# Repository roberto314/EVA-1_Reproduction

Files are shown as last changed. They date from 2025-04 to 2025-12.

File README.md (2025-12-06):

# EVA-1_Reproduction

Recreation of the very rare K-K Systems EVA-1 Display Adapter for the Epson HX-20 Computer
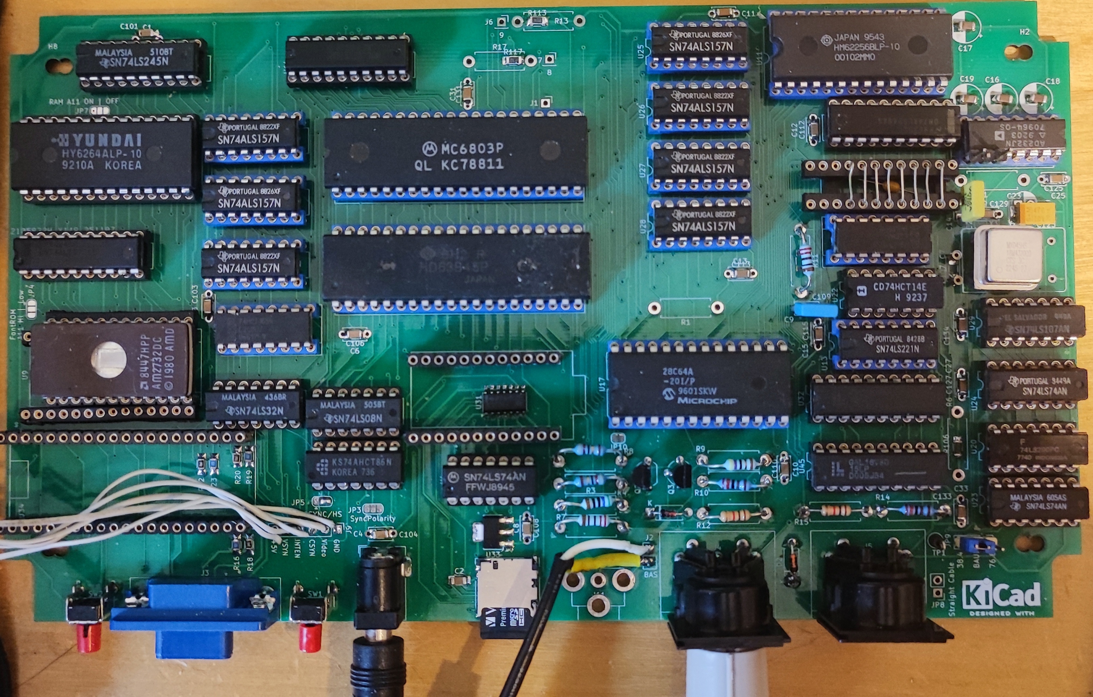
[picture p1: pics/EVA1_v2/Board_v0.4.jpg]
EVA1_v2 Rev.0.4


In the folder disassembly are three versions of the original firmware:

* eva_orig: original firmware 
* eva_enh: enhanced firmware (mostly original)
* eva_ext: extended firmware (8k Text RAM, additional functions)
    - see the .asm file for more comments.

The gal folder contains the equations and .jed file for the GAL.

The monitor folder contains a modified version of Daniel Tufvesson's monitor. This is just for testing.

In the rom folder one can find the original rom and the font rom.

The schematics folder contains different versions of the reverse engineering process.

* EVA1: the original reverse engineered schematic and board (NOT FOR PRODUCTION!)
* EVA1_production: the mostly original EVA1 for production (DRAM does NOT work!)
* EVA86-2: from sources on the internet redrawn schematics of the EVA86 (not complete!)
* EVA1_v2: new version with SRAM as Graphic RAM, Arduino as mass storage and RP2040 for VGA Output.
* EVA1_Frontplatte: a drill template for the Strapubox 5003 case

For the newest Hardware Revision (0.5) use the File "disassembly/eva_ext/rom.bin" for a 28C64 or 27C64 ROM.

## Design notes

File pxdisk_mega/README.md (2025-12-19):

# PFBDK - Arduino Mega simulator of the Epson's Epsp based disk drives

This is my fork of William R. Cooke's PFBDK sketch found at 
http://wrcooke.net/projects/pfbdk/pfbdk.html. PFBDK emulates four floppy drives 
for the Epson PX-4 and PX-8 CP/M portable computers.

Thanks to Robert Offner, the firmware now also supports the Epson HX-20 computer. 

The intend of this project is to add some features to PFBDK making it somewhat more 
convenient to use. The route will be very incremental to keep the basic functionality 
working.

PFBDK on an Arduino Pro Micro in a PETG box

For the Pro Micro a working PCB is created [PDF](PFBDK_promicro.kicad_sch.pdf), 
[KiCAD files](PFBDK_promicro_V1.0.complete.zip).

There are 3D-print files for the case and more pictures on my own page 
at: https://electrickery.nl/comp/tf20/pxdisk/

## HX-20 support

Each HX-20 drive is now a directory on the SD-card; A, B, C and D. The HX-20
requires to files for its Disk-BASIC; BOOT.80 and DBASICnn.SYS. These files 
should be in the root directory of the SD-card (use DBASIC40.SYS for the 16 k HX-20
and DBASIC80.SYS for the HX-20 with the System expansion). 

## Hardware extensions

Both Arduino solutions (there is one for the Mega 2560) support blinking lights 
for the SERIAL line and each (emulated) drive. 

## PFBDK console commands

The first feature is a command line on the debug/console port of the 
Arduino Mega and Pro Micro. The Mega is somewhat more expensive and larger,
but easier to program. For normal operation the two are equal. The usage is now:

	Usage (2.0.0):
 	C                - temp debug for driveNames[][]
 	D                - SD-card root directory
 	H                - this help
 	M[dnnnnnnnn.eee] - mount file nnnnnnnn.eee on drive d
 	Nnnnnnnnn.eee    - create an image file nnnnnnnn.eee
 	P[dw]            - write protect drive d; w=0 RW, w=1 RO
 	R                - temp reset Arduino

Note that most changes made with these tools are not persistent (image 
creation being the exception) and will be lost when switching 
off or resetting the floppy emulator. The default settings are images **D.IMG**, 
**E.IMG**, **F.IMG** and **G.IMG** for the drives and all drives are writable.

### D

The D commands lists only the root directory of the SD card.

### M

The goal of the M-command is to change the images assigned to the 
simulated disk drives D: to G:. 

### N

The N-command creates a new empty image file. It aborts when the image exists. 
This command and the data stored on the image are saved on the SD-card.

### P

The P command emulates the floppy write tabs to write protect the disk.

Another plan was to respect the Read-Only attribute for the image files, 
emulating the floppy write protect, but this attribute is not supported in 
the SDLib library for VFAT disks.

## Control with native PX4 programs

The idea is make most settings controllable from the PX-4/PX-8 with 
custom commands and make settings persistent. After all the PX-4/8 talks to the PFBDK
using the [well documented EPSP protocol](https://electrickery.nl/comp/hx20/doc/SwAsDisAs.pdf), 
and extending the PFBDK firmware with new commands is entirely 
possible. 
For the PX-4 side some user programs can be added, similar in usage as the 
original COPYDISK program. So far only some demos for the
PX-4 are realized. The PX-8 uses another BIOS call, and will be implemented later.
For persistency, no solution is implemented yet, but the simplest
way would probably be to create a CP/M batch file on the RAM disk A: using the 
PF* commands to configure the PFBDK. 

### PFDIR4 - display SD-card root directory

        Usage: PFDIR4 [n]
         n = optional the start directory part 
          (each part is eight entries, ENTER and SPACE gets next part,
           other keys exit program)

### PFMNT4 - mount a SD-card image file to a drive

	  Usage: PFMNT4 [<drive> <name>]
       drive = D, E, F, G.
       name = SD card file image name.

### PFNEW4 - create a new empty image on the SD-card

	  Usage: PFNEW4 <name>'
       name = SD card file image name.

### PFWP4 - manage write protect flag of a drive

      Usage: PFWP4 [<drive> <wp-state>]
       drive = D, E, F, G. 
       wp-state: 0 = read-only, 1 = read/write

## Case

More photo's of the cases and the [3D-printer design files](https://electrickery.nl/comp/tf20/pxdisk/) 
at my main site.

## Extra tech

Creating applications consisting of two computers talking to each other is 
more complex than making just a program. I used this solution to inspect the
traffic between the PX-4 and the PFBDK: https://github.com/electrickery/DualSerialMonitor

fjkraan@electrickery.nl, 2024-12-16

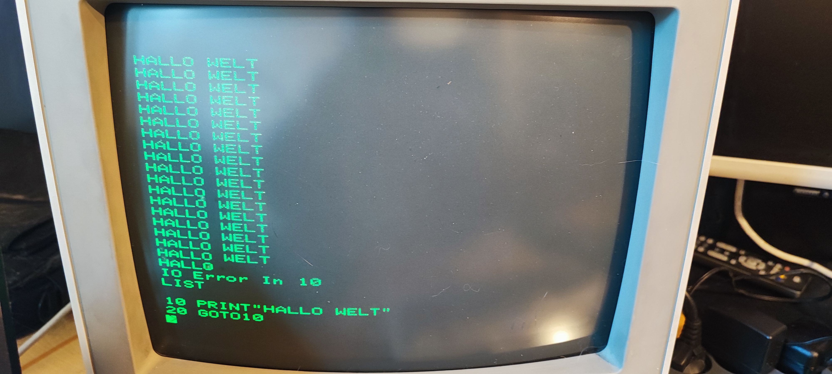
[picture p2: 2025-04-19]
pics/EVA-1_new/EVA_40Z.jpg

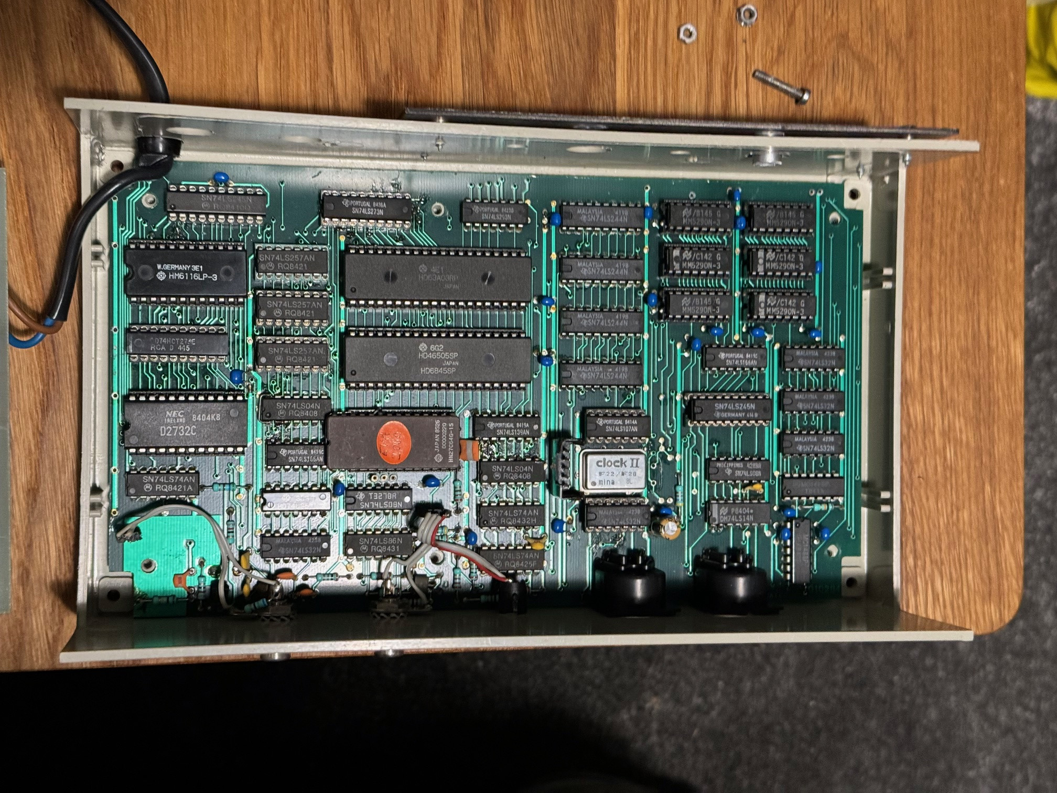
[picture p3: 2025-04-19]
pics/EVA-1_orig/EVA1d.jpg

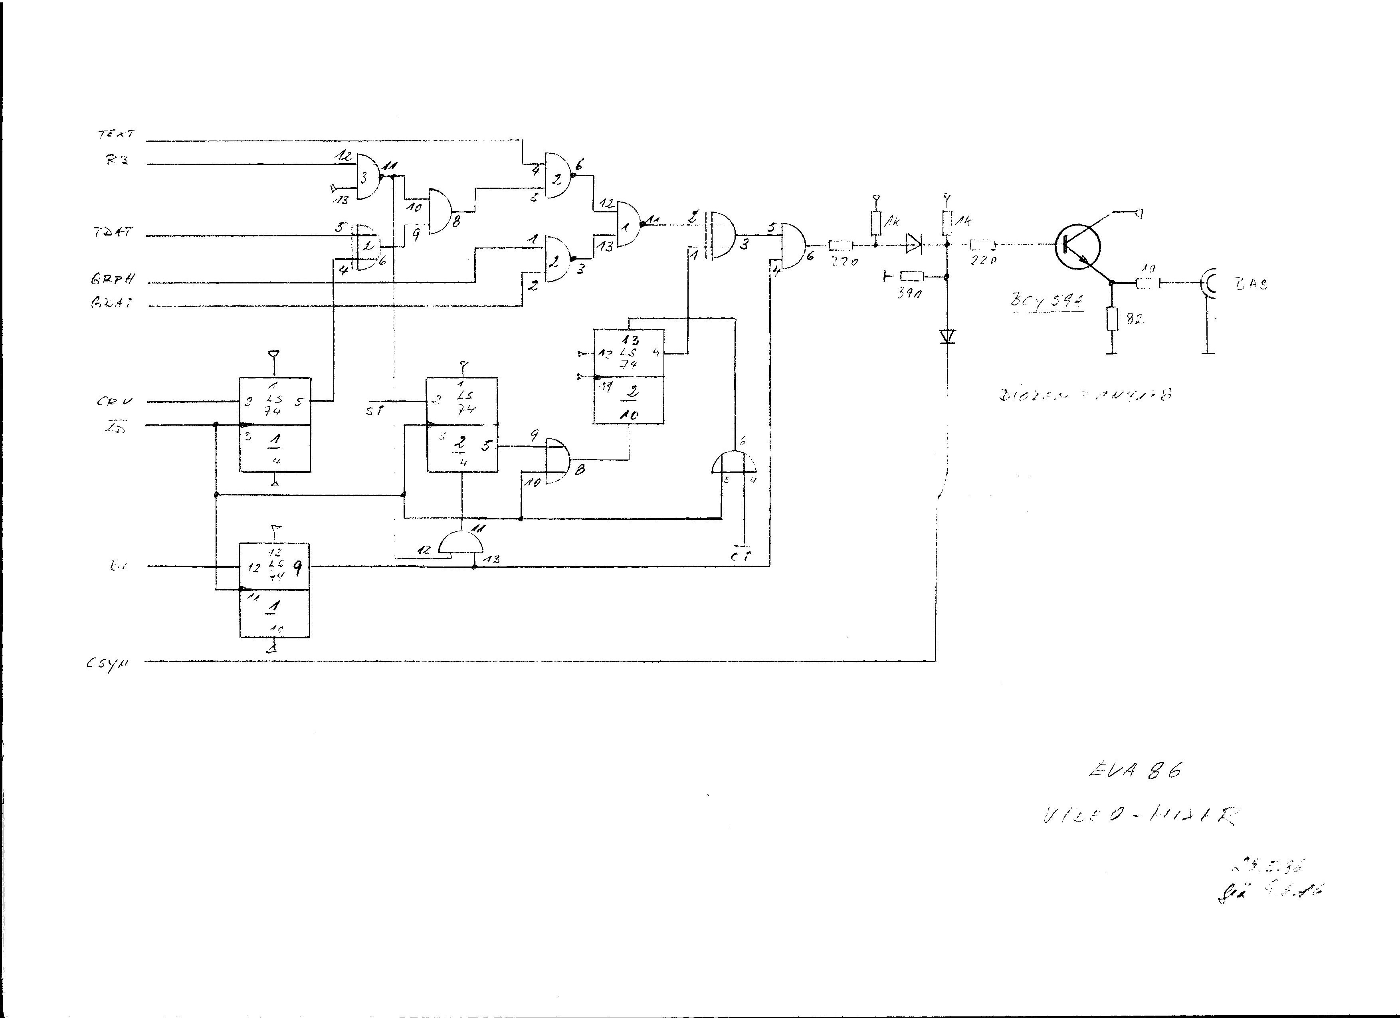
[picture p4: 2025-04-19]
pics/EVA-86/EVA 86-4.jpg

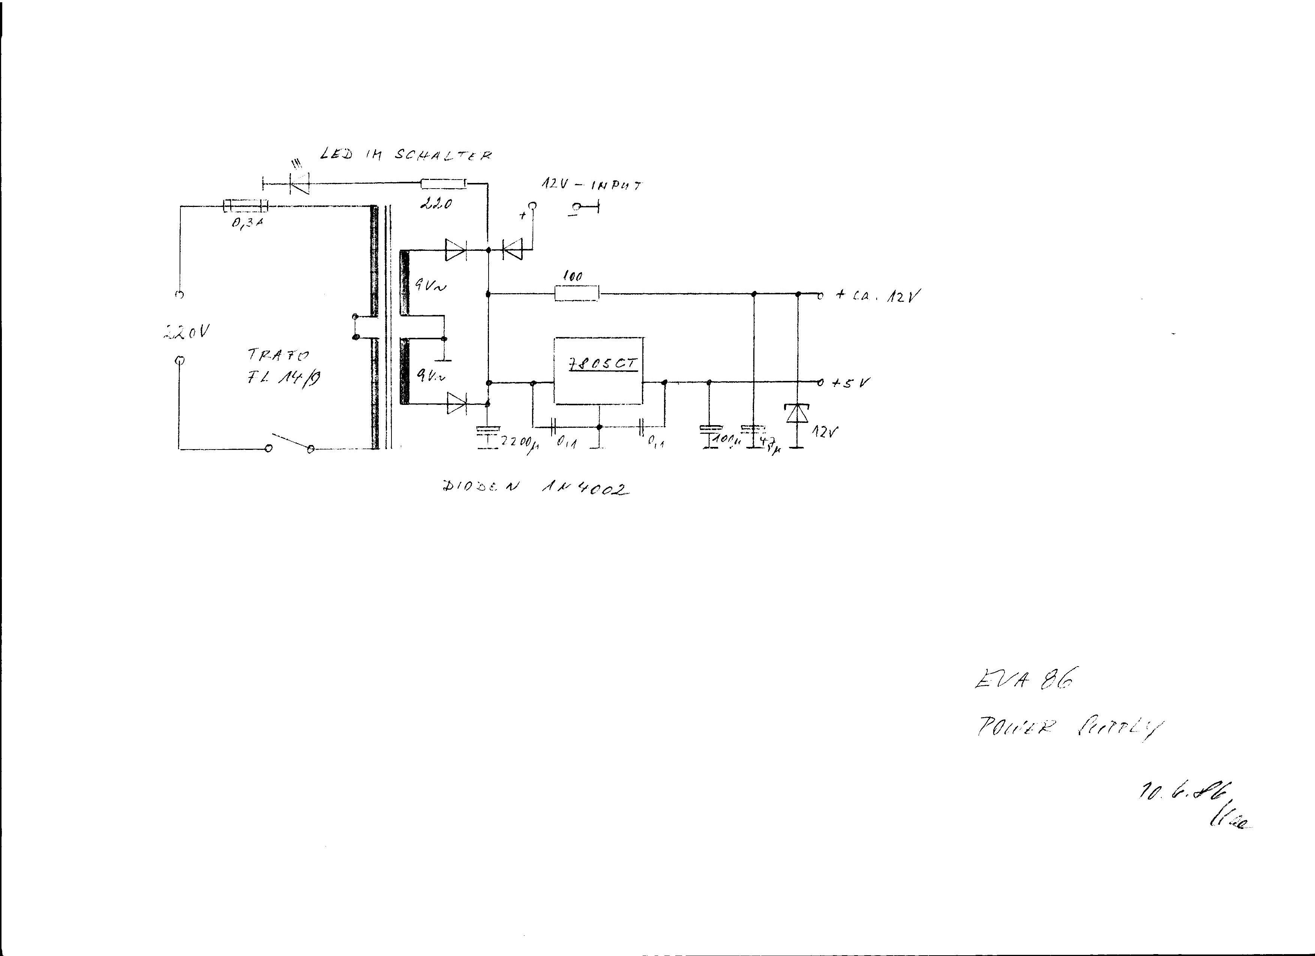
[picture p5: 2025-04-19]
pics/EVA-86/EVA 86 Netz.jpg

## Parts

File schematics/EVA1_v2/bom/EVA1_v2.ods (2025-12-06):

Version: 0.5 | Source | Part# | References | Value | Footprint | Quantity
 |  |  | C101, C103, C104, C106, C108, C110, C111, C112, C113, C115, C125, C127, C129, C131, C133, C134 | 100n | C_1206_3216Metric_Pad1.33x1.80mm_HandSolder | 16 | use either THT or SMD
 |  |  | C1, C3, C4, C6, C8, C10, C11, C12, C13, C15, C25, C27, C29, C31, C33, C34 | 100n | C_Disc_D4.7mm_W2.5mm_P5.00mm | 16 | use either THT or SMD
 |  |  | C16, C17, C18, C19 | 10u/16 | CP_Radial_D6.3mm_P2.50mm | 4 | 1u SMD 1206 X5R or X7R work also
 |  |  | C107 | 47p | C_1206_3216Metric_Pad1.33x1.80mm_HandSolder | 1 | use either THT or SMD
 |  |  | C7 | 47p | C_Disc_D4.7mm_W2.5mm_P5.00mm | 1 | use either THT or SMD
 |  |  | C109 | 1n | C_1206_3216Metric_Pad1.33x1.80mm_HandSolder | 1 | use either THT or SMD
 |  |  | C9 | 1n | C_Disc_D4.7mm_W2.5mm_P5.00mm | 1 | use either THT or SMD
 |  |  | C14 | 4n7 | C_Disc_D4.7mm_W2.5mm_P5.00mm | 1 | use either THT or SMD
 |  |  | C114 | 4n7 | C_1206_3216Metric_Pad1.33x1.80mm_HandSolder | 1 | use either THT or SMD
 |  |  | C123 | 47u/35 | CP_EIA-7343-31_Kemet-D_Pad2.25x2.55mm_HandSolder | 1 | use either THT or SMD
 |  |  | C23 | 47u/35 | CP_Radial_D5.0mm_P2.50mm | 1 | use either THT or SMD
 |  |  | R1, R13, R17, R21 | 4k7 | R_Axial_DIN0411_L9.9mm_D3.6mm_P12.70mm_Horizontal | 4 | use either THT or SMD
 |  |  | R5, R113, R117, R121 | 4k7 | R_1206_3216Metric_Pad1.30x1.75mm_HandSolder | 4 | use either THT or SMD
 |  |  | R106 | 2k2 | R_1206_3216Metric_Pad1.30x1.75mm_HandSolder | 1 | use either THT or SMD
 |  |  | R6 | 2k2 | R_Axial_DIN0411_L9.9mm_D3.6mm_P12.70mm_Horizontal | 1 | use either THT or SMD
 |  |  | R111 | 220E | R_1206_3216Metric_Pad1.30x1.75mm_HandSolder | 1 | use either THT or SMD
 |  |  | R11 | 220E | R_Axial_DIN0411_L9.9mm_D3.6mm_P12.70mm_Horizontal | 1 | use either THT or SMD
 |  |  | R24 | 10k | R_1206_3216Metric_Pad1.30x1.75mm_HandSolder | 1
 |  |  | D2 | 1N4148 | D_A-405_P7.62mm_Horizontal | 1
 |  |  | U6, U7, U8, U25, U26, U27, U28 | 74ALS157 | DIP-16_W7.62mm | 7 | LS is too slow, only tested ALS
 |  |  | U2, U14 | 74HCT573 | DIP-20_W7.62mm | 2
 |  |  | U4, U23, U24 | 74HCT74 | DIP-14_W7.62mm | 3
 |  |  | U5, U36 | 74HCT245 | DIP-20_W7.62mm | 2
 |  |  | U10, U35 | 74HCT165 | DIP-16_W7.62mm_Socket | 2
 |  |  | U32, U45 | GAL16V8 | DIP-20_W7.62mm | 2
 |  |  | U1 | HY6264AxP | DIP-28_W15.24mm | 1
 |  |  | U3 | 27C32 | DIP-24_W15.24mm | 1 | use either 27C32 or 27C64
 |  |  | U9 | 27C64 | DIP-28_W15.24mm | 1 | use either 27C32 or 27C64
 |  |  | U11 | CY62256-70PC | DIP-28_W15.24mm | 1
 |  |  | U12 | 74LS32 | DIP-14_W7.62mm | 1 | HCT also works
 |  |  | U13 | 74LS221 | DIP-16_W7.62mm | 1
 |  |  | U15 | MC6803 | DIP-40_W15.24mm_Socket | 1
 |  |  | U16 | MC6845 | DIP-40_W15.24mm_Socket | 1
 |  |  | U17 | 27C256 or 28C64 | DIP-28_W15.24mm | 1
 |  |  | U18 | 74LS08 | DIP-14_W7.62mm | 1 | HCT also works
 |  |  | U19 | 74LS86 | DIP-14_W7.62mm | 1 | HCT also works
 |  |  | U20 | 74LS290 | DIP-14_W7.62mm | 1
 |  |  | U22 | 74F14 | DIP-14_W7.62mm | 1 | HCT also works
 |  |  | U29 | 74LS107 | DIP-14_W7.62mm | 1
 |  |  | U30 | MAX232 | DIP-16_W7.62mm_Socket | 1
 |  |  | Y2 | 18M432 | Oscillator_DIP-14 | 1 | use either DIP-14 or DIP-8
 |  |  | Y3 | 18M432 | Oscillator_DIP-8 | 1 | use either DIP-14 or DIP-8
 |  |  | JP8 | Straight Cable | PinHeader_1x02_P2.54mm_Vertical | 1
 | ebay |  | J4 | HX20 | DIN-5_Stereo | 1
 | ebay |  | J5 | TF20 | DIN-5_Stereo | 1 | use only if NOT using Arduino
 | mouser |  | J8 | Barrel_Jack_Switch | BarrelJack_Wuerth_6941xx301002 | 1
 |  |  | J9 | Converter | PinHeader_1x06_P2.54mm_Vertical | 1 | Output for EGA,CGA Monitor
 |  |  | JP9 | SCLK*2 | PinHeader_1x03_P2.54mm_Vertical | 1 | Jumper needed! Set to 76k if you modified your HX20 for double speed!
 |  |  | Only for use with Raspberry pi pico and VGA Output
 |  |  | R16, R19, R23 | 845E | R_1206_3216Metric_Pad1.30x1.75mm_HandSolder | 3
 |  |  | R18, R20, R22 | 422E | R_1206_3216Metric_Pad1.30x1.75mm_HandSolder | 3
 | mouser | 506-1-1825027-4 | SW1, SW2 | PX_CLK_BTN, AUTO_ADJUST | SW_Tactile_SPST_Angled_PTS645Vx83-2LFS | 2
 | mouser | 771-74LVC08ADQ100118 | U37 | 74LVC08AD | SOIC-14_3.9x8.7mm_P1.27mm | 1
 |  |  | U34 | RaspberryPi_Pico | raspberry_pi_pico | 1
 | ebay | - | J3 | DE15_Plug_HighDensity_MountingHoles | DSUB-15-HD_Female_Horizontal_P2.29x1.90mm_EdgePinOffset3.03mm_Housed_MountingHolesOffset4.94mm | 1
 |  |  | Only for Mass Storage with Arduino
 | mouser | 798-DM3D-SF | J10 | Micro_SD_Card_Det2 | microSD_HC_Hirose_DM3D-SF | 1
 | mouser | 926-LM1117MPX3.3NOPB | U33 | AMS1117-3.3 | SOT-223-3_TabPin2 | 1
 | ebay |  | U21 | Sparkfun_Pro_Micro | Sparkfun_Pro_Micro (DOESN’T WORK – USE ARDUINO MEGA!) | 1
 | mouser | 771-74LVC08ADQ100118 | U31 | 74LVC08AD | SOIC-14_3.9x8.7mm_P1.27mm | 1
 |  |  | C2, C5 | 100n | C_1206_3216Metric_Pad1.33x1.80mm_HandSolder | 2
 | mouser | 241-BAT54AW_R1_00001 | D3 | BAT54AW | SOT-23_Handsoldering | 1 | if NOT using Arduino connect Pin 1 and 3 of D3
 |  |  | only for Video Output (BAS)
 | mouser | 534-938 | J11 | Conn_Coaxial | Keystone_RCA-Jack | 1
 |  |  | J2 | BAS | PinHeader_1x02_P2.54mm_Vertical | 1
 |  |  | R4, R8 | 82E | R_Axial_DIN0411_L9.9mm_D3.6mm_P12.70mm_Horizontal | 2
 |  |  | Q2, Q3 | BC337 | TO-92_Wide | 2
 |  |  | R12, R15 | 1k | R_Axial_DIN0411_L9.9mm_D3.6mm_P12.70mm_Horizontal | 2
 |  |  | D1 | 1N4148 | D_A-405_P7.62mm_Horizontal | 1
 |  |  | R10, R14 | 2k2 | R_Axial_DIN0411_L9.9mm_D3.6mm_P12.70mm_Horizontal | 2
 |  |  | R3 | 560E | R_Axial_DIN0411_L9.9mm_D3.6mm_P12.70mm_Horizontal | 1
 |  |  | R9 | 47E | R_Axial_DIN0411_L9.9mm_D3.6mm_P12.70mm_Horizontal | 1
 |  |  | R7 | 220E | R_Axial_DIN0411_L9.9mm_D3.6mm_P12.70mm_Horizontal | 1
 |  |  | Sockets
 |  |  |  |  | DIP-14_W7.62mm | 9
 |  |  |  |  | DIP-16_W7.62mm | 11
 |  |  |  |  | DIP-20_W7.62mm | 6
 |  |  |  |  | DIP-24_W15.24mm | (1) | only for 2732 Font ROM (Default)
 |  |  |  |  | DIP-28_W15.24mm | (3), 4 | 4 if using 2764 Font ROM, else 3
 |  |  |  |  | DIP-40_W15.24mm_Socket | 2
 |  |  | Case
 | Segor electronics | Strapubox 5003 |  |  |  | 1

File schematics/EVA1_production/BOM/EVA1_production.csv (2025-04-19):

Id | Designator | Footprint | Quantity | Designation | Supplier and ref
1 | U26,U25,U28,U27 | DIP-20_W7.62mm | 4 | 74LS244
2 | U21 | DIP-16_W7.62mm | 1 | 74LS139
3 | U31,U43,U44,U42,U12 | DIP-14_W7.62mm | 5 | 74LS32
4 | U4,U24,U23 | DIP-14_W7.62mm | 3 | 74LS74
5 | C23 | CP_Radial_D5.0mm_P2.50mm | 1 | 47u/35
6 | C14,C2,C5,C4,C9,C30 | C_Disc_D4.7mm_W2.5mm_P5.00mm | 6 | ?
7 | R3 | R_Axial_DIN0411_L9.9mm_D3.6mm_P12.70mm_Horizontal | 1 | 560E
8 | C15,C33,C29,C25,C1,C22,C8,C27,C11,C3,C10,C13,C12,C6,C31,C34 | C_Disc_D4.7mm_W2.5mm_P5.00mm | 16 | 100n
9 | U40,U41,U33,U32,U39,U34 | DIP-16_W7.62mm_Socket | 6 | 4164
10 | U36,U5 | DIP-20_W7.62mm | 2 | 74LS245
11 | R10,R5,R14,R6 | R_Axial_DIN0411_L9.9mm_D3.6mm_P12.70mm_Horizontal | 4 | 2k2
12 | R4,R8 | R_Axial_DIN0411_L9.9mm_D3.6mm_P12.70mm_Horizontal | 2 | 82E
13 | Y2 | Oscillator_DIP-14 | 1 | 19M66
14 | U22 | DIP-14_W7.62mm | 1 | 74LS04
15 | Q3,Q2 | TO-92_Wide | 2 | BC337
16 | U2,U14 | DIP-20_W7.62mm | 2 | 74LS573
17 | U38 | DIP-14_W7.62mm | 1 | 74LS14
18 | R7,R16,R11 | R_Axial_DIN0411_L9.9mm_D3.6mm_P12.70mm_Horizontal | 3 | 220E
19 | U35,U10 | DIP-16_W7.62mm | 2 | 74LS166
20 | U8,U6,U7 | DIP-16_W7.62mm | 3 | 74LS157
21 | U9,U17 | DIP-28_W15.24mm | 2 | 27C64
22 | J2 | PinHeader_1x03_P2.54mm_Vertical | 1 | BAS
23 | J6 | PinSocket_1x01_P2.54mm_Vertical | 1 | 9
24 | J5 | DIN-5_Stereo | 1 | TF20
25 | R9 | R_Axial_DIN0411_L9.9mm_D3.6mm_P12.70mm_Horizontal | 1 | 47E
26 | U45 | DIP-20_W7.62mm | 1 | GAL16V8
27 | J8 | BarrelJack_Wuerth_6941xx301002 | 1 | Barrel_Jack_Switch
28 | D2,D1 | D_A-405_P7.62mm_Horizontal | 2 | 1N4148
29 | U19 | DIP-14_W7.62mm | 1 | 74LS86
30 | R12,R15 | R_Axial_DIN0411_L9.9mm_D3.6mm_P12.70mm_Horizontal | 2 | 1k
31 | U1 | DIP-28_W15.24mm | 1 | HY6264AxP
32 | R1,R2 | R_Axial_DIN0411_L9.9mm_D3.6mm_P12.70mm_Horizontal | 2 | ?
33 | Y3 | Oscillator_DIP-8 | 1 | 19M66
34 | C18,C16,C17 | CP_Radial_D6.3mm_P2.50mm | 3 | 10u/16
35 | TP1,TP2 | TestPoint_Loop_D1.80mm_Drill1.0mm_Beaded | 2 | TestPoint
36 | J3 | PinHeader_1x05_P2.54mm_Vertical | 1 | Power
37 | J1 | PinSocket_1x01_P2.54mm_Vertical | 1 | 17
38 | U37,U18 | DIP-14_W7.62mm | 2 | 74LS08
39 | J4 | DIN-5_Stereo | 1 | HX20
40 | U20 | DIP-14_W7.62mm | 1 | 74LS290
41 | U13 | DIP-16_W7.62mm | 1 | 74LS221
42 | U16 | DIP-40_W15.24mm_Socket | 1 | MC6845
43 | U29 | DIP-14_W7.62mm | 1 | 74LS107
44 | J7 | PinSocket_1x01_P2.54mm_Vertical | 1 | 8
45 | U15 | DIP-40_W15.24mm_Socket | 1 | MC6803
46 | R21 | R_Axial_DIN0411_L9.9mm_D3.6mm_P12.70mm_Horizontal | 1 | 4k7
47 | J9 | PinHeader_1x04_P2.54mm_Vertical | 1 | MDA
48 | C7 | C_Disc_D4.7mm_W2.5mm_P5.00mm | 1 | 47p
49 | U3 | DIP-24_W15.24mm | 1 | 27C32
50 | U30 | DIP-16_W7.62mm_Socket | 1 | MAX232

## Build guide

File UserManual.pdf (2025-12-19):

EVA-1 from KK System – Reproduction

User Manual

v1.1

### 1 Building

### 1.1 SMD or THT Components

There are several components with dual footprint (SMD or THT). The Reference for SMD is THT+100. So Capacitor C1 is a THT part but if one wants a SMD part it is C101. The same goes for some Resistors (R13, R113, R17, R117,…). It should be clear to assemble only one component!

### 1.2 Floppy Extension

The floppy extension uses an Arduino Mega 2560. Unfortunately the Arduino Pro micro doesn’t work, it crashes while sending the boot extension. The firmware is PFBDK with the HX20 Extension. (PFBDK Github Site). (https://github.com/electrickery/pxdisk_mega) There are some parts which don’t need assembly when not using this feature.

### 1.3 VGA Output

There is space for a Raspberry Pi Pico (RP2040) on the board. It converts the CGA Type Video into a VGA Compatible Signal. The firmware on the Pi Pico is MCE Blaster (MCE Blaster Github Site). (https://github.com/scrapcomputing/MCEBlaster)

There is no connection by default to the Pi Pico, one must connect J13 to J12 according to the wanted colour since the Output of the EVA1 is only monochrome.

### 1.4 CPU

There is the possibility to use two different CPUs. Default is a MC6803R, which is the 1MHz Variant in a DIP-40 Package. The MC68A03 and MC68B03 are the 1.5MHz and 2MHz Types. Although the CPU runs at slightly over 1.5MHz (1.54 to be precise) all tested CPUs worked. The MC68B03R is the preferred Version. If one has a Hitachi CPU (HD63x03R) there is a Solder Jumper on the back (JP6) which needs to be open since the HD6303 needs Pin 2 open while the MC6803 needs it on GND (see datasheet).

R17 and R13 are important and must be placed! They select the CPU Mode.

### 1.5 Firmware ROM

The firware is only 4kB, so a 2732 would be enough but since the 2732 has only 24pins and is difficult to program compared to a 2764 or 2864 the pcb has an 28pin socket which can support any EPROM from 64kbit to 512 kbit. For the prototype an AT28C64 EEPROM has been used. For this type JP10 has to be open (default). For an EPROM JP10 should be closed. With a 27C256 one can connect a switch to Pin 27 (A14) and GND and use two different firmware variants.

### 1.6 Font ROM

The Font ROM uses a 2732 EPROM. There is an alternate Socket for a 2764 with a slightly different pinout. There is however no modified Font ROM file for a 2764 at the moment.

### 1.7 GALs

There are two GALs on the PCB (U32 and U45). The .jed files are in the GAL folder. The TL866 can program the gals just fine.

### 1.8 HD6845

Only the Hitachi HD6845 is supported. The MC6845 has the ouptut shifted to the left.

### 1.9 Clock

There are two footprints for the 18.432 MHz Clock. One DIP-8 and one DIP-14. Use whatever. No Crystals are supported only MXO Type Oscillator.

1.10 74 Series Variants

The prototype is tested with LS and HCT variants and for the most parts both are fine except for the ‘157 multiplexer. Only the 74 ALS 157 have been tested.

### 1.11 Various Jumpers

JP8 can be closed if only a “straight” cable is at hand. In this case use the right DIN-5 connector. An external Floppy (TF-10 for example) can NOT be used! The internal Arduino emulator would work fine.

JP9 is for double speed operation. One can “overclock” the HX-20 with a faster crystal (two 4.9152 MHz needed). In this case all communication takes place at double speed (38400 Baud * 2). The Arduino firmware has to be changed as well!

### 1.12 Case

The case is a Strapubox 5003. Supplier is Segor electronics.

### 2 Connection

### 2.1 Serial connection:

The connection between HX-20 and EVA-1 must be with a 5-pin DIN “crossover” cable. Pinout of the cable:

Pin HX20 | Pin EVA1 | Function | Comment
1 | 1 | GND
2 | 3 | PTX Out (Transmit Data)

3 | 2 | PRX In (Receive Data)
4 | 5 | Pout Out (Transmit Mode) not used
5 | 4 | Pin In (Receive Mode) | not used

The cable must be connected to the left socket. The right socket is for a portable floppydrive.

In the new Version of the Board is a jumper (JP8). When this Jumper is closed, a “straight 5-pin DIN cable can be used. This cable must be connected to the right socket. In this case a portable floppydrive cannot be used!

### 2.2 Monitor Connection:

There are two monitor connections, a Video connector (FBAS, SCART compatible) and a CGA Type connection (15.6kHz, 50 Hz) for a CGA compatible monitor.

### 3 Usage

After connection the monitor and power the startup screen should show. Here are the most common shortcuts and also the first entry for the HX-20.

### 3.1 Control characters:

CTRL+E | Deletes from Cursor to the end of the line
CTRL+F | Toggle Inverse (only for “special” special characters)
CTRL+G | Toggle bright (only for “special” special characters)
CTRL+N | “special” character from now on. This writes every character with Bit 7 set. It won’t
show unless one “activates” them with CTRL+F or CTRL+G
CTRL+I | Horizontal TAB
CTRL+P | Move Window up. The TEXTRAM Chip on the Reproduction board is twice as big.
It can store 50 Lines with 80 characters. Moves only the Window of the screen buffer.
CTRL+Q | Move Window down. Moves only the Window of the screen buffer.
CTRL+T | Restores the original screen buffer window.
CTRL+S | Jumps into monitor program. In the new EPROM is a monitor program (MC3
monitor from Daniel Tufvesson). After CTRL+S connect a terminal (38400Baud) and press Enter.
CTRL+V | Cursor visible
CTRL+W | Cursor invisible
CTRL+Z | Deletes from Cursor to the end of the screen
CTRL+0 | Show test picture (works only in SCREEN 1,1 Mode)
CTRL+1 | toggle Text ON/OFF
CTRL+2 | toggle Inverted screen
CTRL+3 | switch to 32 characters / Line
CTRL+4 | switch to 40 characters / Line
CTRL+5 | toggle Cursor BLINK
CTRL+6 | Clear graphics screen (GCLS)
CTRL+7 | switch to 72 characters / Line
CTRL+8 | switch to 80 characters / Line
CTRL+9 | toggle character set (the second character set has only minor differences – see
Reference Manual Appendix F)

### 4 EPSP Functions

The EVA-1 handles the following EPSP Functions:

$88 | SCRNSIZE READ SCREEN SIZE (L.C)
$89 | SCRNSIZE GET PHYSICAL SCREEN SIZE (L.C)
$8C | GCRSRPOS GET CURSOR POSITION
$8F | GETPOINT GET POINT ON THE DISPLAY (L.C)
$91 | READLINE READ THE EXTEND OF CURRENT LINE (L.C)
$92 | WRITECHAR WRITE ONE CHARACTER TO VIRTUAL SCREEN (L.C)
$93 | SETDISPMOD SET DISPLAY MODE (C)
$97 | READCHAR READ CHARACTERS FROM VS. (L,C)
$98 | WRITECHAR WRITE ONE CHARACTER TO VS AND GET EXTEND OF NEW
CURSOR POSITION.(L,C)
$C2 | SETCRSR | SET CURSOR POSITION ON THE VIRTUAL SCREEN (L.C)
$C5 | SRLISTFLG SET LIST FLAG (L.C)
$C6 | SRLISTFLG RESET LIST FLAG (L.C)
$C7 | SETPOINT SET POINT TO DISPLAY (L.C)
$C8 | DRAWLINE DRAW LINE TO DISPLAY (L.C)
$C9 | SETLINETERM SET LINE TERMINATE POSITION (L.C)
$CA | CLRGRAPH CLEAR THE GRAPHICS SCREEN. (L.C)
$CB | DISABLED SET SCRLUPSPEED (C)
$CF | DISABLED COLOR SET SELECT (C)
$D4 | DISABLED ?

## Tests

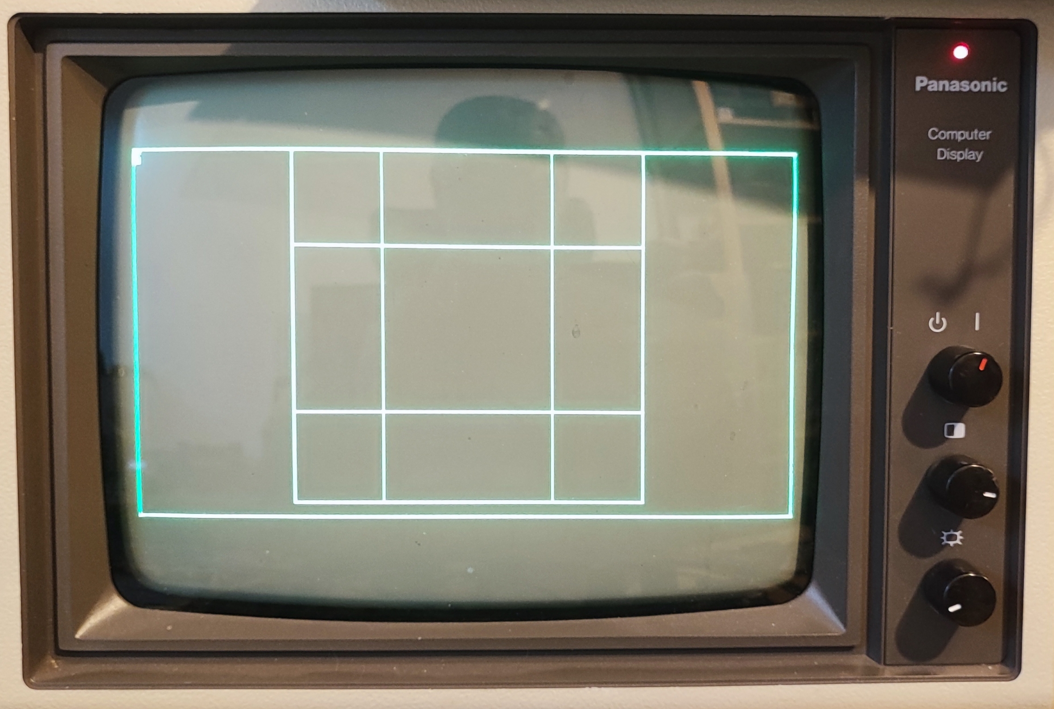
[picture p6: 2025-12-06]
pics/EVA1_v2/CRT_Test.jpg

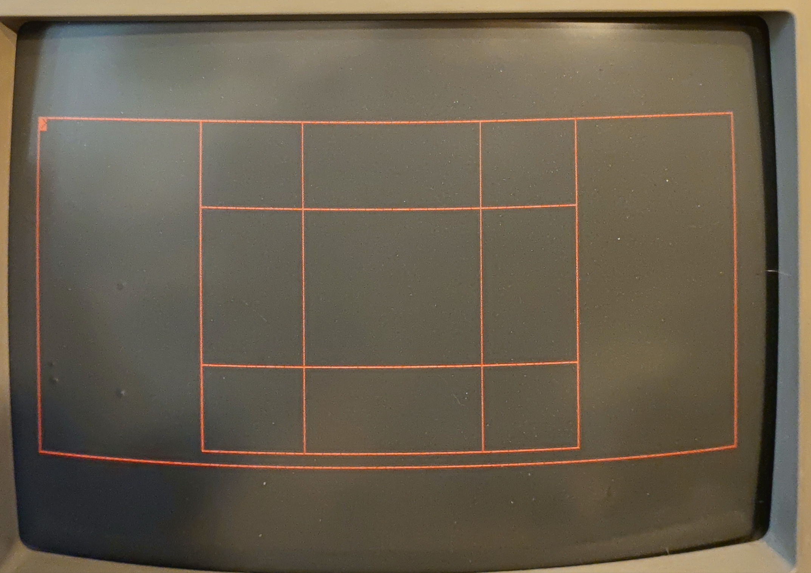
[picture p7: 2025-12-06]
pics/EVA1_v2/CGA_Test.jpg

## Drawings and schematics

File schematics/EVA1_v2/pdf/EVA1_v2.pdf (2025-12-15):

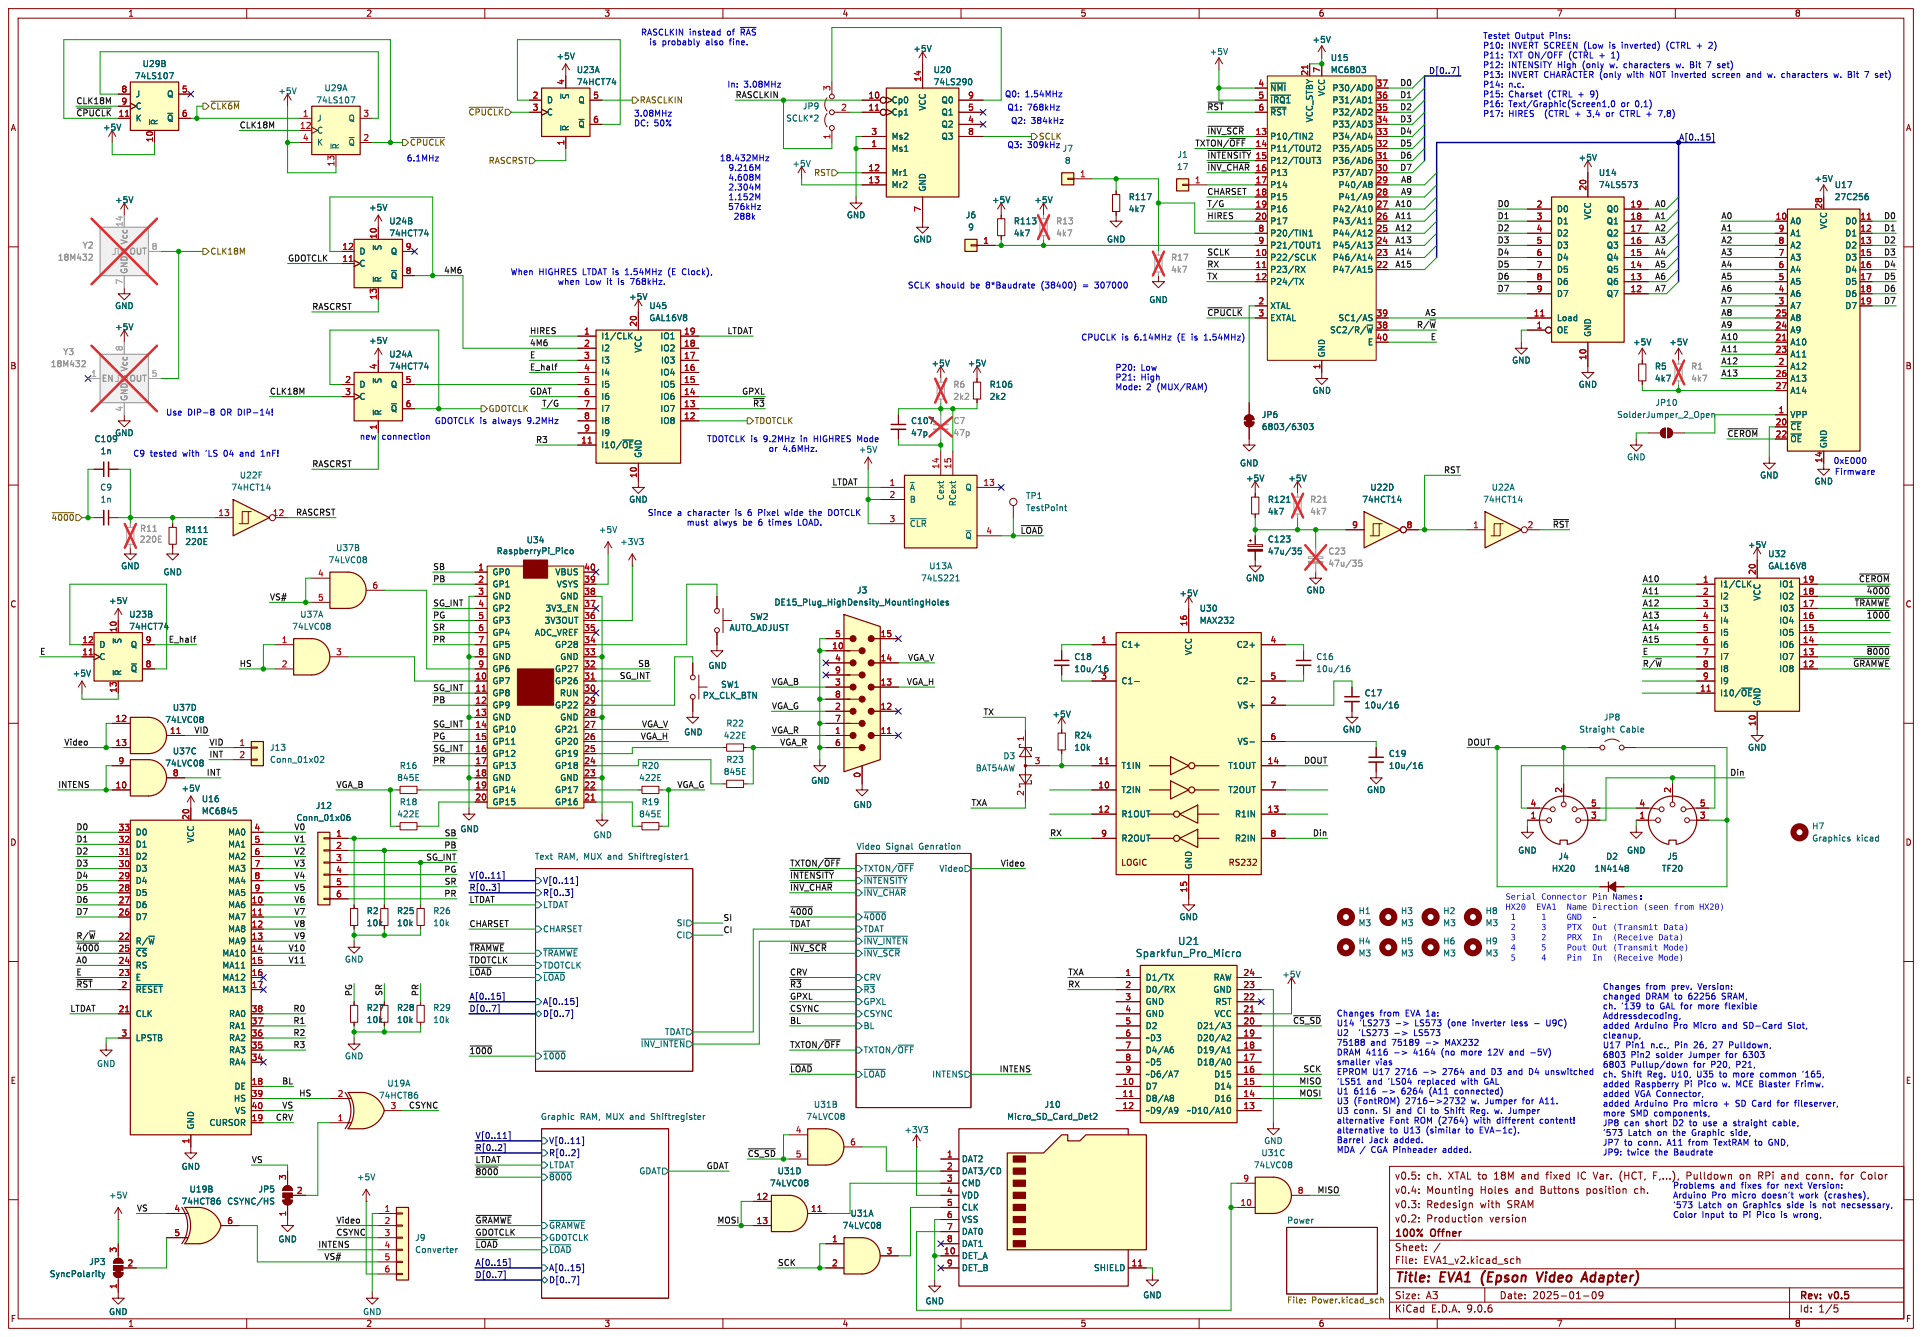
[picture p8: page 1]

RASCLKIN instead of ~{RAS}

P21: High Mode: 2 (MUX/RAM)

TDOTCLK
3V3OUT 36 ADC_VREF 35 GP28 34 GND 33 GP27 32 GP26 31 RUN 30 GP22 29 GND 28 GP21 27 GP20 26 GP19 25 GP18 24 GND 23 GP17 22 GP16 21 U34 RaspberryPi_Pico

1 MA0 4 MA1 5 MA2 6 MA3 7 MA4 8 MA5 9 MA6 10 MA7 11 MA8 12 MA9 13 MA10 14 MA11 15 MA12 16 MA13 17 RA0 38 RA1 37 RA2 36 RA3 35 RA4 34 DE 18 HS 39 VS 40 CURSOR 19 U16 MC6845

1 MA0 4 MA1 5 MA2 6 MA3 7 MA4 8 MA5 9 MA6 10 MA7 11 MA8 12 MA9 13 MA10 14 MA11 15 MA12 16 MA13 17 RA0 38 RA1 37 RA2 36 RA3 35 RA4 34 DE 18 HS 39 VS 40 CURSOR 19
10k GND

~{GRAMWE} LTDAT Graphic RAM, MUX and Shiftregister

'573 Latch on Graphics side is not necsessary, Color Input to Pi Pico is wrong,

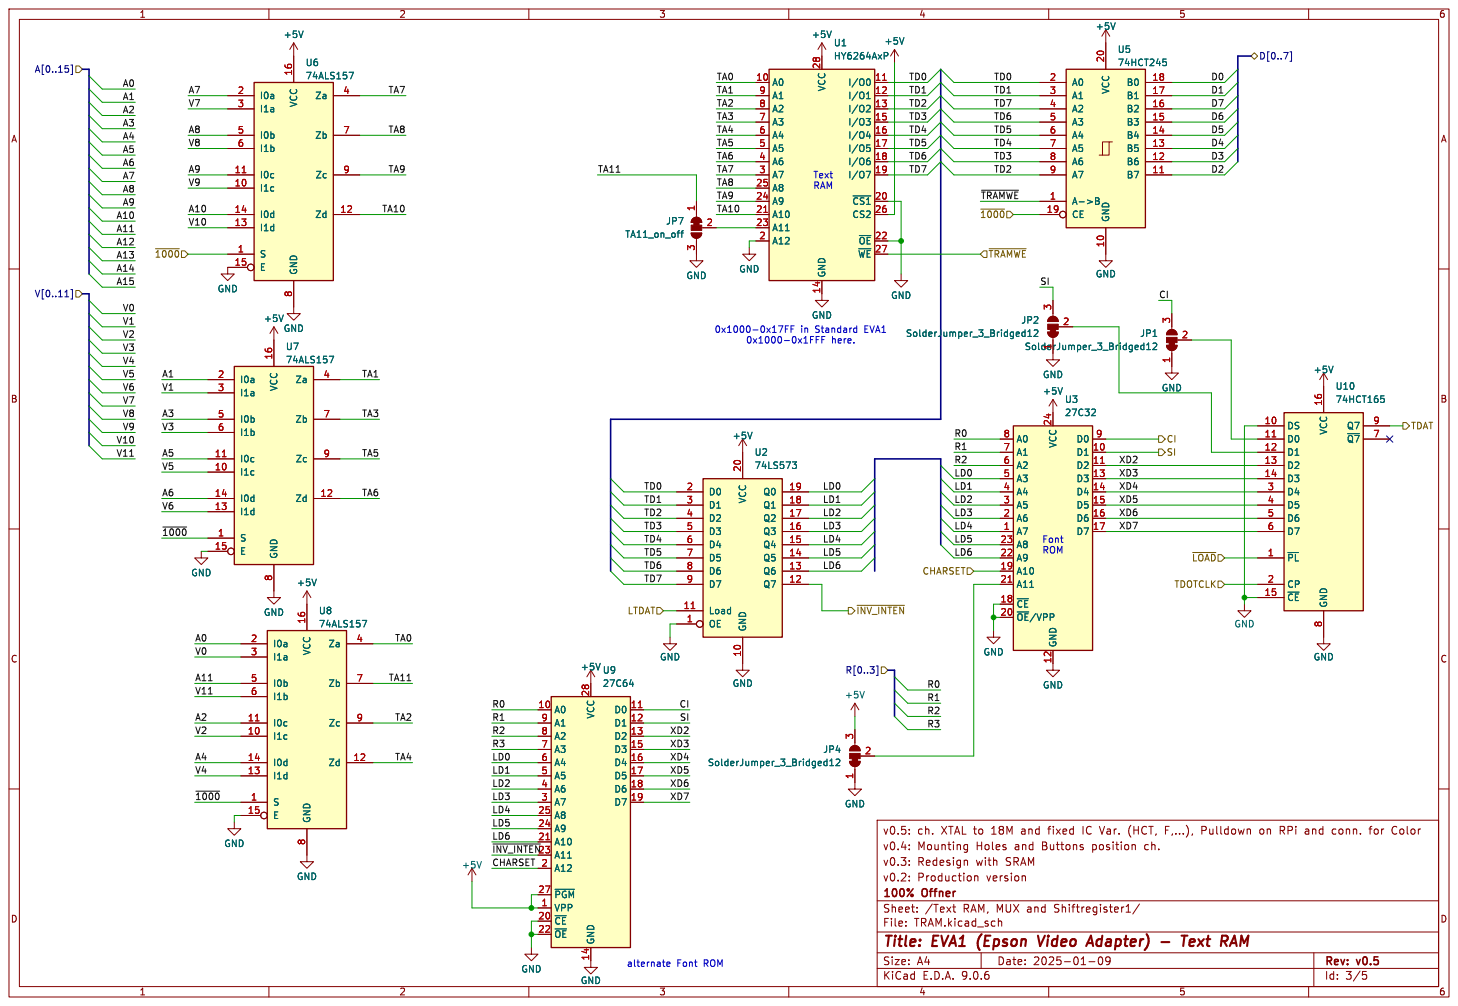
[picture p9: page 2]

74ALS157

8 Za 4 Zb 7 Zc 9 Zd 12 GND

3 GND GND GND GND GND

8 Za 4 Zb 7 Zc 9 Zd 12 +5V GND GND

Id: 3/5 Title: EVA1 (Epson Video Adapter) - Text RAM

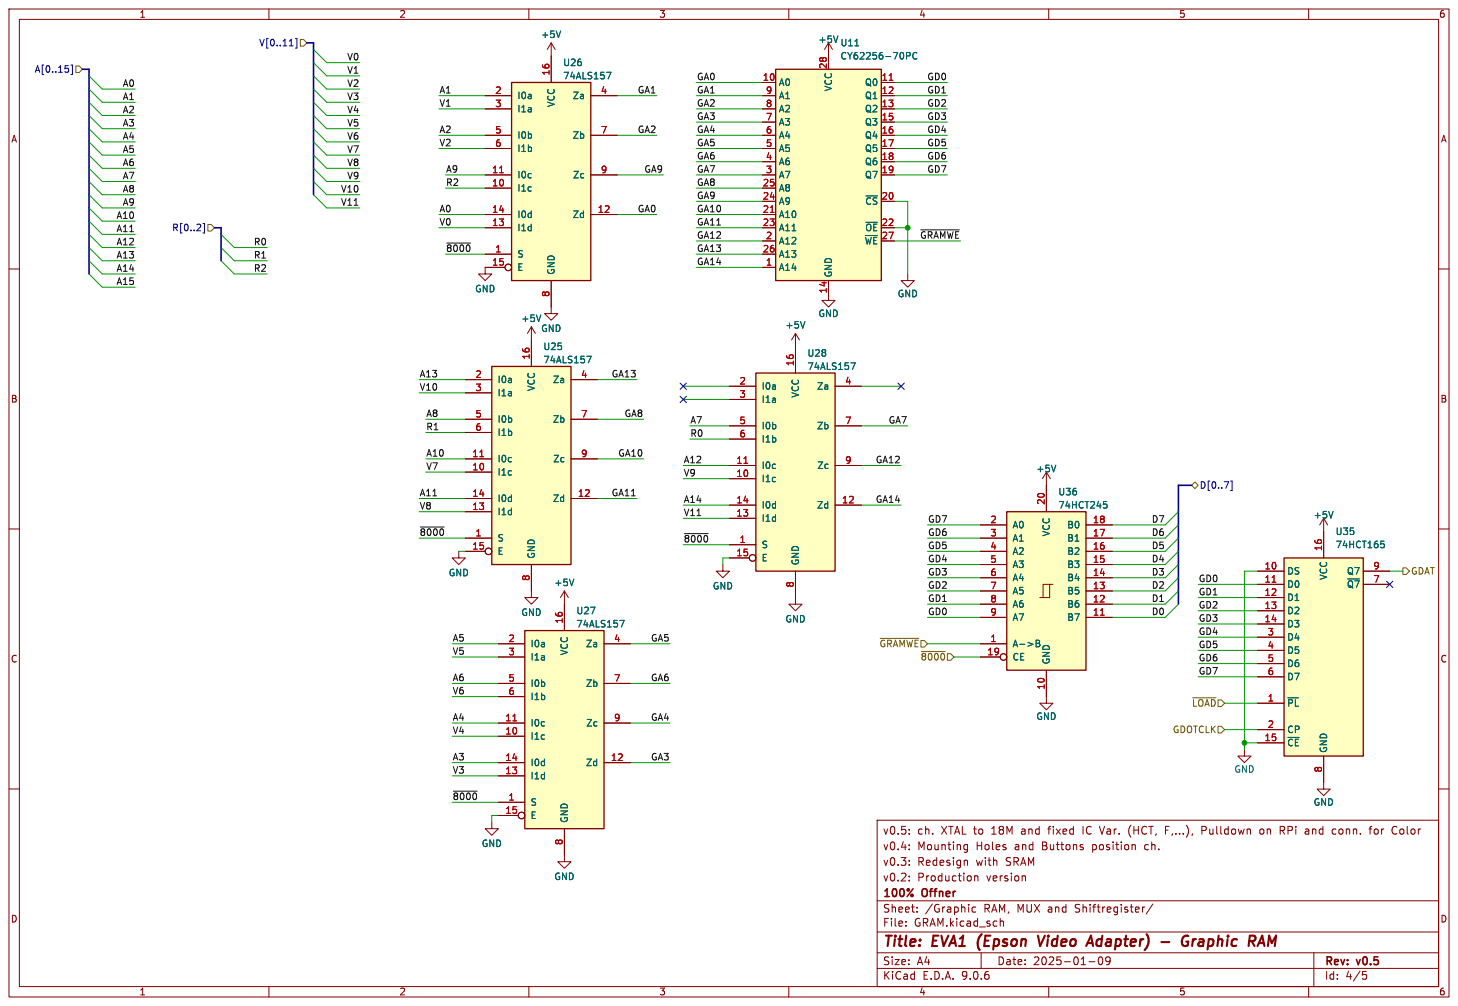
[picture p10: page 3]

Id: 4/5 Title: EVA1 (Epson Video Adapter) - Graphic RAM

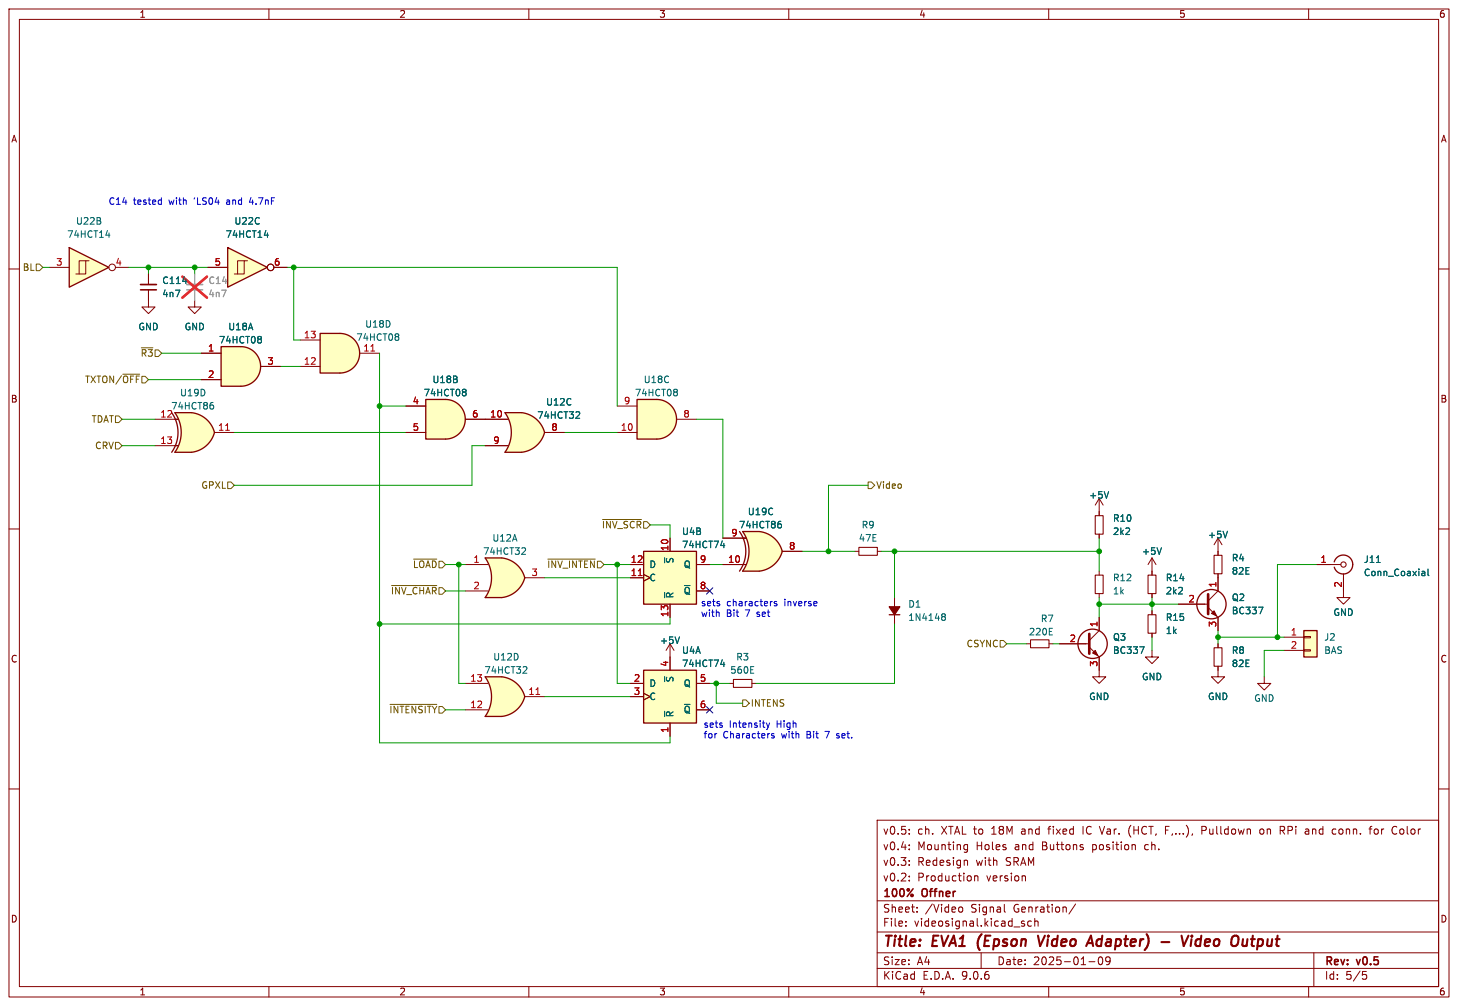
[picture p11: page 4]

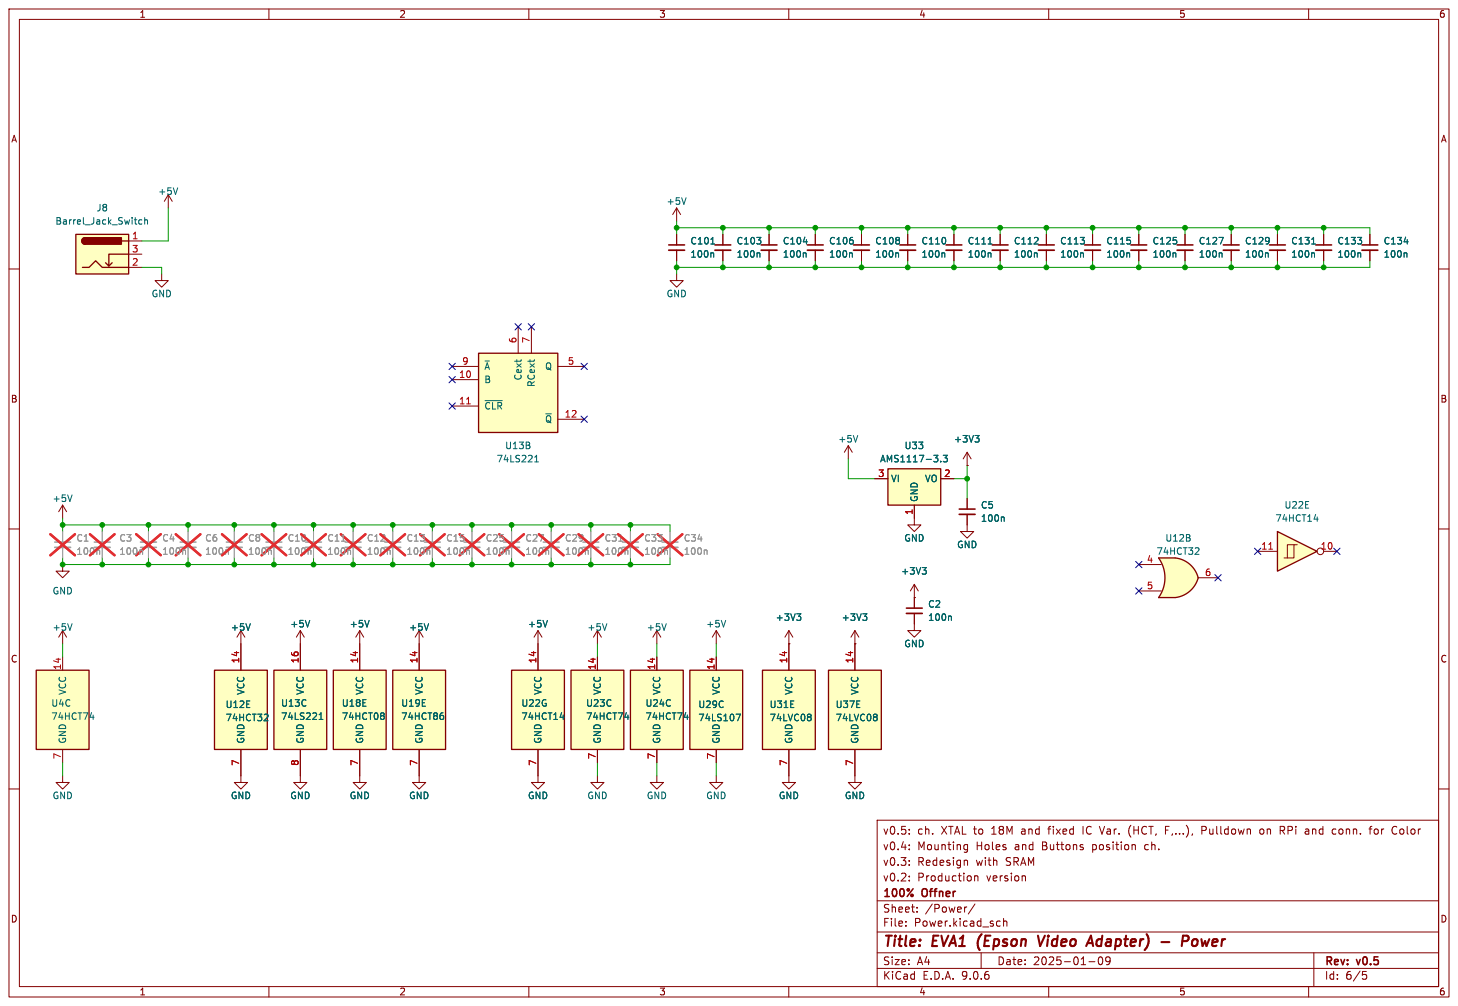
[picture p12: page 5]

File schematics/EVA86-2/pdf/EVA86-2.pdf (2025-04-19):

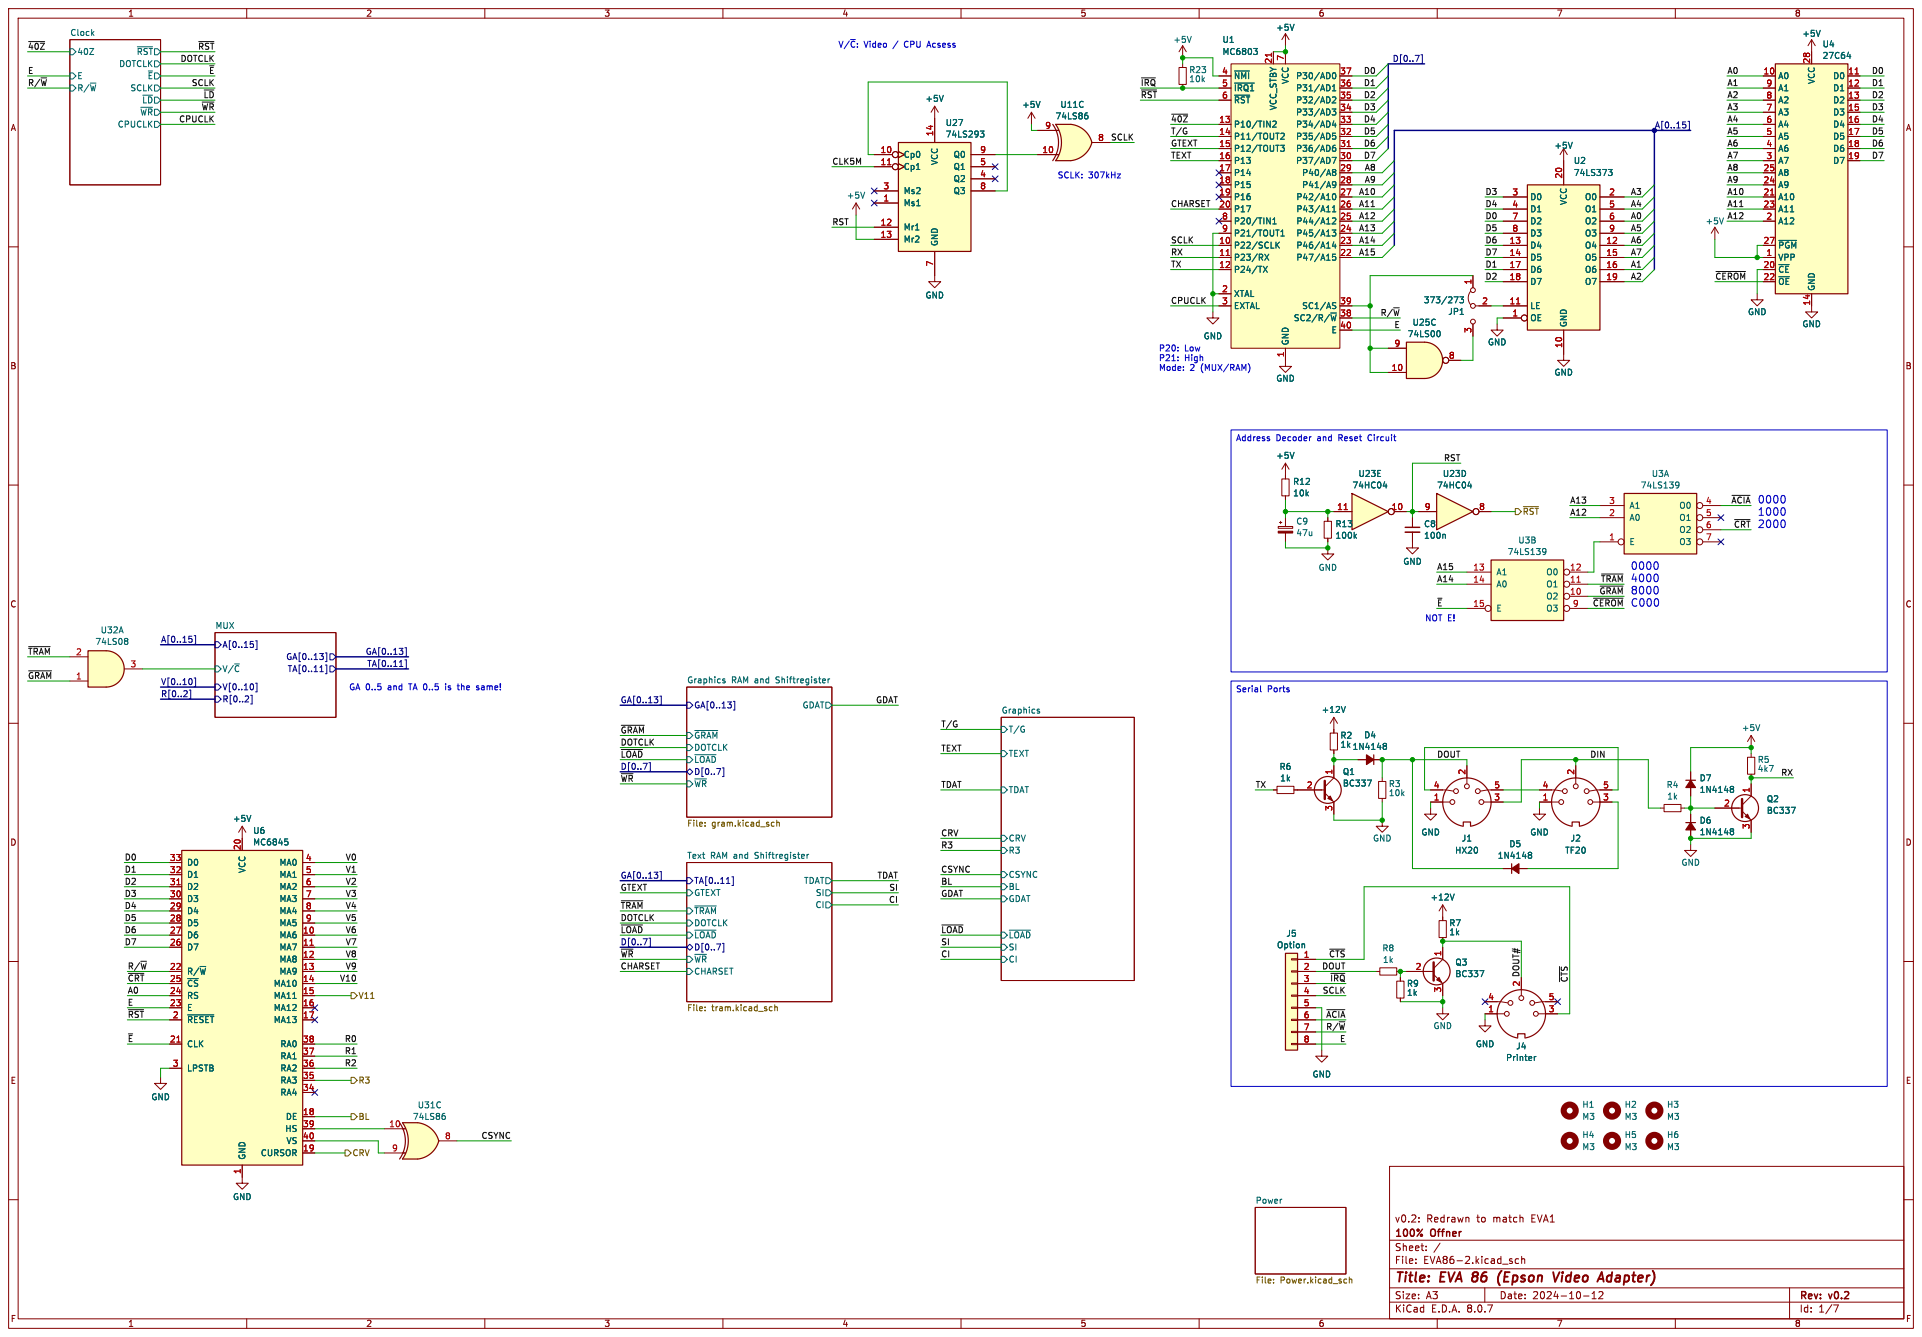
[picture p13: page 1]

1 P22/SCLK 10 P23/RX 11 P24/TX 12 P10/TIN2 13 P11/TOUT2 14 P12/TOUT3 15 P13 16 P14 17 P15 18 P16 19 XTAL 2 P17 20 VCC_STBY 21 P47/A15 22 P46/A14 23 P45/A13 24 P44/A12 25 P43/A11 26 P42/A10 27 P41/A9 28 P40/A8 29 EXTAL 3 P37/AD7 30 P36/AD6 31 P35/AD5 32 P34/AD4 33 P33/AD3 34 P32/AD2 35 P31/AD1 36 P30/AD0 37 SC2/R/~{W}38 SC1/AS 39 ~{NMI} 4 E

P21: High Mode: 2 (MUX/RAM) GA 0..5 and TA 0..5 is the same!

Graphics RAM and Shiftregister File: gram.kicad_sch

~{LOAD} GDAT CI CSYNC Graphics

1 MA6 10 MA7 11 MA8 12 MA9 13 MA10 14 MA11 15 MA12 16 MA13 17 DE 18 CURSOR 19 ~{RESET} 2 VCC 20 CLK 21 R/~{W} 22 E

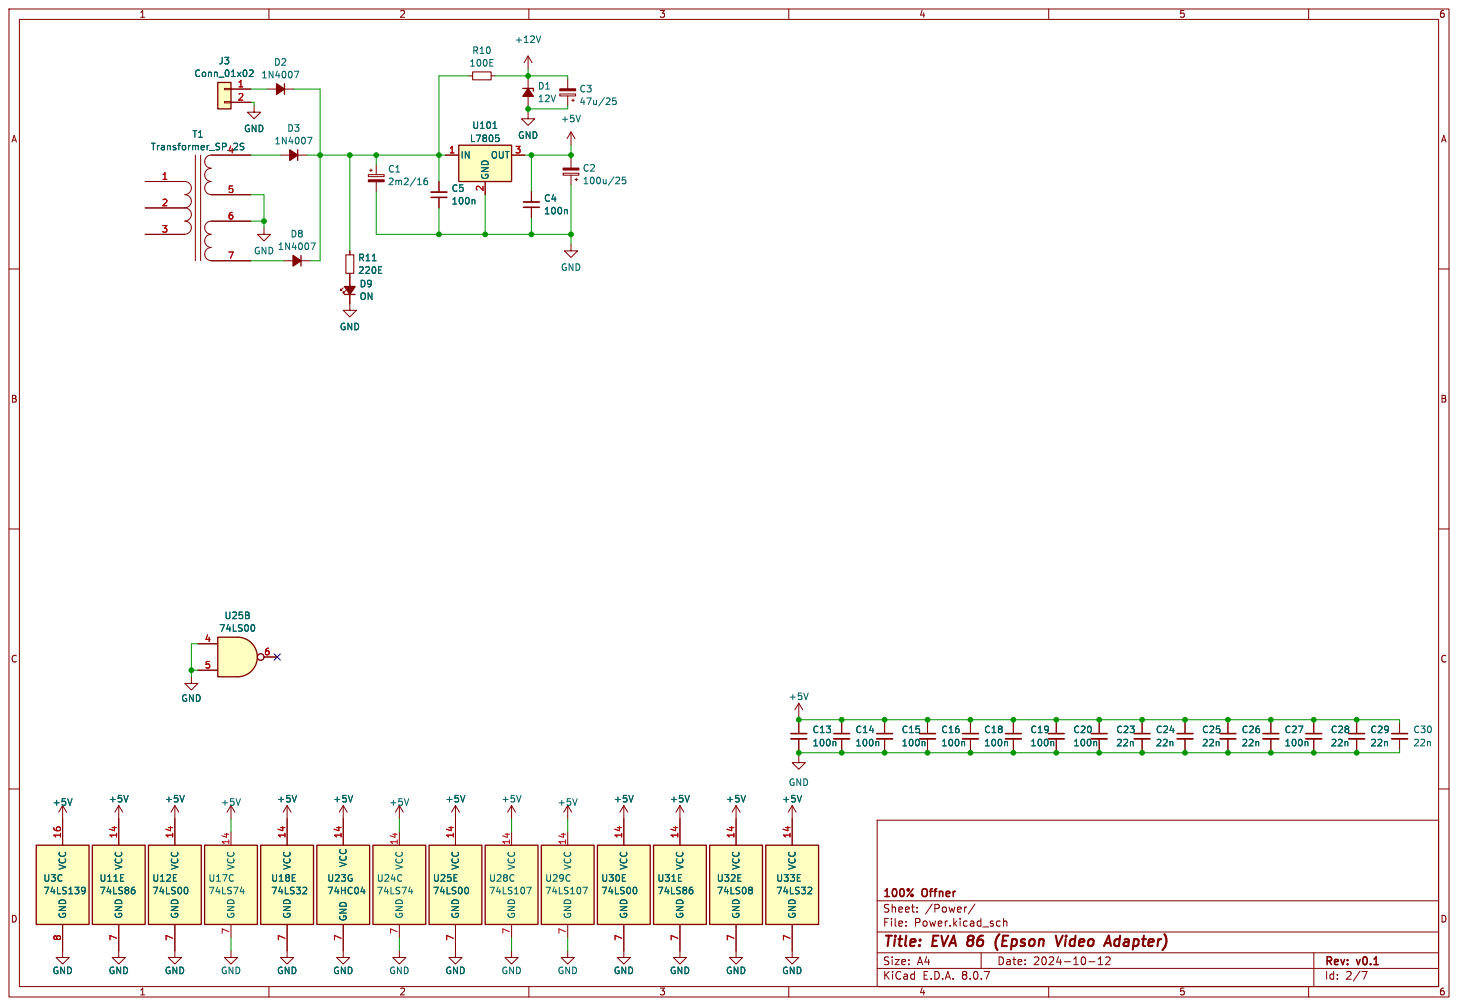
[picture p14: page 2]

Id: 2/7 Title: EVA 86 (Epson Video Adapter) File: Power.kicad_sch Sheet: /Power/ 100% Offner VCC 14 GND

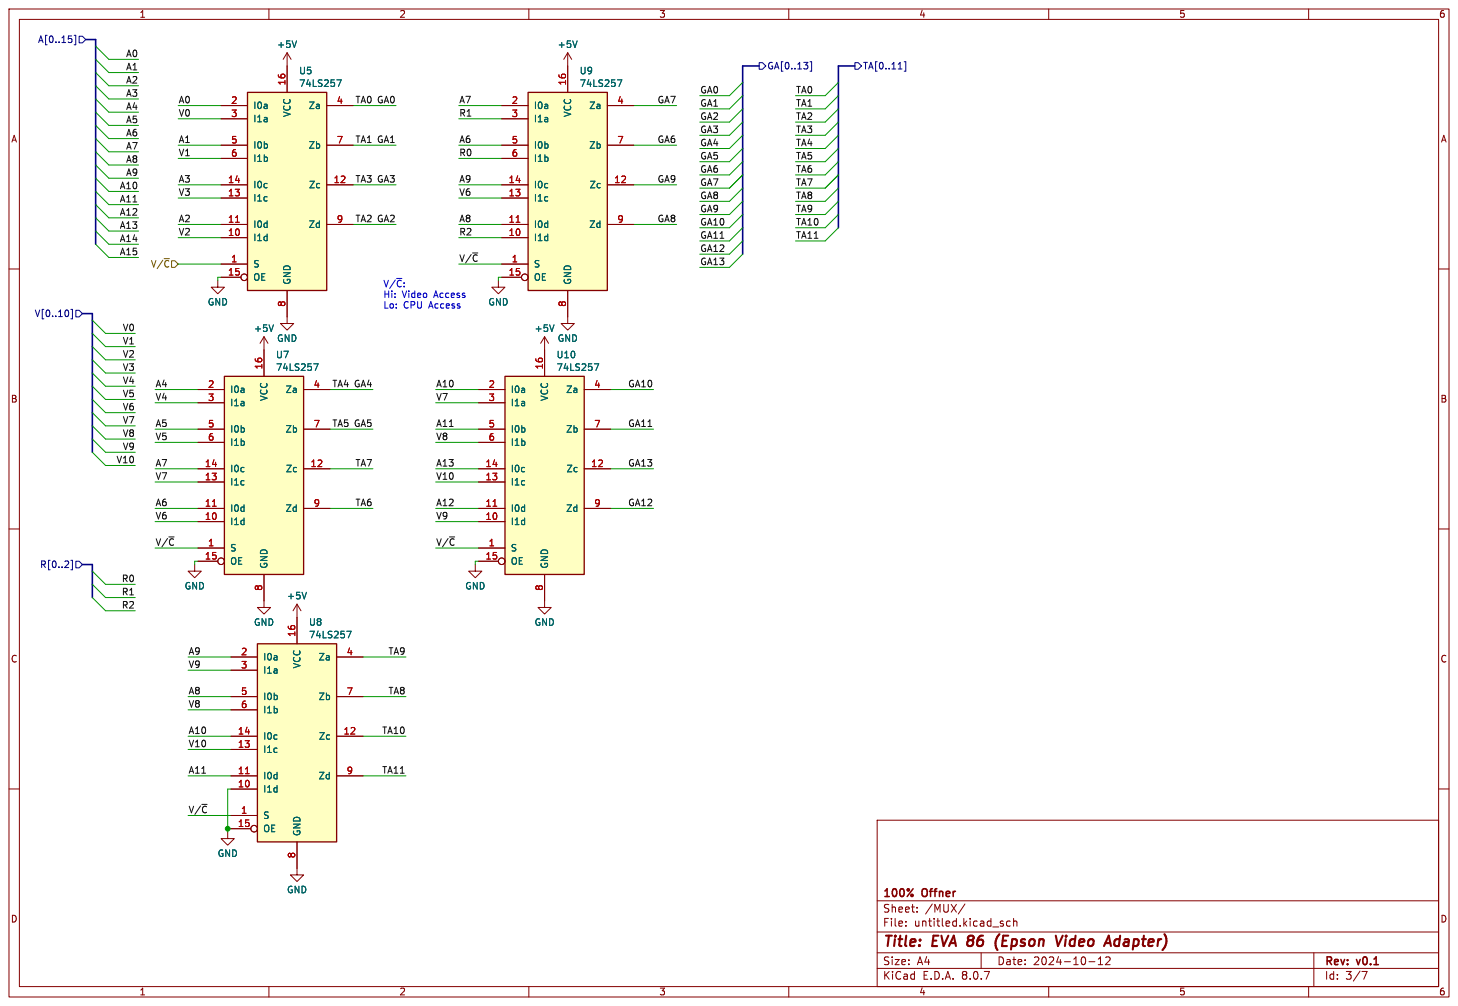
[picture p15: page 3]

Id: 3/7 Title: EVA 86 (Epson Video Adapter) File: untitled.kicad_sch Sheet: /MUX/ 100% Offner

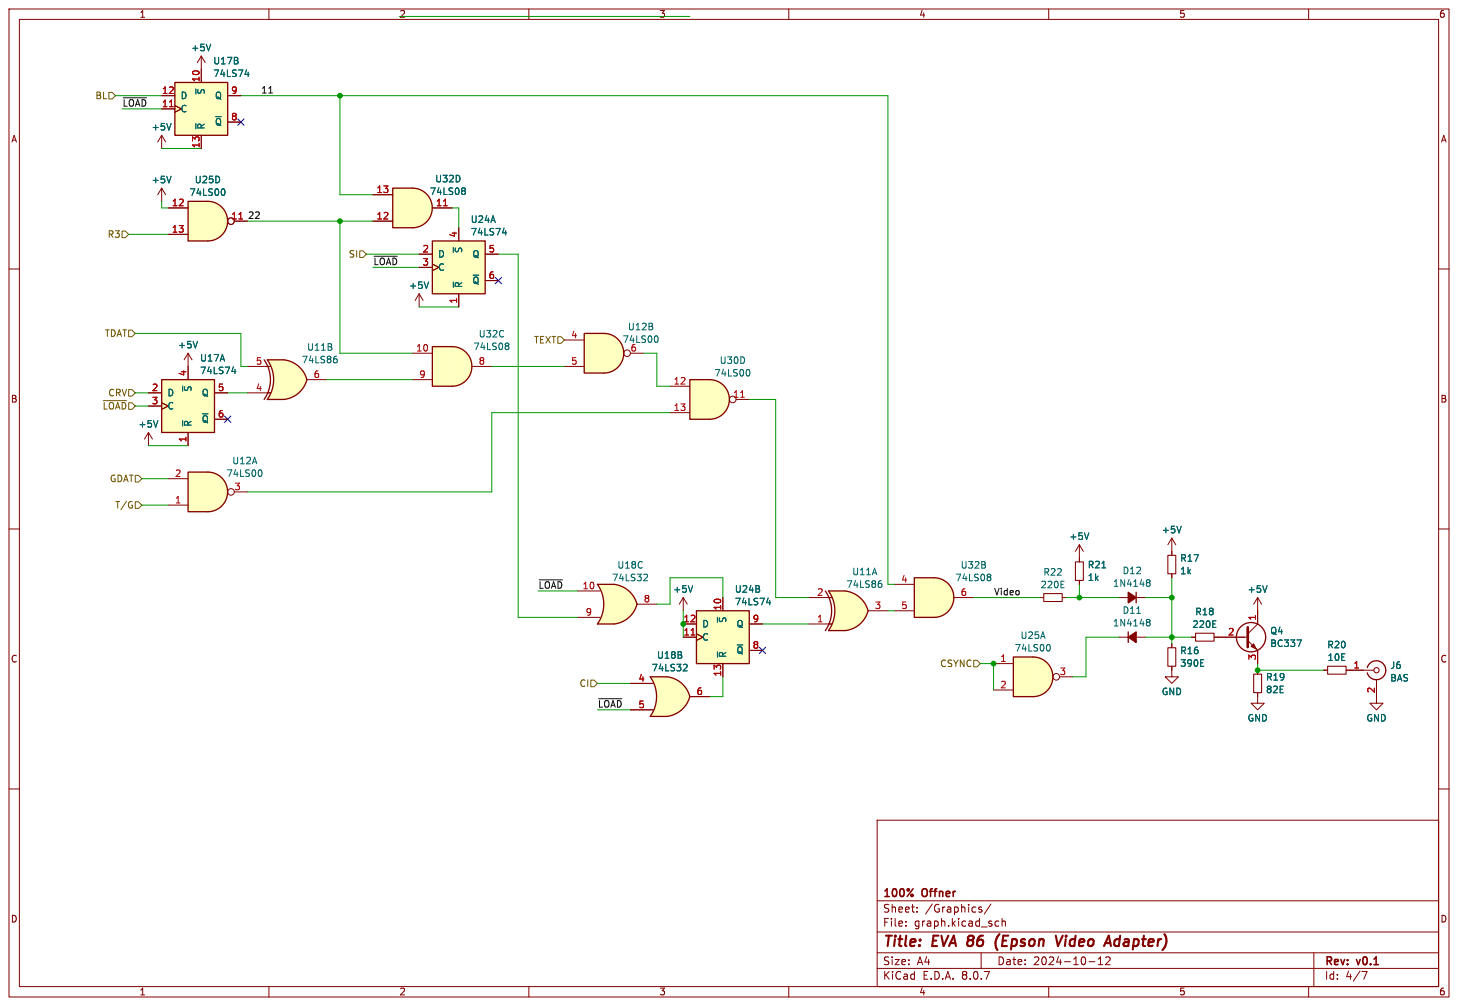
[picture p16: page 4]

Id: 4/7 Title: EVA 86 (Epson Video Adapter) File: graph.kicad_sch Sheet: /Graphics/ 100% Offner

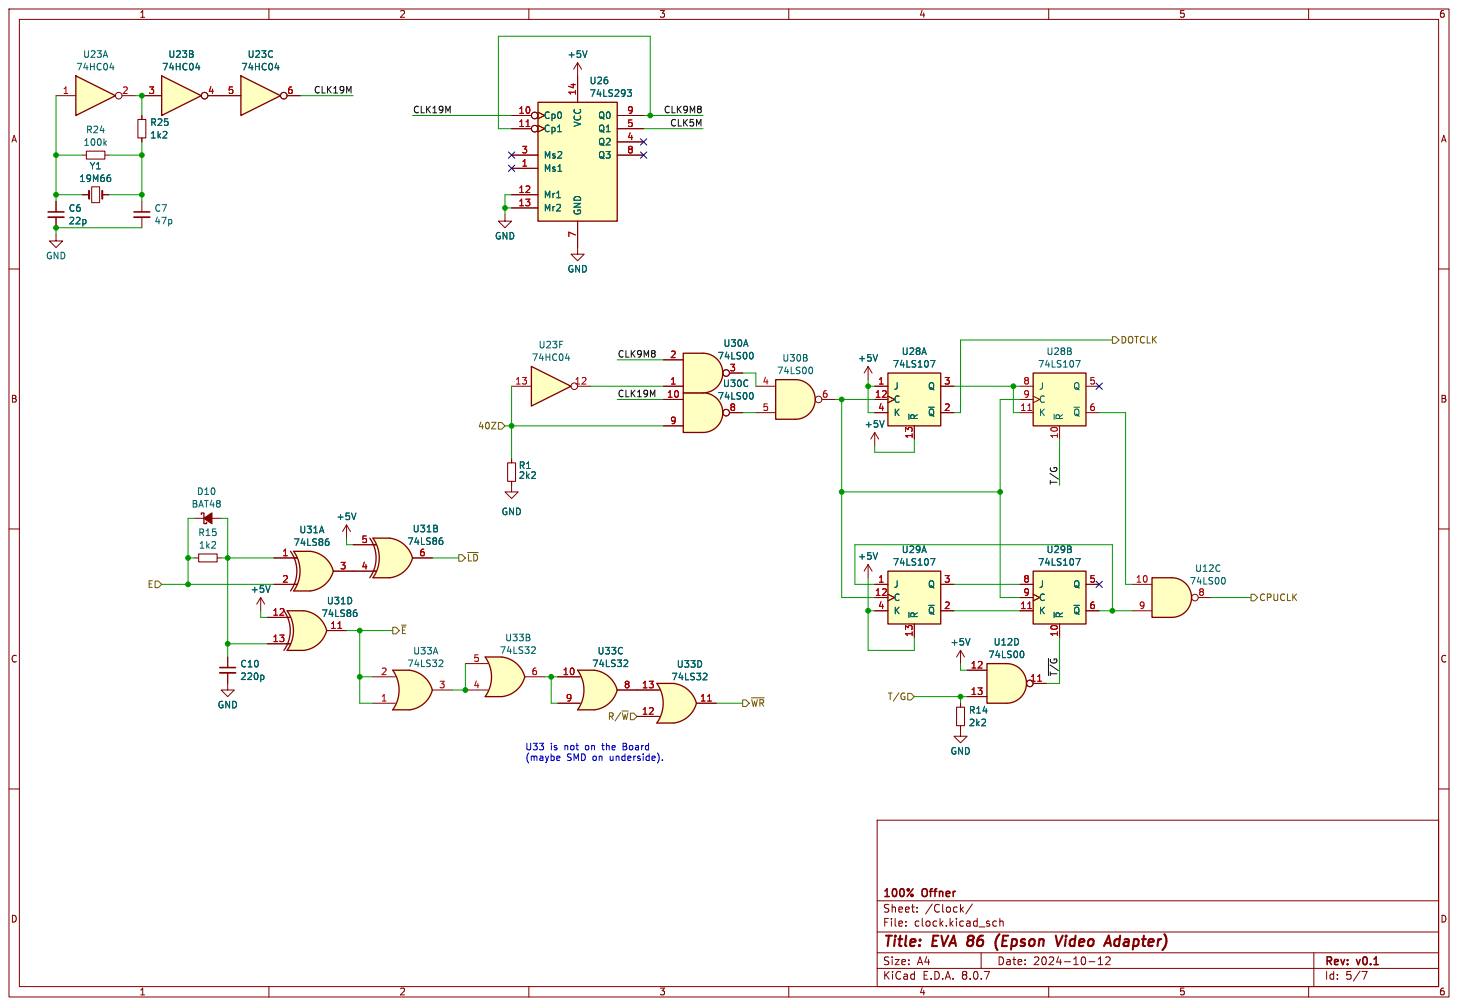
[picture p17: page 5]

Id: 5/7 Title: EVA 86 (Epson Video Adapter) File: clock.kicad_sch Sheet: /Clock/ 100% Offner 11

U33 is not on the Board

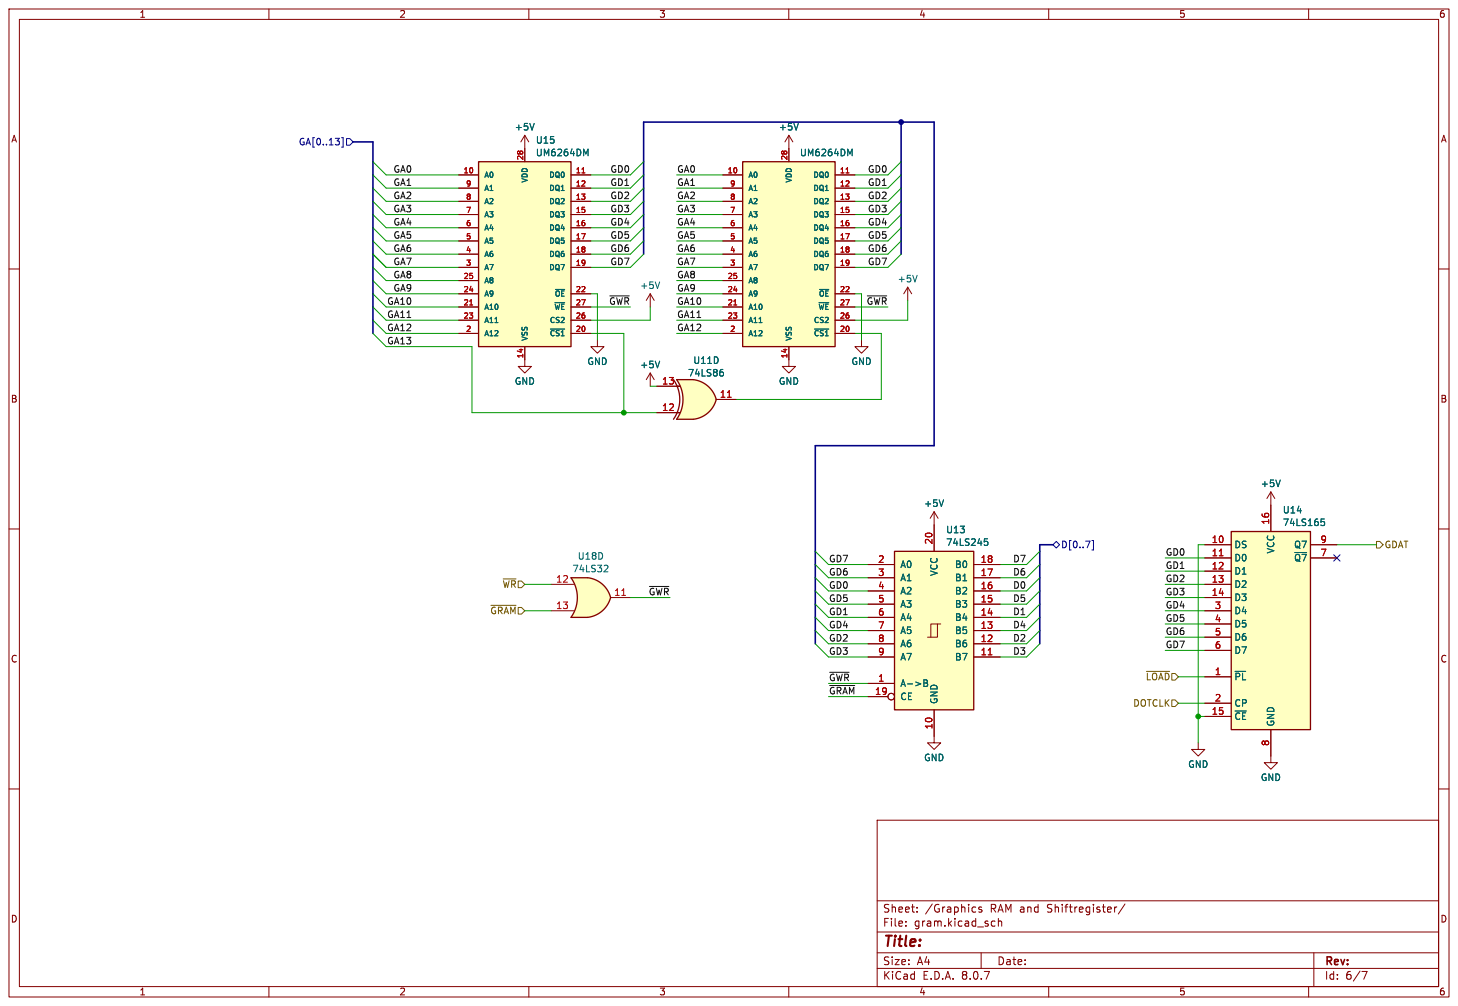
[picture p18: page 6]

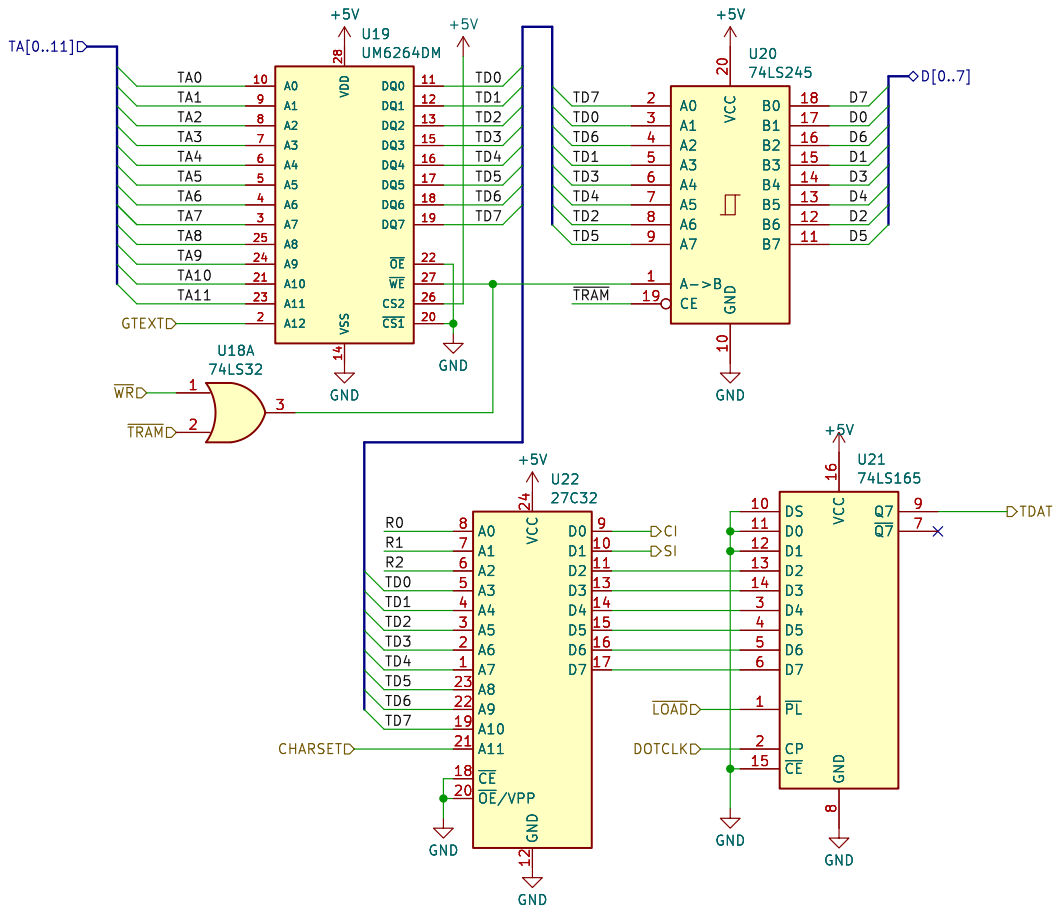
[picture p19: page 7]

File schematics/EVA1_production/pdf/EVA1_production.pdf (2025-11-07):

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

Graphic RAM, MUX and Shiftregister


Id: 2/6 Title: EVA1 (Epson Video Adapter) - Clock Generation


ch: U2 Pin1 to GND! This Latch is useless

Id: 3/6 Title: EVA1 (Epson Video Adapter) - Text RAM


Id: 4/6 Title: EVA1 (Epson Video Adapter) - Graphic RAM



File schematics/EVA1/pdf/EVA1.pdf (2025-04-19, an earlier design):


1 P22/SCLK 10 P23/RX 11 P24/TX 12 P10/TIN2 13 P11/TOUT2 14 P12/TOUT3 15 P13 16 P14 17 P15 18 P16 19 XTAL 2 P17 20 VCC_STBY 21 P47/A15 22 P46/A14 23 P45/A13 24 P44/A12 25 P43/A11 26 P42/A10 27 P41/A9 28 P40/A8 29 EXTAL 3 P37/AD7 30 P36/AD6 31 P35/AD5 32 P34/AD4 33 P33/AD3 34 P32/AD2 35 P31/AD1 36 P30/AD0 37 SC2/R/~{W}38 SC1/AS 39 ~{NMI} 4 E

576kHz 288k When HIGHRES LTDAT is 1.5MHz (E Clock), when Low it is 750kHz.

Why?? Serial Ports Address Decoder and Reset Circuit

R[0..2] Text RAM, MUX and Shiftregister1

1 MA6 10 MA7 11 MA8 12 MA9 13 MA10 14 MA11 15 MA12 16 MA13 17 DE 18 CURSOR 19 ~{RESET} 2 VCC 20 CLK 21 R/~{W} 22 E


Id: 2/6 Title: EVA1 (Epson Video Adapter) - Clock Generation


Id: 3/6 Title: EVA1 (Epson Video Adapter) - Text RAM


Id: 4/6 Title: EVA1 (Epson Video Adapter) - Graphic RAM



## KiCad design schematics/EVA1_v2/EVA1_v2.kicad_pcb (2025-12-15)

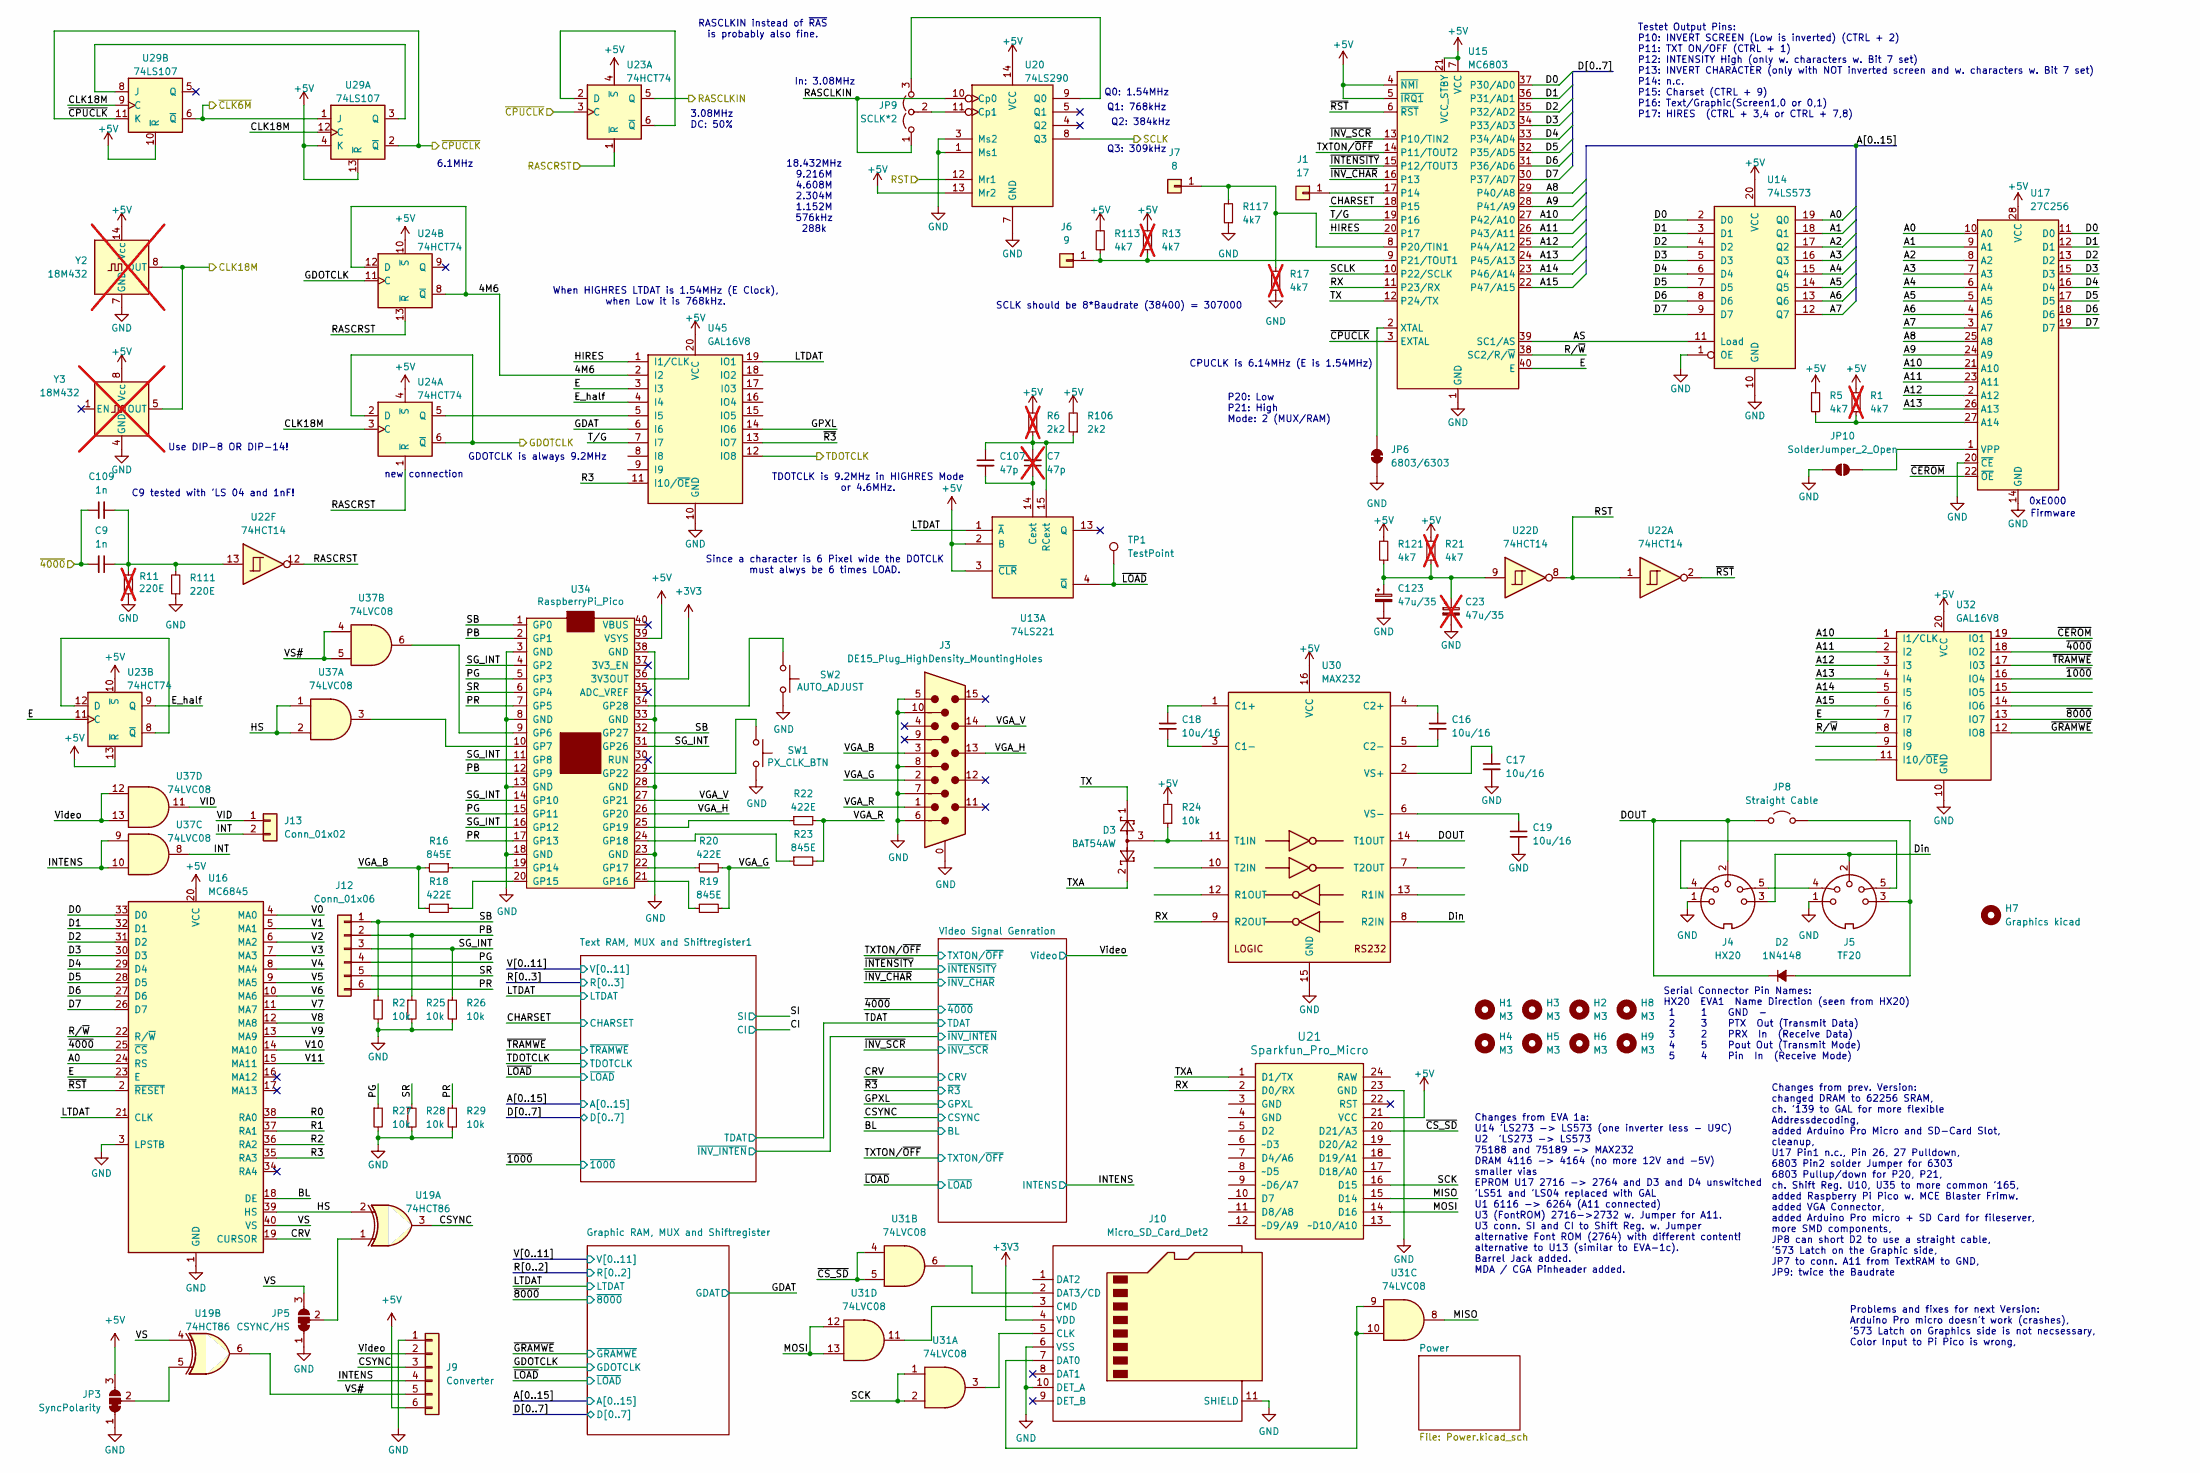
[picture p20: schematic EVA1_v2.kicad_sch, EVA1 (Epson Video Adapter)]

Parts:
C7: 47p; C_Disc_D4.7mm_W2.5mm_P5.00mm; not fitted
C9: 1n; C_Disc_D4.7mm_W2.5mm_P5.00mm
C16, C17, C18, C19: 10u/16; CP_Radial_D6.3mm_P2.50mm
C23: 47u/35; CP_Radial_D5.0mm_P2.50mm; not fitted
C107: 47p; C_1206_3216Metric_Pad1.33x1.80mm_HandSolder
C109: 1n; C_1206_3216Metric_Pad1.33x1.80mm_HandSolder
C123: 47u/35; CP_EIA-7343-31_Kemet-D_Pad2.25x2.55mm_HandSolder
D2: 1N4148; D_A-405_P7.62mm_Horizontal
D3: BAT54AW; SOT-23_Handsoldering
H1, H2, H3, H4, H5, H6, H8, H9: M3; MountingHole_3.2mm_M3
H7: Graphics kicad; KiCad-Logo2_6mm_SilkScreen
J1: 17; PinSocket_1x01_P2.54mm_Vertical
J3: DE15_Plug_HighDensity_MountingHoles; DSUB-15-HD_Female_Horizontal_P2.29x1.90mm_EdgePinOffset3.03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
J4: HX20; DIN-5_Stereo
J5: TF20; DIN-5_Stereo
J6: 9; PinSocket_1x01_P2.54mm_Vertical
J7: 8; PinSocket_1x01_P2.54mm_Vertical
J9: Converter; PinHeader_1x06_P2.54mm_Vertical
J10: Micro_SD_Card_Det2; microSD_HC_Hirose_DM3D-SF
J12: Conn_01x06; PinSocket_1x06_P2.54mm_Vertical
J13: Conn_01x02; PinSocket_1x02_P2.54mm_Vertical
JP3: SyncPolarity; SolderJumper-3_P1.3mm_Bridged12_RoundedPad1.0x1.5mm
JP5: CSYNC/HS; SolderJumper-3_P1.3mm_Bridged12_RoundedPad1.0x1.5mm
JP6: 6803/6303; SolderJumper-2_P1.3mm_Bridged_RoundedPad1.0x1.5mm
JP8: Straight Cable; PinHeader_1x02_P2.54mm_Vertical
JP9: SCLK*2; PinHeader_1x03_P2.54mm_Vertical
JP10: SolderJumper_2_Open; SolderJumper-2_P1.3mm_Open_RoundedPad1.0x1.5mm
R1, R13, R17, R21: 4k7; R_Axial_DIN0411_L9.9mm_D3.6mm_P12.70mm_Horizontal; not fitted
R2, R24, R25, R26, R27, R28, R29: 10k; R_1206_3216Metric_Pad1.30x1.75mm_HandSolder
R5, R113, R117, R121: 4k7; R_1206_3216Metric_Pad1.30x1.75mm_HandSolder
R6: 2k2; R_Axial_DIN0411_L9.9mm_D3.6mm_P12.70mm_Horizontal; not fitted
R11: 220E; R_Axial_DIN0411_L9.9mm_D3.6mm_P12.70mm_Horizontal; not fitted
R16, R19, R23: 845E; R_1206_3216Metric_Pad1.30x1.75mm_HandSolder
R18, R20, R22: 422E; R_1206_3216Metric_Pad1.30x1.75mm_HandSolder
R106: 2k2; R_1206_3216Metric_Pad1.30x1.75mm_HandSolder
R111: 220E; R_1206_3216Metric_Pad1.30x1.75mm_HandSolder
SW1: PX_CLK_BTN; SW_Tactile_SPST_Angled_PTS645Vx83-2LFS
SW2: AUTO_ADJUST; SW_Tactile_SPST_Angled_PTS645Vx83-2LFS
TP1: TestPoint; TestPoint_Loop_D1.80mm_Drill1.0mm_Beaded
U13: 74LS221; DIP-16_W7.62mm
U14: 74LS573; DIP-20_W7.62mm
U15: MC6803; DIP-40_W15.24mm_Socket
U16: MC6845; DIP-40_W15.24mm_Socket
U17: 27C256; DIP-28_W15.24mm
U19: 74HCT86; DIP-14_W7.62mm
U20: 74LS290; DIP-14_W7.62mm
U21: Sparkfun_Pro_Micro
U22: 74HCT14; DIP-14_W7.62mm
U23, U24: 74HCT74; DIP-14_W7.62mm
U29: 74LS107; DIP-14_W7.62mm
U30: MAX232; DIP-16_W7.62mm_Socket
U31, U37: 74LVC08; SOIC-14_3.9x8.7mm_P1.27mm
U32, U45: GAL16V8; DIP-20_W7.62mm
U34: RaspberryPi_Pico; raspberry_pi_pico
Y2: 18M432; Oscillator_DIP-14; not fitted
Y3: 18M432; Oscillator_DIP-8; not fitted

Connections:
+3V3: J10.4 (VDD), U34.36 (3V3OUT); also elsewhere on the board
+5V: J9.6, JP3.3 (B), R1.1, R5.1, R6.2, R13.2, R21.2, R24.2, R106.2, R113.2, R121.2, U13.2 (B), U13.3 (~CLR), U14.20 (VCC), U15.4 (~NMI), U15.5 (~IRQ1), U15.7 (VCC), U15.21 (VCC_STBY), U16.20 (VCC), U17.28 (VCC), U20.13 (Mr2), U20.14 (VCC), U21.21 (VCC), U23.4 (~S), U23.10 (~S), U23.13 (~R), U24.4 (~S), U24.10 (~S), U29.4 (K), U29.10 (~R), U29.13 (~R), U30.16 (VCC), U32.20 (VCC), U34.39 (VSYS), U45.20 (VCC), Y2.14 (Vcc), Y3.8 (Vcc); also elsewhere on the board
/4M6: U24.8 (~Q), U24.12 (D), U45.2 (I2)
/A0: U14.19 (Q0), U16.24 (RS), U17.10 (A0); also elsewhere on the board
/A1: U14.18 (Q1), U17.9 (A1); also elsewhere on the board
/A2: U14.17 (Q2), U17.8 (A2); also elsewhere on the board
/A3: U14.16 (Q3), U17.7 (A3); also elsewhere on the board
/A4: U14.15 (Q4), U17.6 (A4); also elsewhere on the board
/A5: U14.14 (Q5), U17.5 (A5); also elsewhere on the board
/A6: U14.13 (Q6), U17.4 (A6); also elsewhere on the board
/A7: U14.12 (Q7), U17.3 (A7); also elsewhere on the board
/A8: U15.29 (P40/A8), U17.25 (A8); also elsewhere on the board
/A9: U15.28 (P41/A9), U17.24 (A9); also elsewhere on the board
/A10: U15.27 (P42/A10), U17.21 (A10), U32.1 (I1/CLK); also elsewhere on the board
/A11: U15.26 (P43/A11), U17.23 (A11), U32.2 (I2); also elsewhere on the board
/A12: U15.25 (P44/A12), U17.2 (A12), U32.3 (I3); also elsewhere on the board
/A13: U15.24 (P45/A13), U17.26 (A13), U32.4 (I4); also elsewhere on the board
/A14: U15.23 (P46/A14), U32.5 (I5); also elsewhere on the board
/A15: U15.22 (P47/A15), U32.6 (I6)
/AS: U14.11 (Load), U15.39 (SC1/AS)
/BL: U16.18 (DE); also elsewhere on the board
/CHARSET: U15.18 (P15); also elsewhere on the board
/CLK18M: U24.3 (C), U29.9 (C), U29.12 (C), Y2.8 (OUT), Y3.5 (OUT)
/CRV: U16.19 (CURSOR); also elsewhere on the board
/CSYNC: J9.3, U19.3; also elsewhere on the board
/D0: U14.2 (D0), U15.37 (P30/AD0), U16.33 (D0), U17.11 (D0); also elsewhere on the board
/D1: U14.3 (D1), U15.36 (P31/AD1), U16.32 (D1), U17.12 (D1); also elsewhere on the board
/D2: U14.4 (D2), U15.35 (P32/AD2), U16.31 (D2), U17.13 (D2); also elsewhere on the board
/D3: U14.5 (D3), U15.34 (P33/AD3), U16.30 (D3), U17.15 (D3); also elsewhere on the board
/D4: U14.6 (D4), U15.33 (P34/AD4), U16.29 (D4), U17.16 (D4); also elsewhere on the board
/D5: U14.7 (D5), U15.32 (P35/AD5), U16.28 (D5), U17.17 (D5); also elsewhere on the board
/D6: U14.8 (D6), U15.31 (P36/AD6), U16.27 (D6), U17.18 (D6); also elsewhere on the board
/D7: U14.9 (D7), U15.30 (P37/AD7), U16.26 (D7), U17.19 (D7); also elsewhere on the board
/DOUT: D2.1 (K), J4.2, JP8.1 (A), U30.14 (T1OUT)
/Din: J4.3, J5.2, U30.8 (R2IN)
/E: U15.40 (E), U16.23 (E), U23.11 (C), U32.7 (I7), U45.3 (I3)
/E_half: U23.9 (Q), U45.4 (I4)
/GDAT: U45.6 (I6); also elsewhere on the board
/GDOTCLK: U24.2 (D), U24.6 (~Q), U24.11 (C); also elsewhere on the board
/GPXL: U45.14 (IO6); also elsewhere on the board
/HIRES: U15.20 (P17), U45.1 (I1/CLK)
/HS: U16.39 (HS), U19.2, U37.1, U37.2
/INT: J13.2, U37.8
/INTENS: J9.4, U37.9, U37.10; also elsewhere on the board
/LTDAT: U13.1 (~A), U16.21 (CLK), U45.19 (IO1); also elsewhere on the board
/MISO: U21.15 (D14), U31.8
/MOSI: U21.14 (D16), U31.12, U31.13
/PB: J12.2, R25.1, U34.2 (GP1), U34.12 (GP9)
/PG: J12.4, R27.1, U34.5 (GP3), U34.15 (GP11)
/PR: J12.6, R29.1, U34.7 (GP5), U34.17 (GP13)
/R0: U16.38 (RA0); also elsewhere on the board
/R1: U16.37 (RA1); also elsewhere on the board
/R2: U16.36 (RA2); also elsewhere on the board
/R3: U16.35 (RA3), U45.11 (I10/~OE); also elsewhere on the board
/RASCLKIN: JP9.1 (A), U20.10 (Cp0), U23.5 (Q)
/RASCRST: U22.12, U23.1 (~R), U24.1 (~R), U24.13 (~R)
/RST: U20.12 (Mr1), U22.1, U22.8
/RX: U15.11 (P23/RX), U21.2 (D0/RX), U30.9 (R2OUT)
/R/~W: U15.38 (SC2/R/~W), U16.22 (R/~W), U32.8 (I8)
/SB: J12.1, R2.1, U34.1 (GP0), U34.32 (GP27)
/SCK: U21.16 (D15), U31.1, U31.2
/SCLK: U15.10 (P22/SCLK), U20.8 (Q3)
/SG_INT: J12.3, R26.1, U34.4 (GP2), U34.11 (GP8), U34.14 (GP10), U34.16 (GP12), U34.31 (GP26)
/SR: J12.5, R28.1, U34.6 (GP4)
/TDOTCLK: U45.12 (IO8); also elsewhere on the board
/TX: D3.1, U15.12 (P24/TX)
/TXA: D3.2, U21.1 (D1/TX)
/TXTON/~OFF: U15.14 (P11/TOUT2); also elsewhere on the board
/V0: U16.4 (MA0); also elsewhere on the board
/V1: U16.5 (MA1); also elsewhere on the board
/V2: U16.6 (MA2); also elsewhere on the board
/V3: U16.7 (MA3); also elsewhere on the board
/V4: U16.8 (MA4); also elsewhere on the board
/V5: U16.9 (MA5); also elsewhere on the board
/V6: U16.10 (MA6); also elsewhere on the board
/V7: U16.11 (MA7); also elsewhere on the board
/V8: U16.12 (MA8); also elsewhere on the board
/V9: U16.13 (MA9); also elsewhere on the board
/V10: U16.14 (MA10); also elsewhere on the board
/V11: U16.15 (MA11); also elsewhere on the board
/VGA_B: J3.3, R16.2, R18.2
/VGA_G: J3.2, R19.2, R20.2
/VGA_H: J3.13, U34.26 (GP20)
/VGA_R: J3.1, R22.2, R23.2
/VGA_V: J3.14, U34.27 (GP21)
/VID: J13.1, U37.11
/VS: JP5.3 (B), U16.40 (VS), U19.4
/VS#: J9.5, U19.6, U37.4, U37.5
/Video: J9.2, U37.12, U37.13; also elsewhere on the board
/~1000: U32.16 (IO4); also elsewhere on the board
/~4000: C9.2, C109.1, U16.25 (~CS), U32.18 (IO2)
/~8000: U32.13 (IO7); also elsewhere on the board
/~CEROM: U17.22 (~OE), U32.19 (IO1)
/~CLK6M: U29.1 (J), U29.6 (~Q)
/~CPUCLK: U15.3 (EXTAL), U23.3 (C), U29.2 (~Q), U29.11 (K)
/~CS_SD: U21.20 (D21/A3), U31.4, U31.5
/~GRAMWE: U32.12 (IO8); also elsewhere on the board
/~INTENSITY: U15.15 (P12/TOUT3); also elsewhere on the board
/~INV_CHAR: U15.16 (P13); also elsewhere on the board
/~INV_SCR: U15.13 (P10/TIN2); also elsewhere on the board
/~LOAD: TP1.1, U13.4 (~Q); also elsewhere on the board
/~R3: U45.13 (IO7); also elsewhere on the board
/~RST: U15.6 (~RST), U16.2 (~RESET), U22.2
/~TRAMWE: U32.17 (I03); also elsewhere on the board
GND: C17.2, C19.2, C23.2, C123.2, J3.0, J3.5, J3.6, J3.7, J3.8, J3.10, J4.1, J5.1, J9.1, J10.6 (VSS), J10.10 (DET_A), J10.11 (SHIELD), JP3.1 (A), JP5.1 (A), JP6.1 (A), JP10.1 (A), R2.2, R11.1, R17.1, R25.2, R26.2, R27.2, R28.2, R29.2, R111.1, R117.1, SW1.2, SW2.2, U14.1 (OE), U14.10 (GND), U15.1 (GND), U16.1 (GND), U16.3 (LPSTB), U17.14 (GND), U17.20 (~CE), U20.1 (Ms1), U20.3 (Ms2), U20.7 (GND), U21.23 (GND), U30.15 (GND), U32.10 (GND), U34.3 (GND), U34.8 (GND), U34.13 (GND), U34.18 (GND), U34.23 (GND), U34.28 (GND), U34.33 (GND), U34.38 (GND), U45.10 (GND), Y2.7 (GND), Y3.4 (GND); also elsewhere on the board
unnamed: C9.1, C109.2, R11.2, R111.2, U22.13
unnamed: C23.1, C123.1, R21.1, R121.1, U22.9
unnamed: D2.2 (A), J5.3, JP8.2 (B)
unnamed: J1.1, U15.17 (P14)
unnamed: J4.4, J5.5
unnamed: J4.5, J5.4
unnamed: J6.1, R13.1, R113.1, U15.9 (P21/TOUT1)
unnamed: J7.1, R17.2, R117.2, U15.8 (P20/TIN1)
unnamed: J10.5 (CLK), U31.3
unnamed: J10.3 (CMD), U31.11
unnamed: J10.7 (DAT0), U31.9, U31.10
unnamed: J10.2 (DAT3/CD), U31.6
unnamed: JP3.2 (C), U19.5
unnamed: JP5.2 (C), U19.1
unnamed: JP6.2 (B), U15.2 (XTAL)
unnamed: JP9.3 (B), U20.9 (Q0)
unnamed: JP9.2 (C), U20.11 (Cp1)
unnamed: JP10.2 (B), U17.1 (VPP)
unnamed: C7.1, C107.2, U13.14 (Cext)
unnamed: C7.2, C107.1, R6.1, R106.1, U13.15 (RCext)
unnamed: R1.2, R5.2, U17.27 (A14)
unnamed: U23.2 (D), U23.6 (~Q)
unnamed: U23.8 (~Q), U23.12 (D)
unnamed: U24.5 (Q), U45.5 (I5)
unnamed: U29.3 (Q), U29.8 (J)
unnamed: C18.1, U30.1 (C1+)
unnamed: C18.2, U30.3 (C1-)
unnamed: C16.1, U30.4 (C2+)
unnamed: C16.2, U30.5 (C2-)
unnamed: D3.3, R24.1, U30.11 (T1IN)
unnamed: C17.1, U30.2 (VS+)
unnamed: C19.1, U30.6 (VS-)
unnamed: U34.9 (GP6), U37.6
unnamed: U34.10 (GP7), U37.3
unnamed: R16.1, U34.19 (GP14)
unnamed: R18.1, U34.20 (GP15)
unnamed: R19.1, U34.21 (GP16)
unnamed: R20.1, U34.22 (GP17)
unnamed: R23.1, U34.24 (GP18)
unnamed: R22.1, U34.25 (GP19)
unnamed: SW1.1, U34.29 (GP22)
unnamed: SW2.1, U34.34 (GP28)

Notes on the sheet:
P20: Low P21: High Mode: 2 (MUX/RAM)
3.08MHz DC: 50%
TDOTCLK is 9.2MHz in HIGHRES Mode or 4.6MHz.
Testet Output Pins: P10: INVERT SCREEN (Low is inverted) (CTRL + 2) P11: TXT ON/OFF (CTRL + 1) P12: INTENSITY High (only w. characters w. Bit 7 set) P13: INVERT CHARACTER (only with NOT inverted screen and w. characters w. Bit 7 set) P14: n.c. P15: Charset (CTRL + 9) P16: Text/Graphic(Screen1,0 or 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
RASCLKIN instead of ~{RAS} is probably also fine.
Use DIP-8 OR DIP-14!
GDOTCLK is always 9.2MHz
C9 tested with 'LS 04 and 1nF!
Q1: 768kHz
CPUCLK is 6.14MHz (E is 1.54MHz)
Serial Connector Pin Names: HX20 EVA1 Name Direction (seen from HX20) 1 1 GND - 2 3 PTX Out (Transmit Data) 3 2 PRX In (Receive Data) 4 5 Pout Out (Transmit Mode) 5 4 Pin In (Receive Mode)
Q3: 309kHz
Changes from EVA 1a: U14 'LS273 -> LS573 (one inverter less - U9C) U2 'LS273 -> LS573 75188 and 75189 -> MAX232 DRAM 4116 -> 4164 (no more 12V and -5V) smaller vias EPROM U17 2716 -> 2764 and D3 and D4 unswitched 'LS51 and 'LS04 replaced with GAL U1 6116 -> 6264 (A11 connected) U3 (FontROM) 2716->2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
SCLK should be 8*Baudrate (38400) = 307000
When HIGHRES LTDAT is 1.54MHz (E Clock), when Low it is 768kHz.
6.1MHz
Since a character is 6 Pixel wide the DOTCLK must alwys be 6 times LOAD.
Firmware
18.432MHz 9.216M 4.608M 2.304M 1.152M 576kHz 288k
new connection
0xE000
Q0: 1.54MHz
In: 3.08MHz
Q2: 384kHz
Changes from prev. Version: changed DRAM to 62256 SRAM, ch. '139 to GAL for more flexible Addressdecoding, added Arduino Pro Micro and SD-Card Slot, cleanup, U17 Pin1 n.c., Pin 26, 27 Pulldown, 6803 Pin2 solder Jumper for 6303 6803 Pullup/down for P20, P21, ch. Shift Reg. U10, U35 to more common '1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
Problems and fixes for next Version: Arduino Pro micro doesn't work (crashes), '573 Latch on Graphics side is not necsessary, Color Input to Pi Pico is wrong,

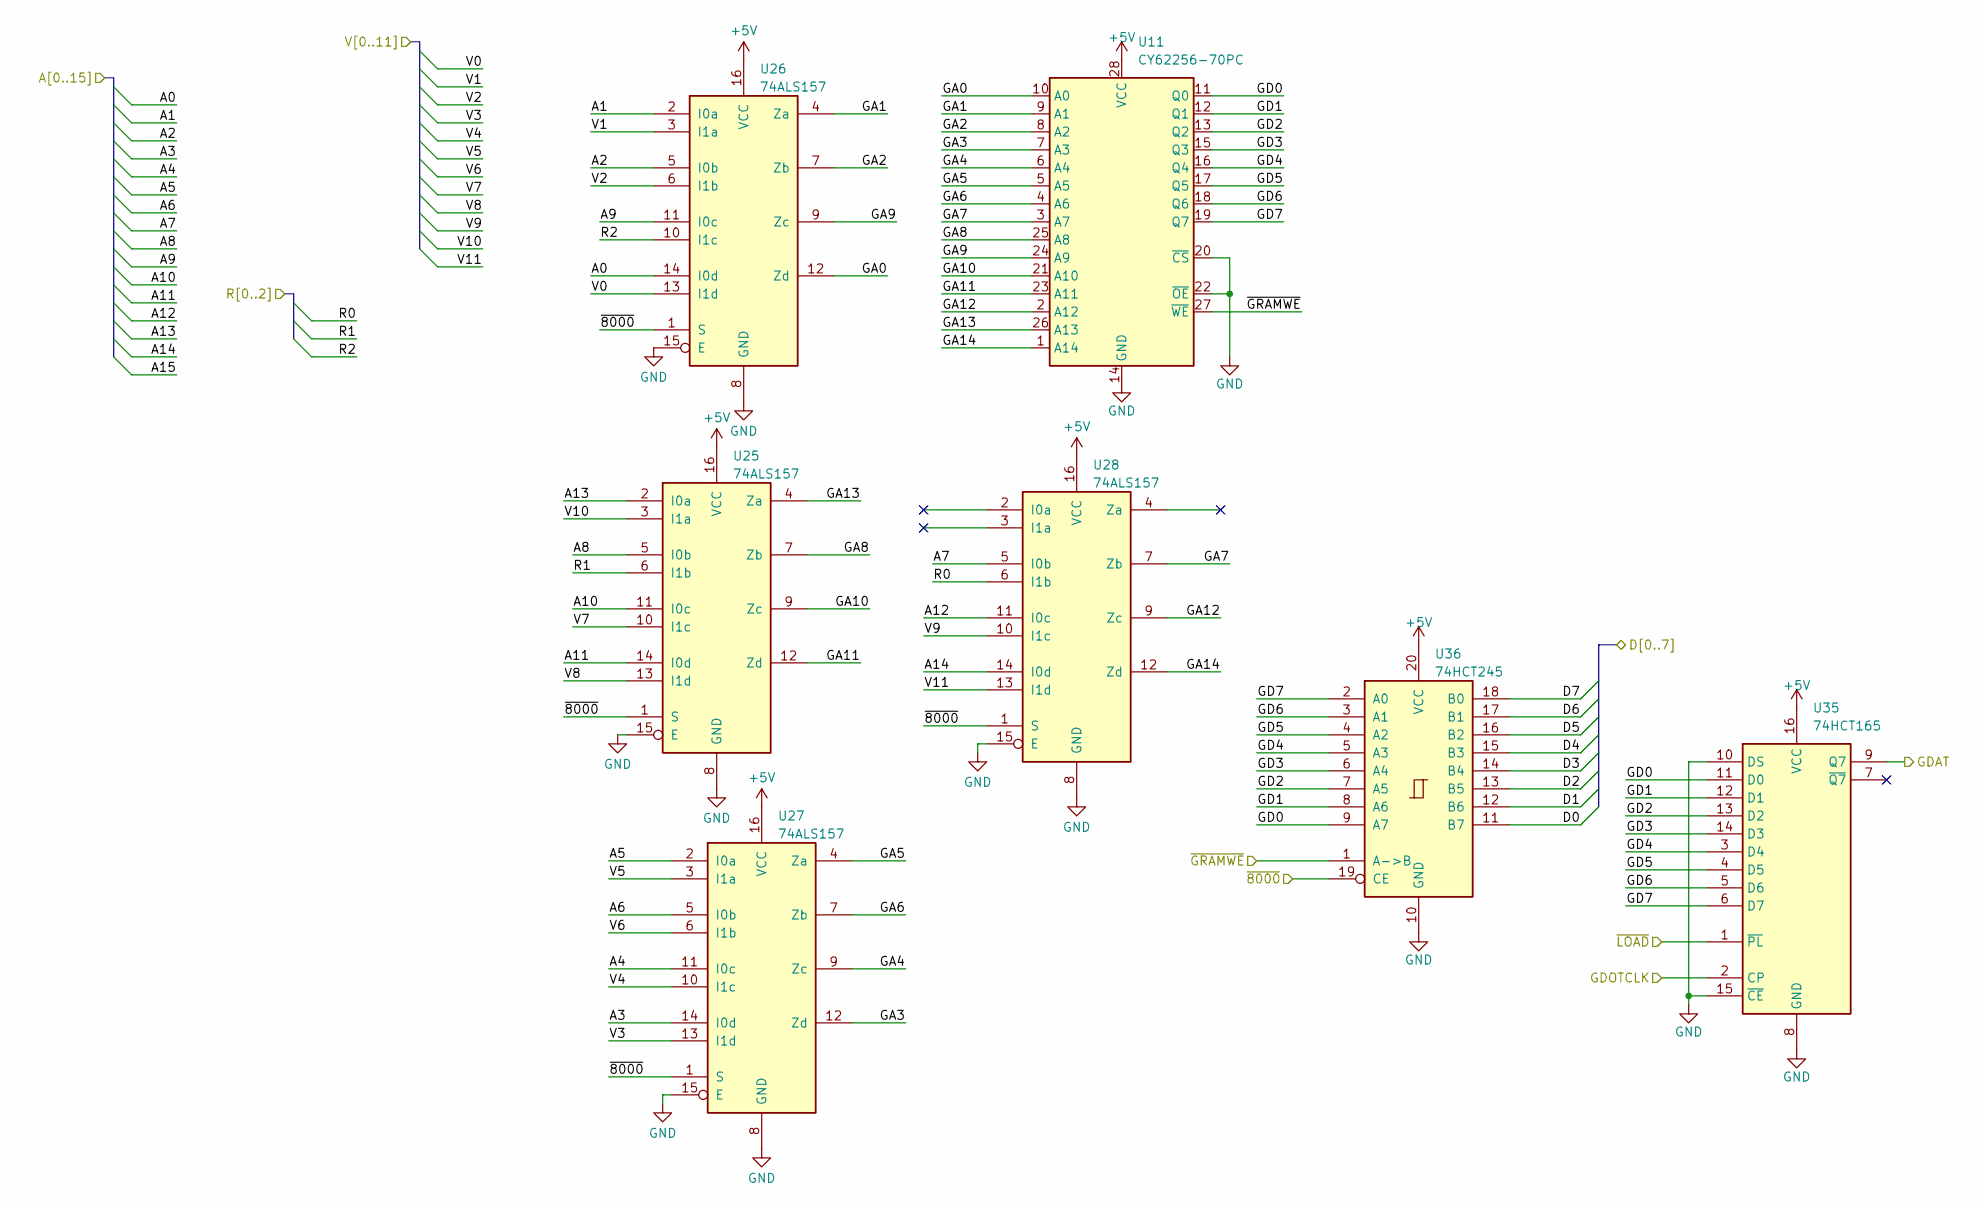
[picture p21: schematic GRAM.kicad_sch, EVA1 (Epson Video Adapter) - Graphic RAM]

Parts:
U11: CY62256-70PC; DIP-28_W15.24mm
U25, U26, U27, U28: 74ALS157; DIP-16_W7.62mm
U35: 74HCT165; DIP-16_W7.62mm_Socket
U36: 74HCT245; DIP-20_W7.62mm

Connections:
+5V: U11.28 (VCC), U25.16 (VCC), U26.16 (VCC), U27.16 (VCC), U28.16 (VCC), U35.16 (VCC), U36.20 (VCC); also elsewhere on the board
/A0: U26.14 (I0d); also elsewhere on the board
/A1: U26.2 (I0a); also elsewhere on the board
/A2: U26.5 (I0b); also elsewhere on the board
/A3: U27.14 (I0d); also elsewhere on the board
/A4: U27.11 (I0c); also elsewhere on the board
/A5: U27.2 (I0a); also elsewhere on the board
/A6: U27.5 (I0b); also elsewhere on the board
/A7: U28.5 (I0b); also elsewhere on the board
/A8: U25.5 (I0b); also elsewhere on the board
/A9: U26.11 (I0c); also elsewhere on the board
/A10: U25.11 (I0c); also elsewhere on the board
/A11: U25.14 (I0d); also elsewhere on the board
/A12: U28.11 (I0c); also elsewhere on the board
/A13: U25.2 (I0a); also elsewhere on the board
/A14: U28.14 (I0d); also elsewhere on the board
/D0: U36.11 (B7); also elsewhere on the board
/D1: U36.12 (B6); also elsewhere on the board
/D2: U36.13 (B5); also elsewhere on the board
/D3: U36.14 (B4); also elsewhere on the board
/D4: U36.15 (B3); also elsewhere on the board
/D5: U36.16 (B2); also elsewhere on the board
/D6: U36.17 (B1); also elsewhere on the board
/D7: U36.18 (B0); also elsewhere on the board
/GDAT: U35.9 (Q7); also elsewhere on the board
/GDOTCLK: U35.2 (CP); also elsewhere on the board
/Graphic RAM, MUX and Shiftregister/GA0: U11.10 (A0), U26.12 (Zd)
/Graphic RAM, MUX and Shiftregister/GA1: U11.9 (A1), U26.4 (Za)
/Graphic RAM, MUX and Shiftregister/GA2: U11.8 (A2), U26.7 (Zb)
/Graphic RAM, MUX and Shiftregister/GA3: U11.7 (A3), U27.12 (Zd)
/Graphic RAM, MUX and Shiftregister/GA4: U11.6 (A4), U27.9 (Zc)
/Graphic RAM, MUX and Shiftregister/GA5: U11.5 (A5), U27.4 (Za)
/Graphic RAM, MUX and Shiftregister/GA6: U11.4 (A6), U27.7 (Zb)
/Graphic RAM, MUX and Shiftregister/GA7: U11.3 (A7), U28.7 (Zb)
/Graphic RAM, MUX and Shiftregister/GA8: U11.25 (A8), U25.7 (Zb)
/Graphic RAM, MUX and Shiftregister/GA9: U11.24 (A9), U26.9 (Zc)
/Graphic RAM, MUX and Shiftregister/GA10: U11.21 (A10), U25.9 (Zc)
/Graphic RAM, MUX and Shiftregister/GA11: U11.23 (A11), U25.12 (Zd)
/Graphic RAM, MUX and Shiftregister/GA12: U11.2 (A12), U28.9 (Zc)
/Graphic RAM, MUX and Shiftregister/GA13: U11.26 (A13), U25.4 (Za)
/Graphic RAM, MUX and Shiftregister/GA14: U11.1 (A14), U28.12 (Zd)
/Graphic RAM, MUX and Shiftregister/GD0: U11.11 (Q0), U35.11 (D0), U36.9 (A7)
/Graphic RAM, MUX and Shiftregister/GD1: U11.12 (Q1), U35.12 (D1), U36.8 (A6)
/Graphic RAM, MUX and Shiftregister/GD2: U11.13 (Q2), U35.13 (D2), U36.7 (A5)
/Graphic RAM, MUX and Shiftregister/GD3: U11.15 (Q3), U35.14 (D3), U36.6 (A4)
/Graphic RAM, MUX and Shiftregister/GD4: U11.16 (Q4), U35.3 (D4), U36.5 (A3)
/Graphic RAM, MUX and Shiftregister/GD5: U11.17 (Q5), U35.4 (D5), U36.4 (A2)
/Graphic RAM, MUX and Shiftregister/GD6: U11.18 (Q6), U35.5 (D6), U36.3 (A1)
/Graphic RAM, MUX and Shiftregister/GD7: U11.19 (Q7), U35.6 (D7), U36.2 (A0)
/R0: U28.6 (I1b); also elsewhere on the board
/R1: U25.6 (I1b); also elsewhere on the board
/R2: U26.10 (I1c); also elsewhere on the board
/V0: U26.13 (I1d); also elsewhere on the board
/V1: U26.3 (I1a); also elsewhere on the board
/V2: U26.6 (I1b); also elsewhere on the board
/V3: U27.13 (I1d); also elsewhere on the board
/V4: U27.10 (I1c); also elsewhere on the board
/V5: U27.3 (I1a); also elsewhere on the board
/V6: U27.6 (I1b); also elsewhere on the board
/V7: U25.10 (I1c); also elsewhere on the board
/V8: U25.13 (I1d); also elsewhere on the board
/V9: U28.10 (I1c); also elsewhere on the board
/V10: U25.3 (I1a); also elsewhere on the board
/V11: U28.13 (I1d); also elsewhere on the board
/~8000: U25.1 (S), U26.1 (S), U27.1 (S), U28.1 (S), U36.19 (CE); also elsewhere on the board
/~GRAMWE: U11.27 (~WE), U36.1 (A->B); also elsewhere on the board
/~LOAD: U35.1 (~PL); also elsewhere on the board
GND: U11.14 (GND), U11.20 (~CS), U11.22 (~OE), U25.8 (GND), U25.15 (E), U26.8 (GND), U26.15 (E), U27.8 (GND), U27.15 (E), U28.8 (GND), U28.15 (E), U35.8 (GND), U35.10 (DS), U35.15 (~CE), U36.10 (GND); also elsewhere on the board

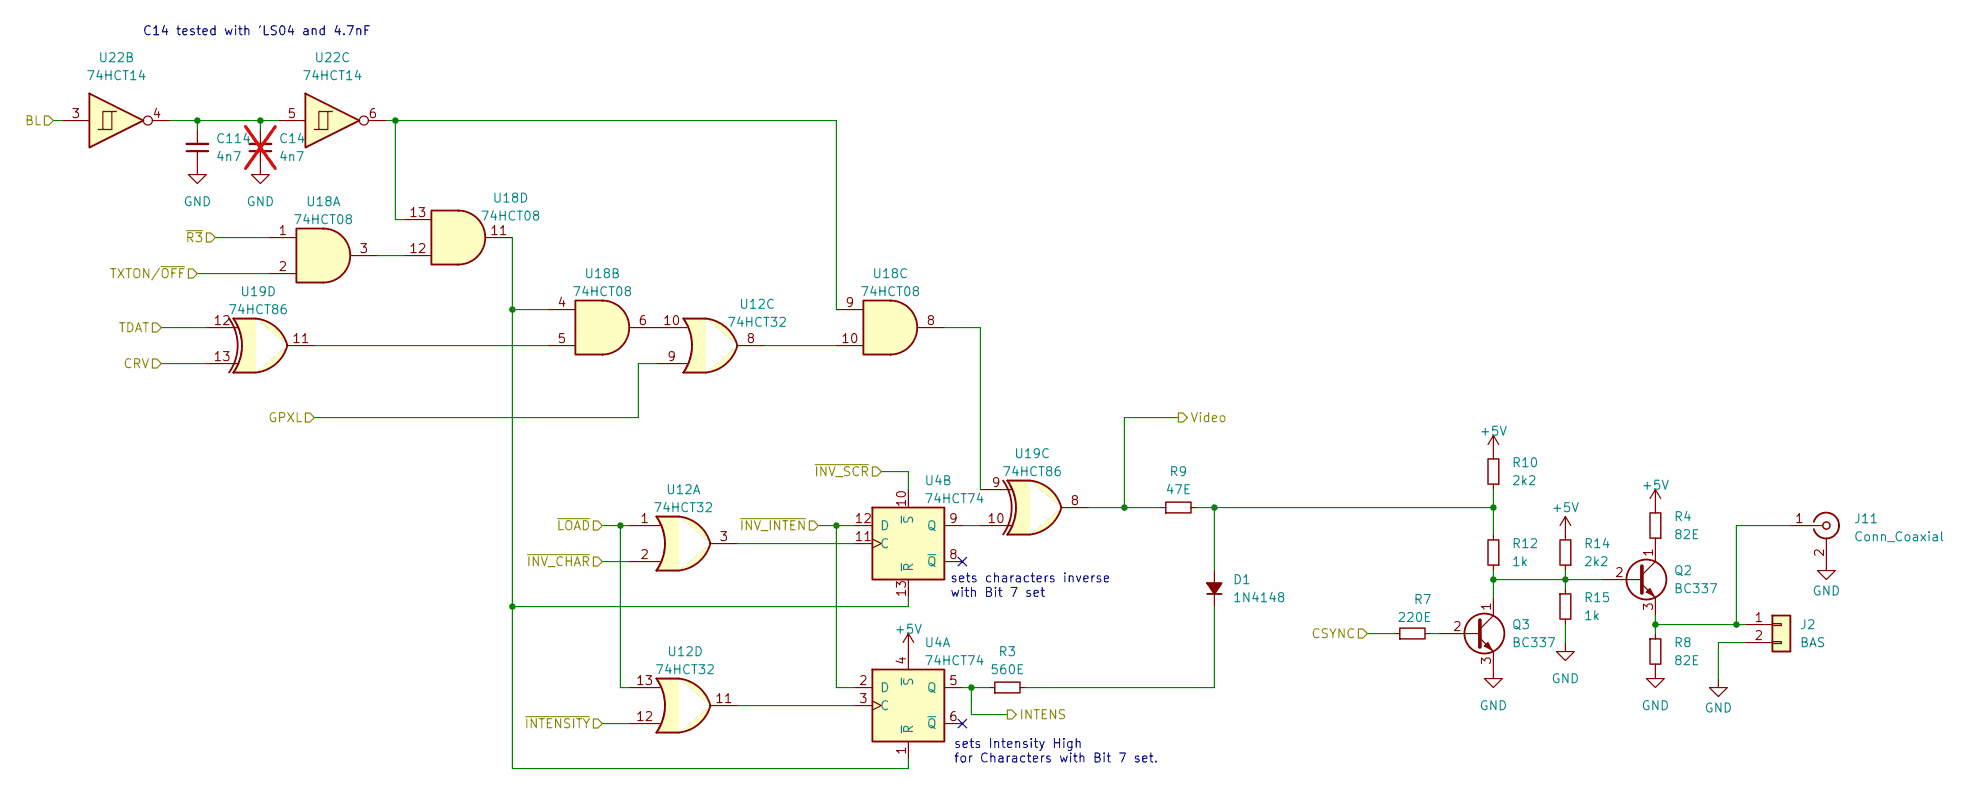
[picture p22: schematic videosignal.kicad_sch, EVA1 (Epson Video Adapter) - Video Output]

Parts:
C14: 4n7; C_Disc_D4.7mm_W2.5mm_P5.00mm; not fitted
C114: 4n7; C_1206_3216Metric_Pad1.33x1.80mm_HandSolder
D1: 1N4148; D_A-405_P7.62mm_Horizontal
J2: BAS; PinHeader_1x02_P2.54mm_Vertical
J11: Conn_Coaxial; Keystone_RCA-Jack
Q2, Q3: BC337; TO-92_Wide
R3: 560E; R_Axial_DIN0411_L9.9mm_D3.6mm_P12.70mm_Horizontal
R4, R8: 82E; R_Axial_DIN0411_L9.9mm_D3.6mm_P12.70mm_Horizontal
R7: 220E; R_Axial_DIN0411_L9.9mm_D3.6mm_P12.70mm_Horizontal
R9: 47E; R_Axial_DIN0411_L9.9mm_D3.6mm_P12.70mm_Horizontal
R10, R14: 2k2; R_Axial_DIN0411_L9.9mm_D3.6mm_P12.70mm_Horizontal
R12, R15: 1k; R_Axial_DIN0411_L9.9mm_D3.6mm_P12.70mm_Horizontal
U4: 74HCT74; DIP-14_W7.62mm
U12: 74HCT32; DIP-14_W7.62mm
U18: 74HCT08; DIP-14_W7.62mm
U19: 74HCT86; DIP-14_W7.62mm
U22: 74HCT14; DIP-14_W7.62mm

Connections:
+5V: R4.2, R10.2, R14.2, U4.4 (~S); also elsewhere on the board
/BL: U22.3; also elsewhere on the board
/CRV: U19.13; also elsewhere on the board
/CSYNC: R7.1; also elsewhere on the board
/GPXL: U12.9; also elsewhere on the board
/INTENS: R3.1, U4.5 (Q); also elsewhere on the board
/TDAT: U19.12; also elsewhere on the board
/TXTON/~OFF: U18.2; also elsewhere on the board
/Text RAM, MUX and Shiftregister1/~INV_INTEN: U4.2 (D), U4.12 (D); also elsewhere on the board
/Video: R9.1, U19.8; also elsewhere on the board
/~INTENSITY: U12.12; also elsewhere on the board
/~INV_CHAR: U12.2; also elsewhere on the board
/~INV_SCR: U4.10 (~S); also elsewhere on the board
/~LOAD: U12.1, U12.13; also elsewhere on the board
/~R3: U18.1; also elsewhere on the board
GND: C14.1, C114.1, J2.2, J11.2 (Ext), Q3.3 (E), R8.2, R15.2; also elsewhere on the board
unnamed: C14.2, C114.2, U22.4, U22.5
unnamed: D1.2 (A), R9.2, R10.1, R12.2
unnamed: D1.1 (K), R3.2
unnamed: J2.1, J11.1 (In), Q2.3 (E), R8.1
unnamed: Q2.2 (B), Q3.1 (C), R12.1, R14.1, R15.1
unnamed: Q2.1 (C), R4.1
unnamed: Q3.2 (B), R7.2
unnamed: U4.3 (C), U12.11
unnamed: U4.1 (~R), U4.13 (~R), U18.4, U18.11
unnamed: U4.11 (C), U12.3
unnamed: U4.9 (Q), U19.10
unnamed: U12.8, U18.10
unnamed: U12.10, U18.6
unnamed: U18.5, U19.11
unnamed: U18.8, U19.9
unnamed: U18.3, U18.12
unnamed: U18.9, U18.13, U22.6

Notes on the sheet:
C14 tested with 'LS04 and 4.7nF
sets Intensity High for Characters with Bit 7 set.
sets characters inverse with Bit 7 set

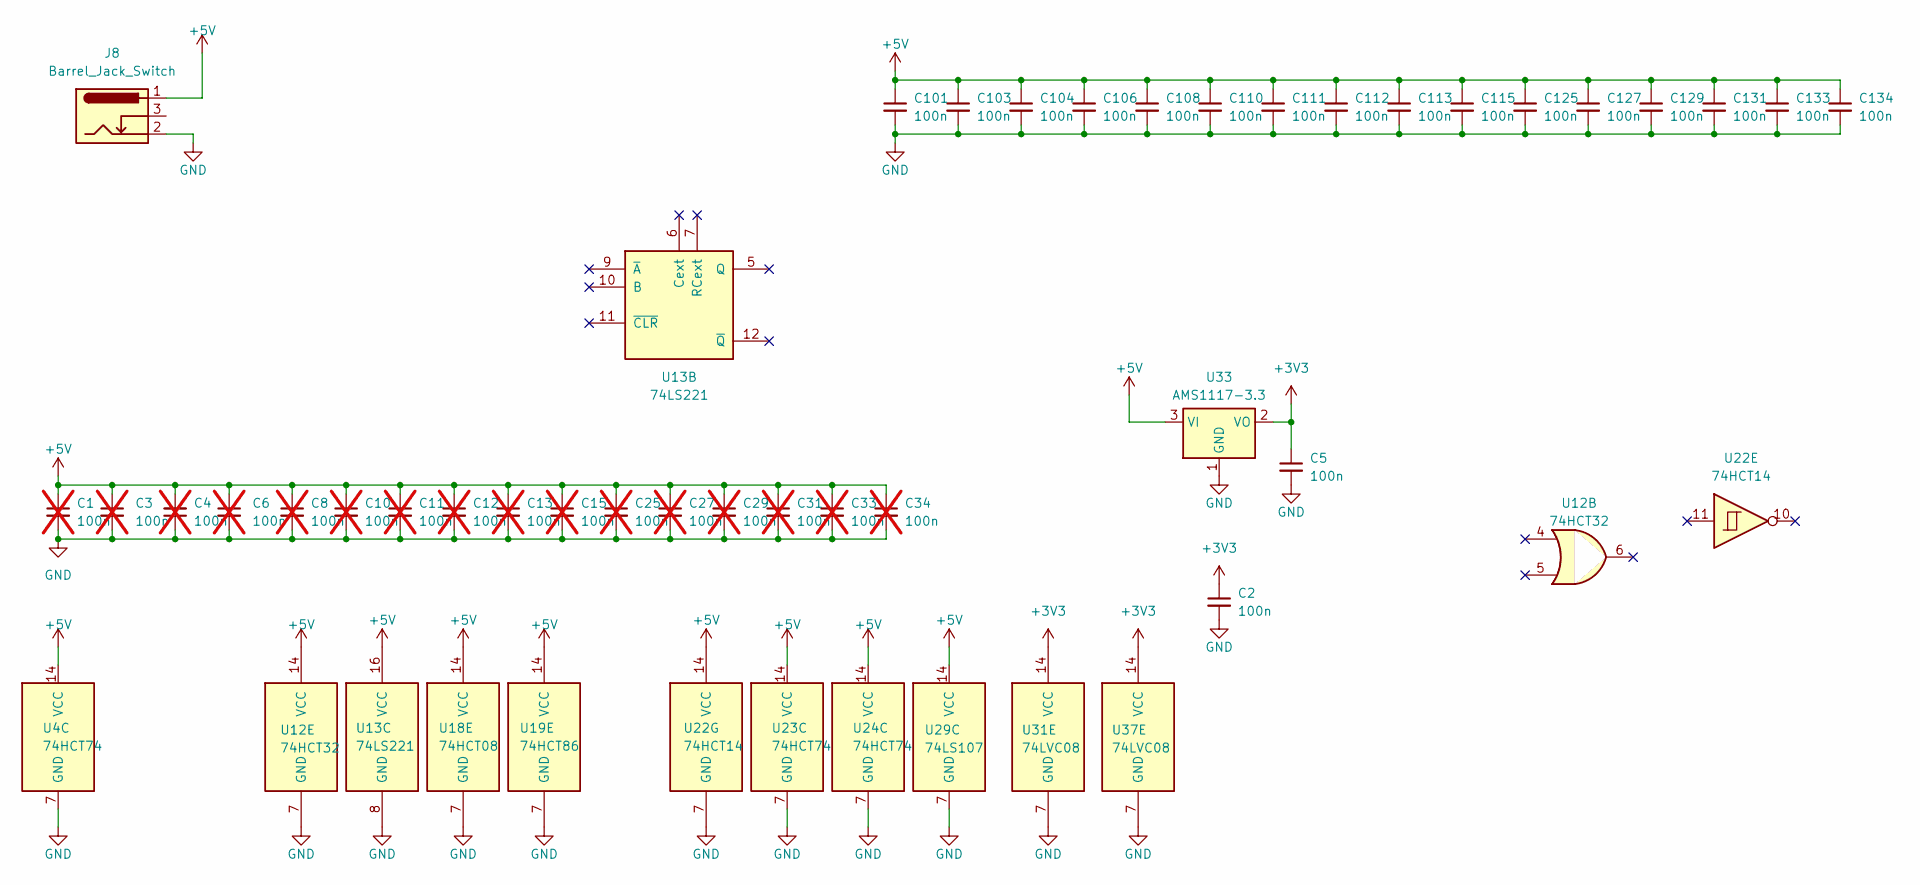
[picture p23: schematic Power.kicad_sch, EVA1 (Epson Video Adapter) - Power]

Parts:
C1, C3, C4, C6, C8, C10, C11, C12, C13, C15, C25, C27, C29, C31, C33, C34: 100n; C_Disc_D4.7mm_W2.5mm_P5.00mm; not fitted
C2, C5, C101, C103, C104, C106, C108, C110, C111, C112, C113, C115, C125, C127, C129, C131, C133, C134: 100n; C_1206_3216Metric_Pad1.33x1.80mm_HandSolder
J8: Barrel_Jack_Switch; BarrelJack_Wuerth_6941xx301002
U4, U23, U24: 74HCT74; DIP-14_W7.62mm
U12: 74HCT32; DIP-14_W7.62mm
U13: 74LS221; DIP-16_W7.62mm
U18: 74HCT08; DIP-14_W7.62mm
U19: 74HCT86; DIP-14_W7.62mm
U22: 74HCT14; DIP-14_W7.62mm
U29: 74LS107; DIP-14_W7.62mm
U31, U37: 74LVC08; SOIC-14_3.9x8.7mm_P1.27mm
U33: AMS1117-3.3; SOT-223-3_TabPin2

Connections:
+3V3: C2.1, C5.1, U31.14 (VCC), U33.2 (VO), U37.14 (VCC); also elsewhere on the board
+5V: C1.1, C3.1, C4.2, C6.1, C8.1, C10.1, C11.1, C12.1, C13.1, C15.1, C25.1, C27.1, C29.1, C31.1, C33.1, C34.1, C101.1, C103.1, C104.1, C106.1, C108.1, C110.1, C111.1, C112.1, C113.1, C115.1, C125.1, C127.1, C129.1, C131.1, C133.1, C134.1, J8.1, U4.14 (VCC), U12.14 (VCC), U13.16 (VCC), U18.14 (VCC), U19.14 (VCC), U22.14 (VCC), U23.14 (VCC), U24.14 (VCC), U29.14 (VCC), U33.3 (VI); also elsewhere on the board
GND: C1.2, C2.2, C3.2, C4.1, C5.2, C6.2, C8.2, C10.2, C11.2, C12.2, C13.2, C15.2, C25.2, C27.2, C29.2, C31.2, C33.2, C34.2, C101.2, C103.2, C104.2, C106.2, C108.2, C110.2, C111.2, C112.2, C113.2, C115.2, C125.2, C127.2, C129.2, C131.2, C133.2, C134.2, J8.2, U4.7 (GND), U12.7 (GND), U13.8 (GND), U18.7 (GND), U19.7 (GND), U22.7 (GND), U23.7 (GND), U24.7 (GND), U29.7 (GND), U31.7 (GND), U33.1 (GND), U37.7 (GND); also elsewhere on the board

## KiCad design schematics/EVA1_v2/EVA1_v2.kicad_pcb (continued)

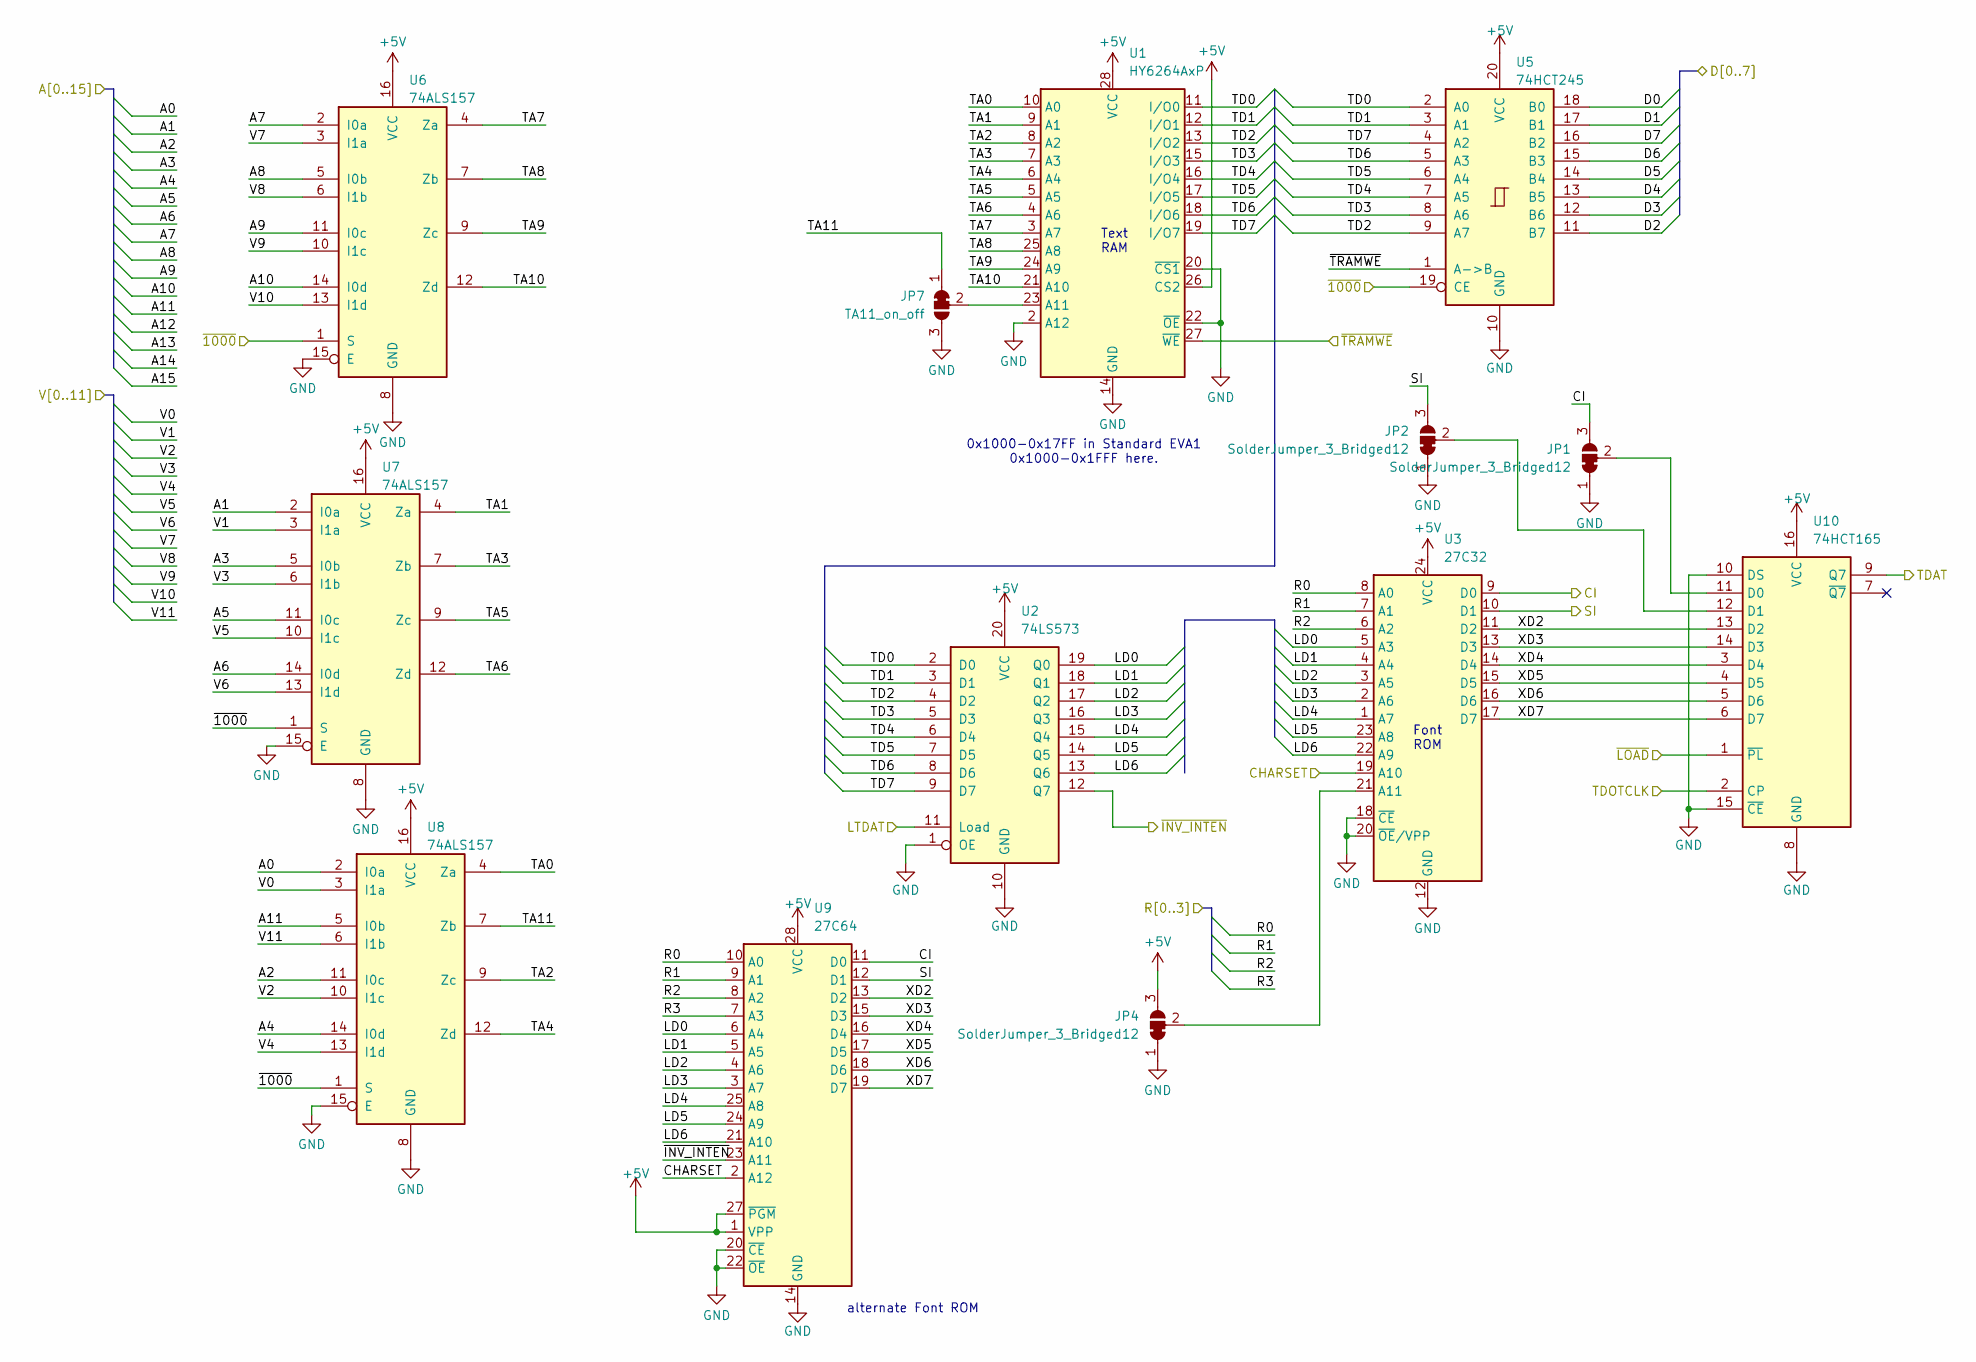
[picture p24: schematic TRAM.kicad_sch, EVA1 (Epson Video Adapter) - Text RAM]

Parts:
JP1, JP2, JP4: SolderJumper_3_Bridged12; SolderJumper-3_P1.3mm_Bridged12_RoundedPad1.0x1.5mm
JP7: TA11_on_off; SolderJumper-3_P1.3mm_Bridged12_RoundedPad1.0x1.5mm
U1: HY6264AxP; DIP-28_W15.24mm
U2: 74LS573; DIP-20_W7.62mm
U3: 27C32; DIP-24_W15.24mm
U5: 74HCT245; DIP-20_W7.62mm
U6, U7, U8: 74ALS157; DIP-16_W7.62mm
U9: 27C64; DIP-28_W15.24mm
U10: 74HCT165; DIP-16_W7.62mm_Socket

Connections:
+5V: JP4.3 (B), U1.26 (CS2), U1.28 (VCC), U2.20 (VCC), U3.24 (VCC), U5.20 (VCC), U6.16 (VCC), U7.16 (VCC), U8.16 (VCC), U9.1 (VPP), U9.27 (~PGM), U9.28 (VCC), U10.16 (VCC); also elsewhere on the board
/A0: U8.2 (I0a); also elsewhere on the board
/A1: U7.2 (I0a); also elsewhere on the board
/A2: U8.11 (I0c); also elsewhere on the board
/A3: U7.5 (I0b); also elsewhere on the board
/A4: U8.14 (I0d); also elsewhere on the board
/A5: U7.11 (I0c); also elsewhere on the board
/A6: U7.14 (I0d); also elsewhere on the board
/A7: U6.2 (I0a); also elsewhere on the board
/A8: U6.5 (I0b); also elsewhere on the board
/A9: U6.11 (I0c); also elsewhere on the board
/A10: U6.14 (I0d); also elsewhere on the board
/A11: U8.5 (I0b); also elsewhere on the board
/CHARSET: U3.19 (A10), U9.2 (A12); also elsewhere on the board
/CI: JP1.3 (B), U3.9 (D0), U9.11 (D0)
/D0: U5.18 (B0); also elsewhere on the board
/D1: U5.17 (B1); also elsewhere on the board
/D2: U5.11 (B7); also elsewhere on the board
/D3: U5.12 (B6); also elsewhere on the board
/D4: U5.13 (B5); also elsewhere on the board
/D5: U5.14 (B4); also elsewhere on the board
/D6: U5.15 (B3); also elsewhere on the board
/D7: U5.16 (B2); also elsewhere on the board
/LTDAT: U2.11 (Load); also elsewhere on the board
/R0: U3.8 (A0), U9.10 (A0); also elsewhere on the board
/R1: U3.7 (A1), U9.9 (A1); also elsewhere on the board
/R2: U3.6 (A2), U9.8 (A2); also elsewhere on the board
/R3: U9.7 (A3); also elsewhere on the board
/SI: JP2.3 (B), U3.10 (D1), U9.12 (D1)
/TDAT: U10.9 (Q7); also elsewhere on the board
/TDOTCLK: U10.2 (CP); also elsewhere on the board
/Text RAM, MUX and Shiftregister1/LD0: U2.19 (Q0), U3.5 (A3), U9.6 (A4)
/Text RAM, MUX and Shiftregister1/LD1: U2.18 (Q1), U3.4 (A4), U9.5 (A5)
/Text RAM, MUX and Shiftregister1/LD2: U2.17 (Q2), U3.3 (A5), U9.4 (A6)
/Text RAM, MUX and Shiftregister1/LD3: U2.16 (Q3), U3.2 (A6), U9.3 (A7)
/Text RAM, MUX and Shiftregister1/LD4: U2.15 (Q4), U3.1 (A7), U9.25 (A8)
/Text RAM, MUX and Shiftregister1/LD5: U2.14 (Q5), U3.23 (A8), U9.24 (A9)
/Text RAM, MUX and Shiftregister1/LD6: U2.13 (Q6), U3.22 (A9), U9.21 (A10)
/Text RAM, MUX and Shiftregister1/TA0: U1.10 (A0), U8.4 (Za)
/Text RAM, MUX and Shiftregister1/TA1: U1.9 (A1), U7.4 (Za)
/Text RAM, MUX and Shiftregister1/TA2: U1.8 (A2), U8.9 (Zc)
/Text RAM, MUX and Shiftregister1/TA3: U1.7 (A3), U7.7 (Zb)
/Text RAM, MUX and Shiftregister1/TA4: U1.6 (A4), U8.12 (Zd)
/Text RAM, MUX and Shiftregister1/TA5: U1.5 (A5), U7.9 (Zc)
/Text RAM, MUX and Shiftregister1/TA6: U1.4 (A6), U7.12 (Zd)
/Text RAM, MUX and Shiftregister1/TA7: U1.3 (A7), U6.4 (Za)
/Text RAM, MUX and Shiftregister1/TA8: U1.25 (A8), U6.7 (Zb)
/Text RAM, MUX and Shiftregister1/TA9: U1.24 (A9), U6.9 (Zc)
/Text RAM, MUX and Shiftregister1/TA10: U1.21 (A10), U6.12 (Zd)
/Text RAM, MUX and Shiftregister1/TA11: JP7.1 (A), U8.7 (Zb)
/Text RAM, MUX and Shiftregister1/TD0: U1.11 (I/O0), U2.2 (D0), U5.2 (A0)
/Text RAM, MUX and Shiftregister1/TD1: U1.12 (I/O1), U2.3 (D1), U5.3 (A1)
/Text RAM, MUX and Shiftregister1/TD2: U1.13 (I/O2), U2.4 (D2), U5.9 (A7)
/Text RAM, MUX and Shiftregister1/TD3: U1.15 (I/O3), U2.5 (D3), U5.8 (A6)
/Text RAM, MUX and Shiftregister1/TD4: U1.16 (I/O4), U2.6 (D4), U5.7 (A5)
/Text RAM, MUX and Shiftregister1/TD5: U1.17 (I/O5), U2.7 (D5), U5.6 (A4)
/Text RAM, MUX and Shiftregister1/TD6: U1.18 (I/O6), U2.8 (D6), U5.5 (A3)
/Text RAM, MUX and Shiftregister1/TD7: U1.19 (I/O7), U2.9 (D7), U5.4 (A2)
/Text RAM, MUX and Shiftregister1/XD2: U3.11 (D2), U9.13 (D2), U10.13 (D2)
/Text RAM, MUX and Shiftregister1/XD3: U3.13 (D3), U9.15 (D3), U10.14 (D3)
/Text RAM, MUX and Shiftregister1/XD4: U3.14 (D4), U9.16 (D4), U10.3 (D4)
/Text RAM, MUX and Shiftregister1/XD5: U3.15 (D5), U9.17 (D5), U10.4 (D5)
/Text RAM, MUX and Shiftregister1/XD6: U3.16 (D6), U9.18 (D6), U10.5 (D6)
/Text RAM, MUX and Shiftregister1/XD7: U3.17 (D7), U9.19 (D7), U10.6 (D7)
/Text RAM, MUX and Shiftregister1/~INV_INTEN: U2.12 (Q7), U9.23 (A11); also elsewhere on the board
/V0: U8.3 (I1a); also elsewhere on the board
/V1: U7.3 (I1a); also elsewhere on the board
/V2: U8.10 (I1c); also elsewhere on the board
/V3: U7.6 (I1b); also elsewhere on the board
/V4: U8.13 (I1d); also elsewhere on the board
/V5: U7.10 (I1c); also elsewhere on the board
/V6: U7.13 (I1d); also elsewhere on the board
/V7: U6.3 (I1a); also elsewhere on the board
/V8: U6.6 (I1b); also elsewhere on the board
/V9: U6.10 (I1c); also elsewhere on the board
/V10: U6.13 (I1d); also elsewhere on the board
/V11: U8.6 (I1b); also elsewhere on the board
/~1000: U5.19 (CE), U6.1 (S), U7.1 (S), U8.1 (S); also elsewhere on the board
/~LOAD: U10.1 (~PL); also elsewhere on the board
/~TRAMWE: U1.27 (~WE), U5.1 (A->B); also elsewhere on the board
GND: JP1.1 (A), JP2.1 (A), JP4.1 (A), JP7.3 (B), U1.2 (A12), U1.14 (GND), U1.20 (~CS1), U1.22 (~OE), U2.1 (OE), U2.10 (GND), U3.12 (GND), U3.18 (~CE), U3.20 (~OE/VPP), U5.10 (GND), U6.8 (GND), U6.15 (E), U7.8 (GND), U7.15 (E), U8.8 (GND), U8.15 (E), U9.14 (GND), U9.20 (~CE), U9.22 (~OE), U10.8 (GND), U10.10 (DS), U10.15 (~CE); also elsewhere on the board
unnamed: JP1.2 (C), U10.11 (D0)
unnamed: JP2.2 (C), U10.12 (D1)
unnamed: JP4.2 (C), U3.21 (A11)
unnamed: JP7.2 (C), U1.23 (A11)

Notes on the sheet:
0x1000-0x17FF in Standard EVA1 0x1000-0x1FFF here.
Font ROM
Text RAM
alternate Font ROM

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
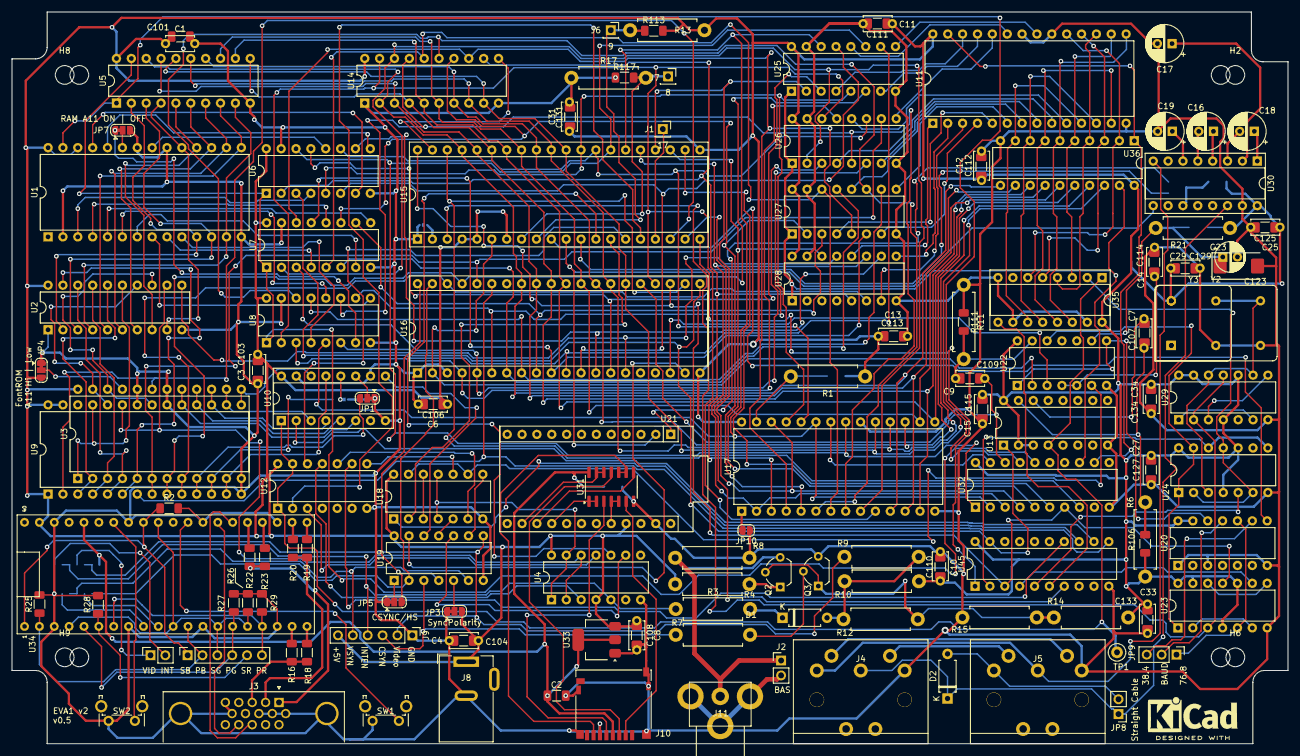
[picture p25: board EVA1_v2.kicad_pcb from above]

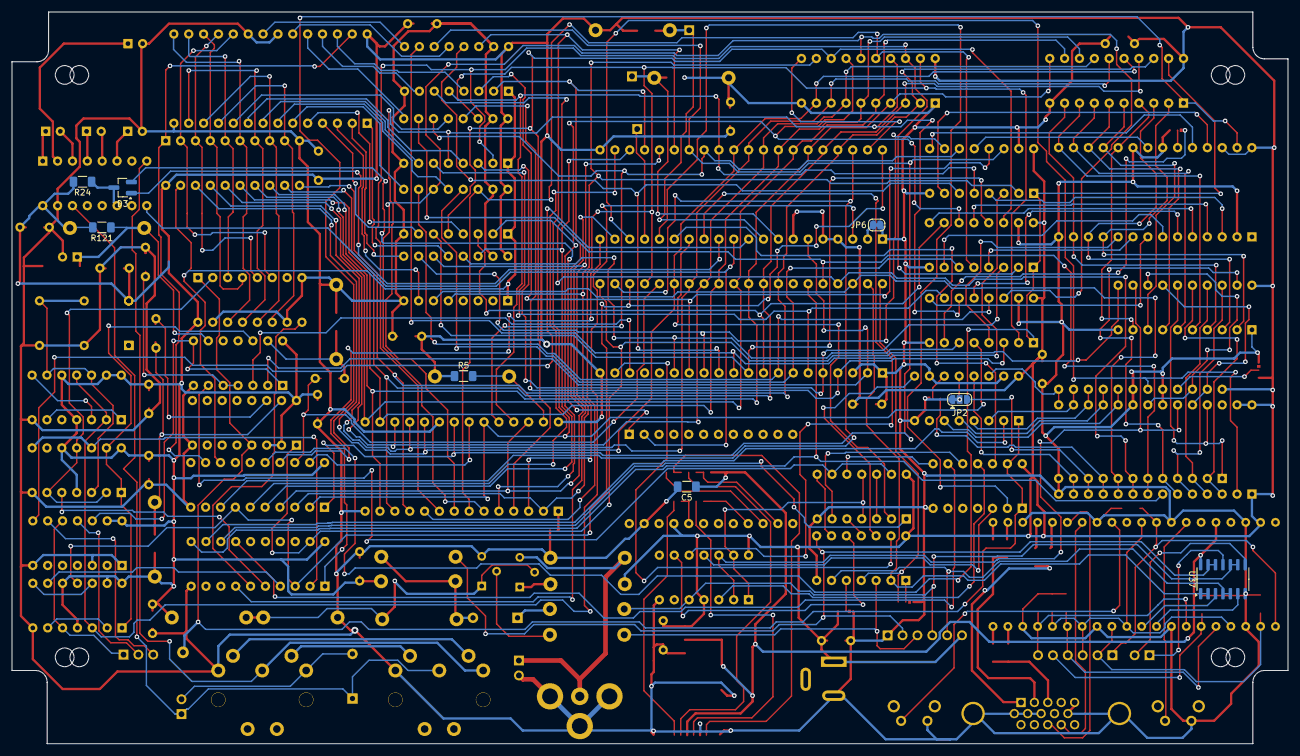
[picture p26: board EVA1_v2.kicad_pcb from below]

Board: 2 copper layers, 218.0 x 125.0 mm, 160 parts (8 on the bottom side), 229 nets.

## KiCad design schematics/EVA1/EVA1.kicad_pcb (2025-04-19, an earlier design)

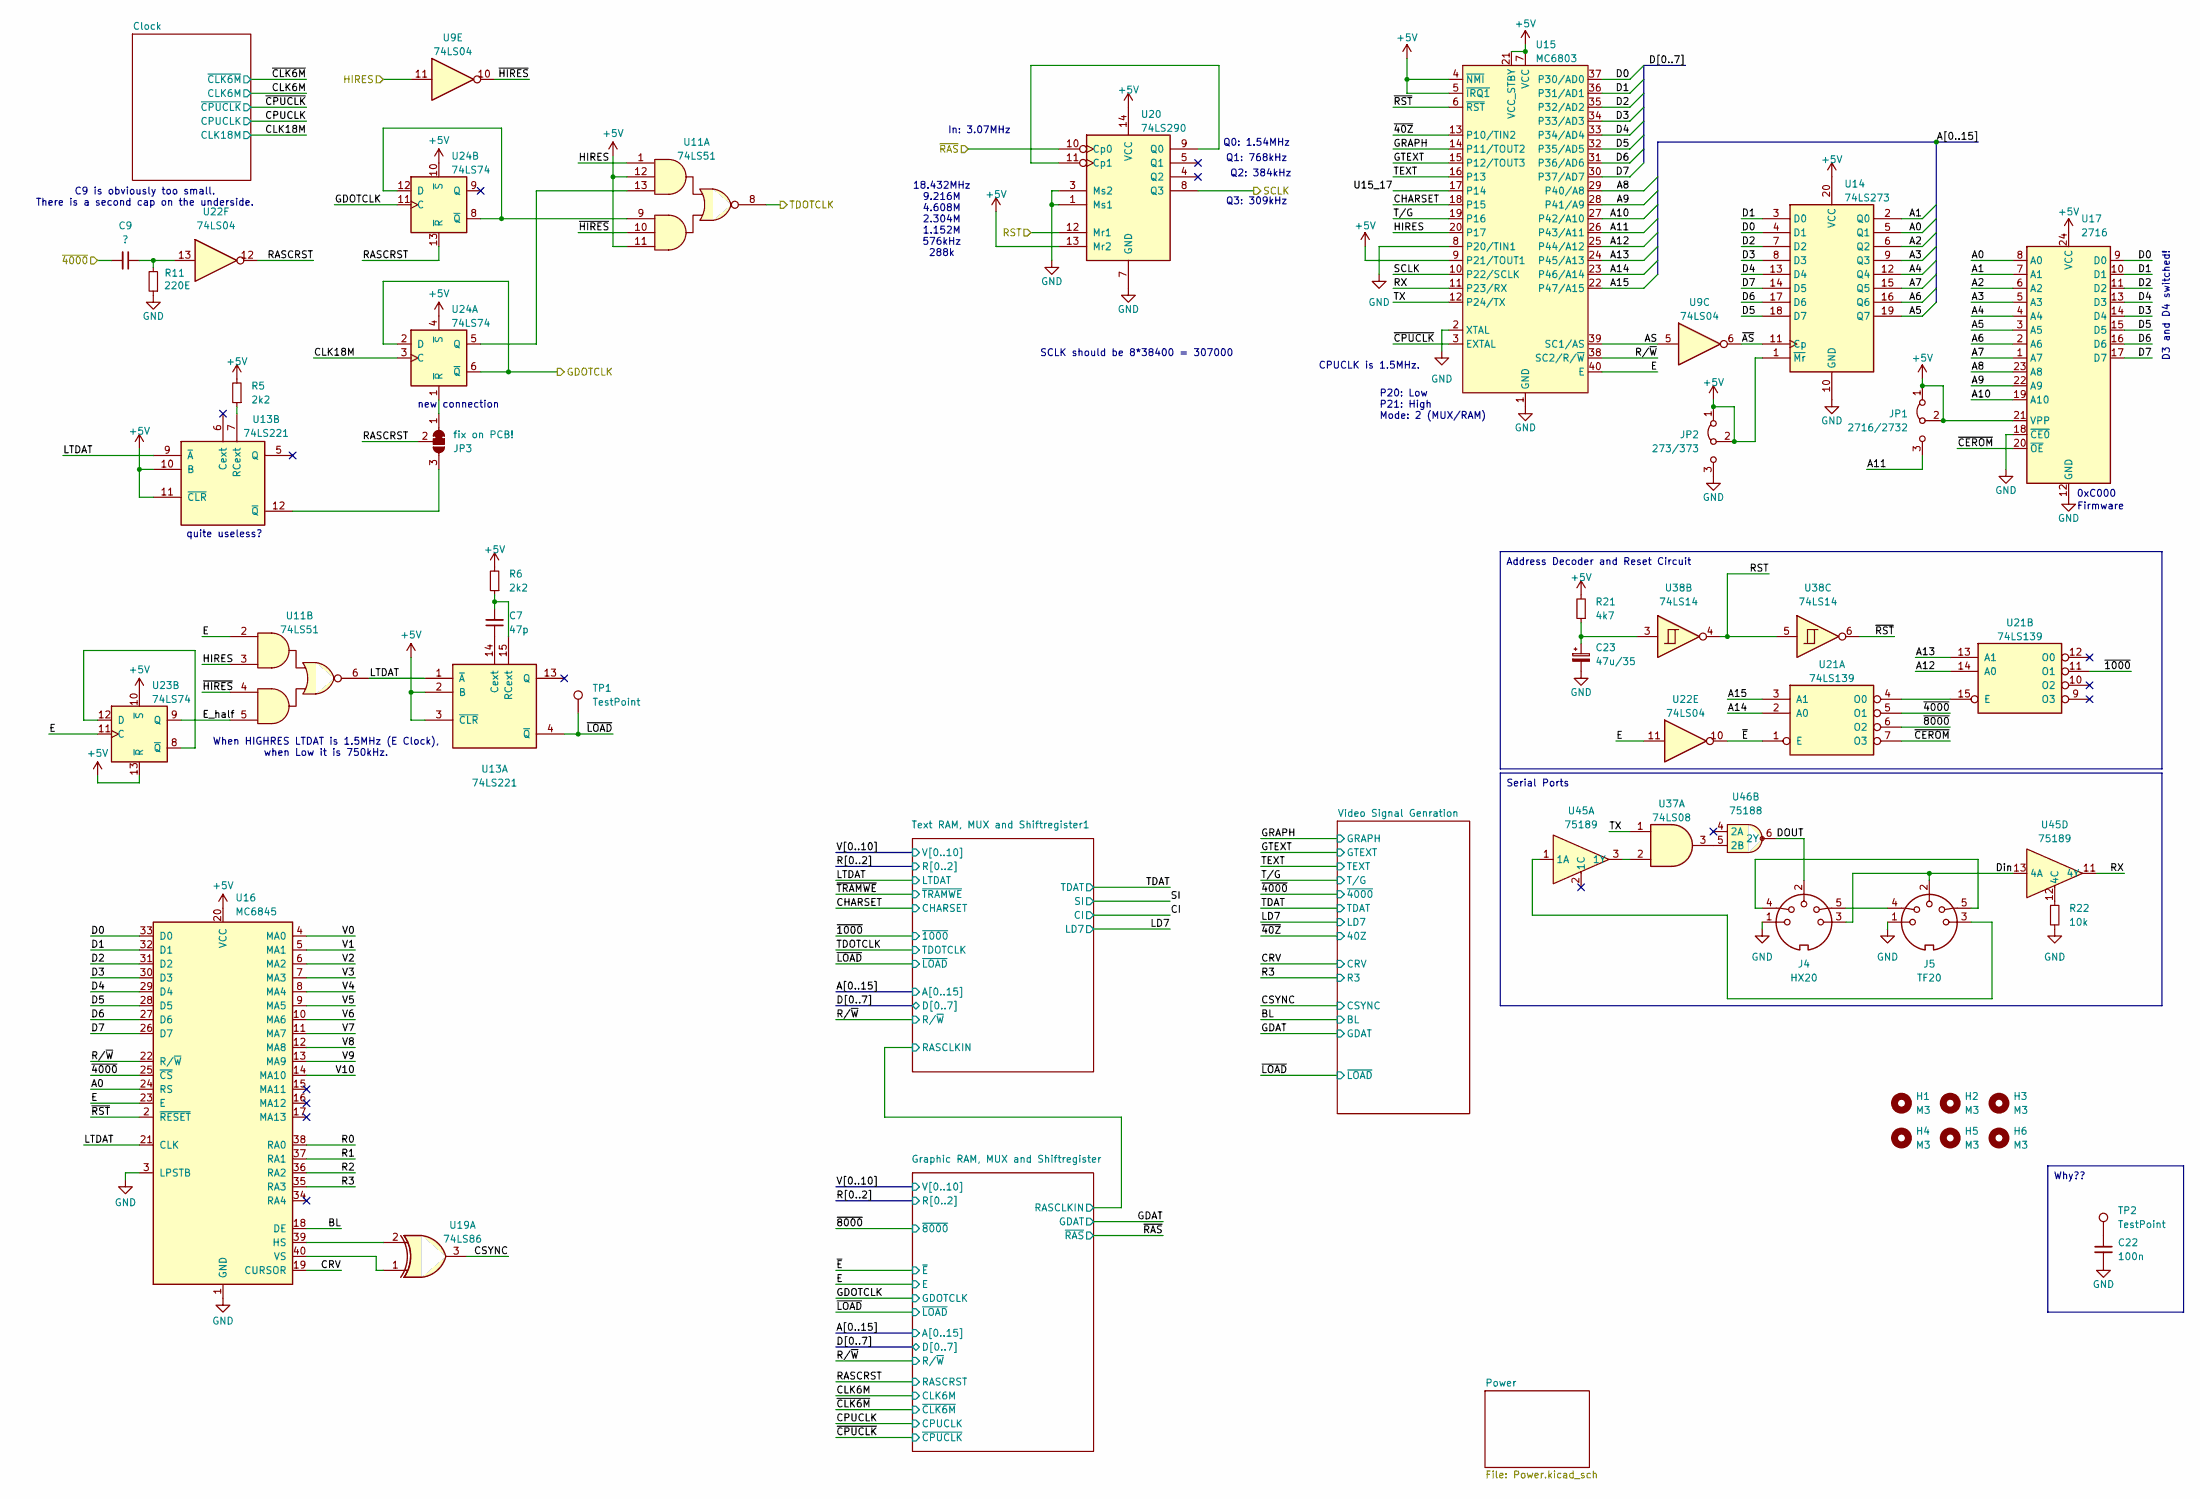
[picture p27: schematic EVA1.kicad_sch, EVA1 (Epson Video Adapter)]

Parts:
C7: 47p; C_Disc_D4.7mm_W2.5mm_P5.00mm
C9: ?; C_Disc_D4.7mm_W2.5mm_P5.00mm
C22: 100n; C_Disc_D4.7mm_W2.5mm_P5.00mm
C23: 47u/35; CP_Radial_D5.0mm_P2.50mm
H1, H2, H3, H4, H5, H6: M3; MountingHole_3.2mm_M3
J4: HX20; DIN-5_Stereo
J5: TF20; DIN-5_Stereo
JP1: 2716/2732; PinHeader_1x03_P2.54mm_Vertical
JP2: 273/373; PinHeader_1x03_P2.54mm_Vertical
JP3: fix on PCB!; SolderJumper-3_P1.3mm_Bridged12_RoundedPad1.0x1.5mm
R5, R6: 2k2; R_Axial_DIN0411_L9.9mm_D3.6mm_P12.70mm_Horizontal
R11: 220E; R_Axial_DIN0411_L9.9mm_D3.6mm_P12.70mm_Horizontal
R21: 4k7; R_Axial_DIN0411_L9.9mm_D3.6mm_P12.70mm_Horizontal
R22: 10k; R_Axial_DIN0411_L9.9mm_D3.6mm_P12.70mm_Horizontal
TP1, TP2: TestPoint; TestPoint_Loop_D1.80mm_Drill1.0mm_Beaded
U9, U22: 74LS04; DIP-14_W7.62mm
U11: 74LS51; DIP-14_W7.62mm
U13: 74LS221; DIP-16_W7.62mm
U14: 74LS273; DIP-20_W7.62mm
U15: MC6803; DIP-40_W15.24mm_Socket
U16: MC6845; DIP-40_W15.24mm_Socket
U17: 2716; DIP-24_W15.24mm
U19: 74LS86; DIP-14_W7.62mm
U20: 74LS290; DIP-14_W7.62mm
U21: 74LS139; DIP-16_W7.62mm
U23, U24: 74LS74; DIP-14_W7.62mm
U37: 74LS08; DIP-14_W7.62mm
U38: 74LS14; DIP-14_W7.62mm
U45: 75189; DIP-14_W7.62mm
U46: 75188; DIP-14_W7.62mm

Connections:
+5V: JP1.1 (A), JP1.2 (C), JP2.1 (A), JP2.2 (C), R5.2, R6.2, R21.2, U11.11, U11.12, U13.2 (B), U13.3 (~CLR), U13.10 (B), U13.11 (~CLR), U14.1 (~Mr), U14.20 (VCC), U15.4 (~NMI), U15.5 (~IRQ1), U15.7 (VCC), U15.9 (P21/TOUT1), U15.21 (VCC_STBY), U16.20 (VCC), U17.21 (VPP), U17.24 (VCC), U20.13 (Mr2), U20.14 (VCC), U23.10 (~S), U23.13 (~R), U24.4 (~S), U24.10 (~S); also elsewhere on the board
/A0: U14.5 (Q1), U16.24 (RS), U17.8 (A0); also elsewhere on the board
/A1: U14.2 (Q0), U17.7 (A1); also elsewhere on the board
/A2: U14.6 (Q2), U17.6 (A2); also elsewhere on the board
/A3: U14.9 (Q3), U17.5 (A3); also elsewhere on the board
/A4: U14.12 (Q4), U17.4 (A4); also elsewhere on the board
/A5: U14.19 (Q7), U17.3 (A5); also elsewhere on the board
/A6: U14.16 (Q6), U17.2 (A6); also elsewhere on the board
/A7: U14.15 (Q5), U17.1 (A7); also elsewhere on the board
/A8: U15.29 (P40/A8), U17.23 (A8); also elsewhere on the board
/A9: U15.28 (P41/A9), U17.22 (A9); also elsewhere on the board
/A10: U15.27 (P42/A10), U17.19 (A10); also elsewhere on the board
/A11: JP1.3 (B), U15.26 (P43/A11); also elsewhere on the board
/A12: U15.25 (P44/A12), U21.14 (A0); also elsewhere on the board
/A13: U15.24 (P45/A13), U21.13 (A1); also elsewhere on the board
/A14: U15.23 (P46/A14), U21.2 (A0)
/A15: U15.22 (P47/A15), U21.3 (A1)
/AS: U9.5, U15.39 (SC1/AS)
/BL: U16.18 (DE); also elsewhere on the board
/CHARSET: U15.18 (P15); also elsewhere on the board
/CLK18M: U24.3 (C); also elsewhere on the board
/CRV: U16.19 (CURSOR); also elsewhere on the board
/D0: U14.4 (D1), U15.37 (P30/AD0), U16.33 (D0), U17.9 (D0); also elsewhere on the board
/D1: U14.3 (D0), U15.36 (P31/AD1), U16.32 (D1), U17.10 (D1); also elsewhere on the board
/D2: U14.7 (D2), U15.35 (P32/AD2), U16.31 (D2), U17.11 (D2); also elsewhere on the board
/D3: U14.8 (D3), U15.34 (P33/AD3), U16.30 (D3), U17.14 (D4); also elsewhere on the board
/D4: U14.13 (D4), U15.33 (P34/AD4), U16.29 (D4), U17.13 (D3); also elsewhere on the board
/D5: U14.18 (D7), U15.32 (P35/AD5), U16.28 (D5), U17.15 (D5); also elsewhere on the board
/D6: U14.17 (D6), U15.31 (P36/AD6), U16.27 (D6), U17.16 (D6); also elsewhere on the board
/D7: U14.14 (D5), U15.30 (P37/AD7), U16.26 (D7), U17.17 (D7); also elsewhere on the board
/DOUT: J4.2, U46.6 (2Y)
/Din: J4.3, J5.2, U45.13 (4A)
/E: U11.2, U15.40 (E), U16.23 (E), U22.11, U23.11 (C); also elsewhere on the board
/E_half: U11.5, U23.9 (Q)
/GDOTCLK: U24.2 (D), U24.6 (~Q), U24.11 (C); also elsewhere on the board
/GRAPH: U15.14 (P11/TOUT2); also elsewhere on the board
/GTEXT: U15.15 (P12/TOUT3); also elsewhere on the board
/HIRES: U9.11, U11.1, U11.3, U15.20 (P17)
/HS: U16.39 (HS), U19.2
/LTDAT: U11.6, U13.1 (~A), U13.9 (~A), U16.21 (CLK); also elsewhere on the board
/R0: U16.38 (RA0); also elsewhere on the board
/R1: U16.37 (RA1); also elsewhere on the board
/R2: U16.36 (RA2); also elsewhere on the board
/R3: U16.35 (RA3); also elsewhere on the board
/RASCRST: JP3.2 (C), U22.12, U24.13 (~R); also elsewhere on the board
/RST: U20.12 (Mr1), U38.4, U38.5
/RX: U15.11 (P23/RX), U45.11 (4Y)
/R/~W: U15.38 (SC2/R/~W), U16.22 (R/~W); also elsewhere on the board
/SCLK: U15.10 (P22/SCLK), U20.8 (Q3)
/TDOTCLK: U11.8; also elsewhere on the board
/TEXT: U15.16 (P13); also elsewhere on the board
/TX: U15.12 (P24/TX), U37.1
/T/G: U15.19 (P16); also elsewhere on the board
/U15_17: U15.17 (P14)
/V0: U16.4 (MA0); also elsewhere on the board
/V1: U16.5 (MA1); also elsewhere on the board
/V2: U16.6 (MA2); also elsewhere on the board
/V3: U16.7 (MA3); also elsewhere on the board
/V4: U16.8 (MA4); also elsewhere on the board
/V5: U16.9 (MA5); also elsewhere on the board
/V6: U16.10 (MA6); also elsewhere on the board
/V7: U16.11 (MA7); also elsewhere on the board
/V8: U16.12 (MA8); also elsewhere on the board
/V9: U16.13 (MA9); also elsewhere on the board
/V10: U16.14 (MA10); also elsewhere on the board
/VS: U16.40 (VS), U19.1
/~40Z: U15.13 (P10/TIN2); also elsewhere on the board
/~1000: U21.11 (O1); also elsewhere on the board
/~4000: C9.2, U16.25 (~CS), U21.5 (O1)
/~8000: U21.6 (O2); also elsewhere on the board
/~AS: U9.6, U14.11 (Cp)
/~CEROM: U17.20 (~OE), U21.7 (O3)
/~CPUCLK: U15.3 (EXTAL); also elsewhere on the board
/~E: U21.1 (E), U22.10; also elsewhere on the board
/~HIRES: U9.10, U11.4, U11.10
/~LOAD: TP1.1, U13.4 (~Q); also elsewhere on the board
/~RAS: U20.10 (Cp0); also elsewhere on the board
/~RST: U15.6 (~RST), U16.2 (~RESET), U38.6
GND: C22.2, C23.2, J4.1, J5.1, JP2.3 (B), R11.1, R22.2, U14.10 (GND), U15.1 (GND), U15.2 (XTAL), U15.8 (P20/TIN1), U16.1 (GND), U16.3 (LPSTB), U17.12 (GND), U17.18 (~CE0), U20.1 (Ms1), U20.3 (Ms2), U20.7 (GND); also elsewhere on the board
unnamed: C9.1, R11.2, U22.13
unnamed: C22.1, TP2.1
unnamed: C23.1, R21.1, U38.3
unnamed: J4.4, J5.5
unnamed: J4.5, J5.4
unnamed: JP3.1 (A), U24.1 (~R)
unnamed: JP3.3 (B), U13.12 (~Q)
unnamed 172: U19.3; also elsewhere on the board
unnamed: C7.1, U13.14 (Cext)
unnamed: C7.2, R6.1, U13.15 (RCext)
unnamed: R5.1, U13.7 (RCext)
unnamed: U20.9 (Q0), U20.11 (Cp1)
unnamed: U21.4 (O0), U21.15 (E)
unnamed: U23.8 (~Q), U23.12 (D)
unnamed: U11.13, U24.5 (Q)
unnamed: U11.9, U24.8 (~Q), U24.12 (D)
unnamed: J5.3, U45.1 (1A)
unnamed: U37.2, U45.3 (1Y)
unnamed: R22.1, U45.12 (4C)
unnamed: U37.3, U46.5 (2B)

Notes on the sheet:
Address Decoder and Reset Circuit
Serial Ports
Why??
quite useless?
P20: Low P21: High Mode: 2 (MUX/RAM)
C9 is obviously too small. There is a second cap on the underside.
Q1: 768kHz
CPUCLK is 1.5MHz.
D3 and D4 switched!
Q3: 309kHz
SCLK should be 8*38400 = 307000
When HIGHRES LTDAT is 1.5MHz (E Clock), when Low it is 750kHz.
Firmware
18.432MHz 9.216M 4.608M 2.304M 1.152M 576kHz 288k
new connection
0xC000
Q0: 1.54MHz
In: 3.07MHz
Q2: 384kHz

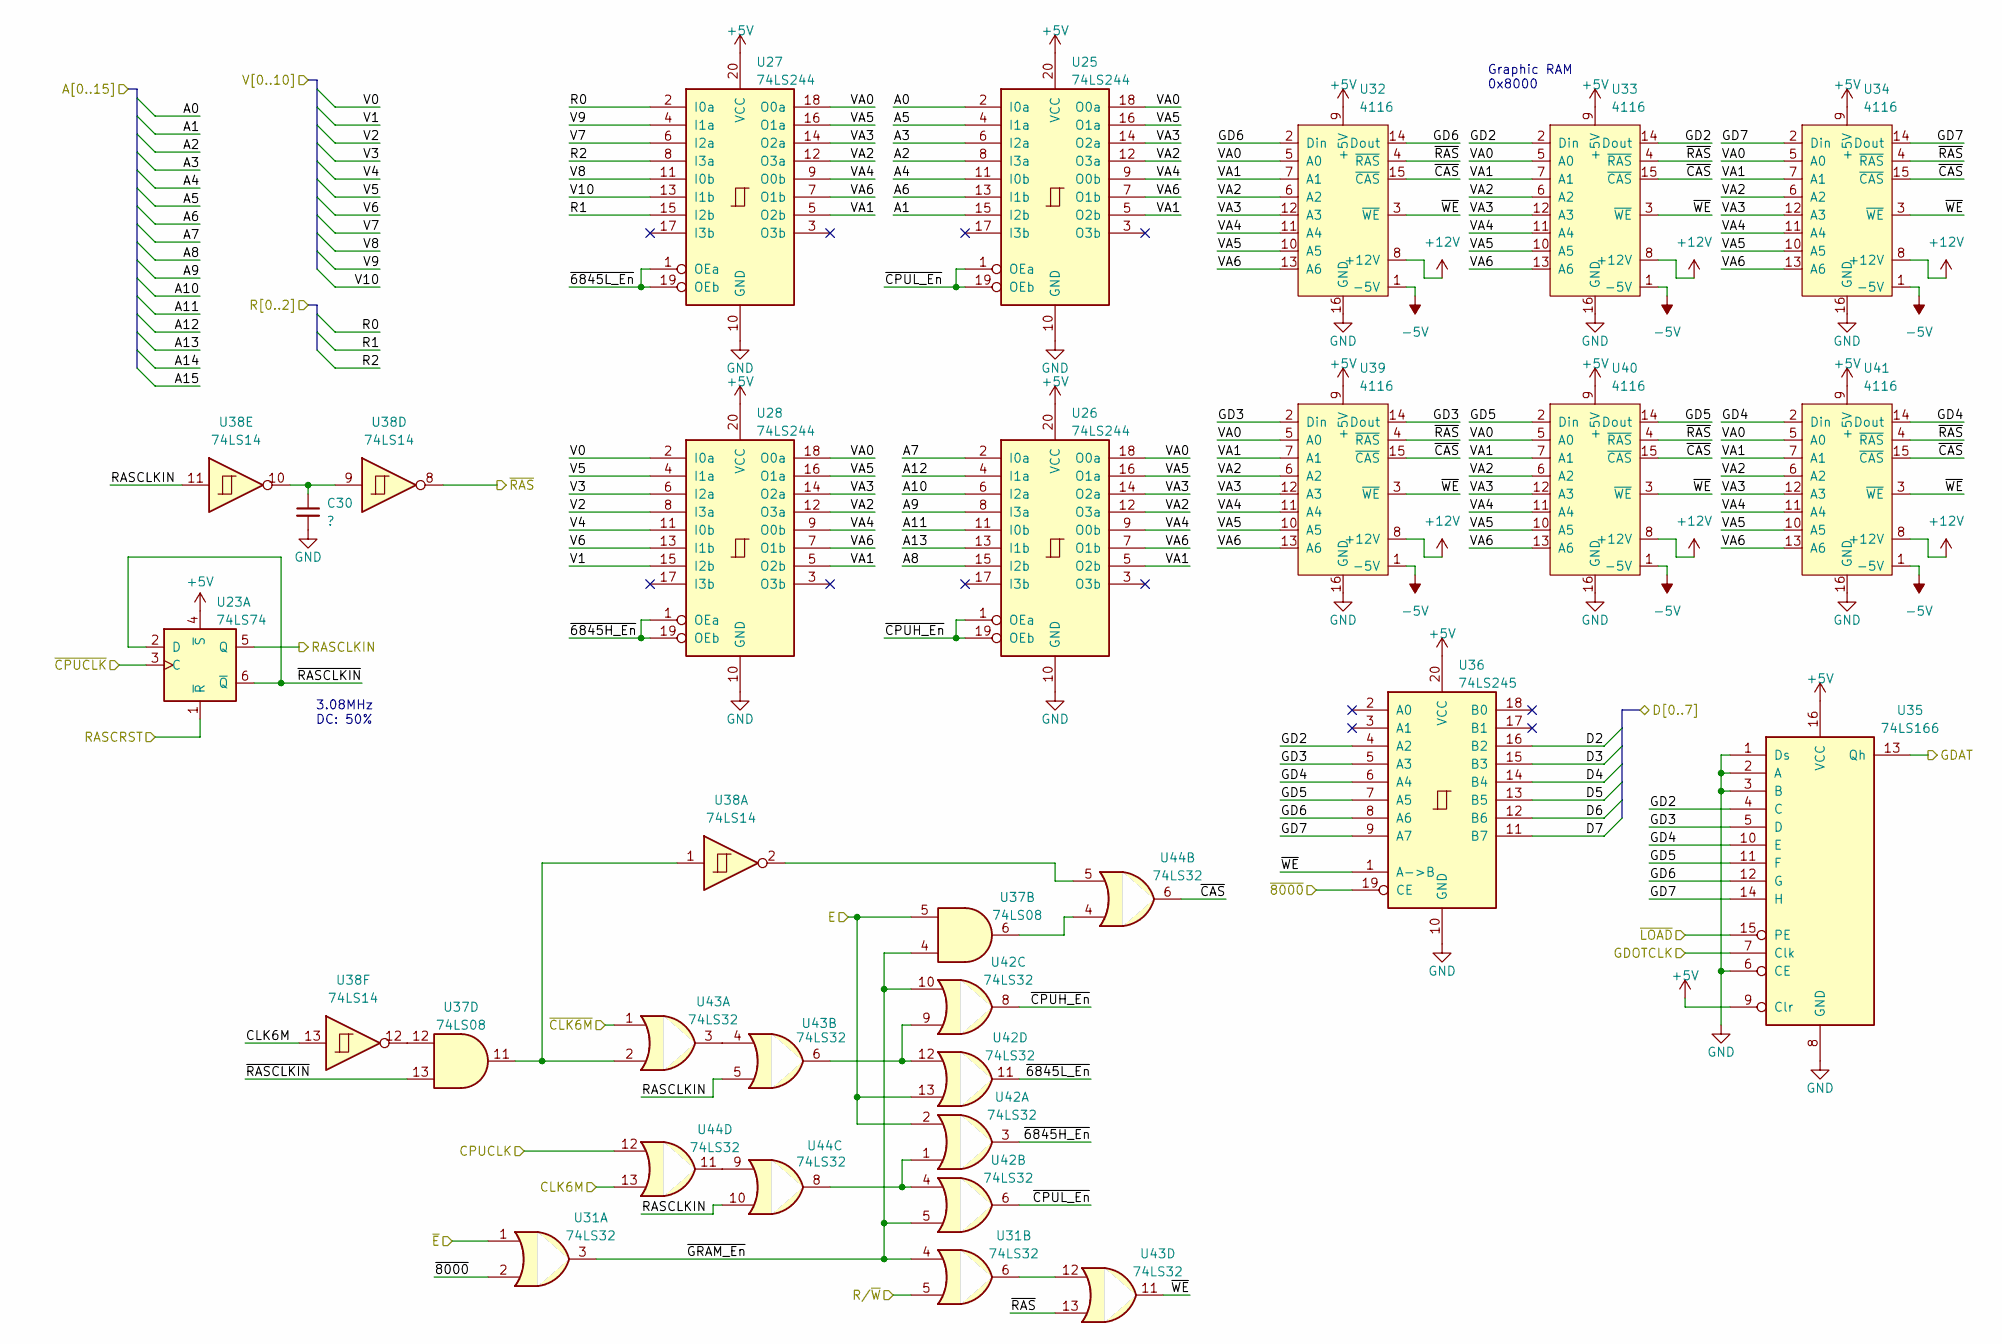
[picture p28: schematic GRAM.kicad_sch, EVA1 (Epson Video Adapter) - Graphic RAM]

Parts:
C30: ?; C_Disc_D4.7mm_W2.5mm_P5.00mm
U23: 74LS74; DIP-14_W7.62mm
U25, U26, U27, U28: 74LS244; DIP-20_W7.62mm
U31, U42, U43, U44: 74LS32; DIP-14_W7.62mm
U32, U33, U34, U39, U40, U41: 4116; DIP-16_W7.62mm
U35: 74LS166; DIP-16_W7.62mm
U36: 74LS245; DIP-20_W7.62mm
U37: 74LS08; DIP-14_W7.62mm
U38: 74LS14; DIP-14_W7.62mm

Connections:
+5V: U23.4 (~S), U25.20 (VCC), U26.20 (VCC), U27.20 (VCC), U28.20 (VCC), U32.9 (+5V), U33.9 (+5V), U34.9 (+5V), U35.9 (Clr), U35.16 (VCC), U36.20 (VCC), U39.9 (+5V), U40.9 (+5V), U41.9 (+5V); also elsewhere on the board
+12V: U32.8 (+12V), U33.8 (+12V), U34.8 (+12V), U39.8 (+12V), U40.8 (+12V), U41.8 (+12V); also elsewhere on the board
-5V: U32.1 (-5V), U33.1 (-5V), U34.1 (-5V), U39.1 (-5V), U40.1 (-5V), U41.1 (-5V); also elsewhere on the board
/A0: U25.2 (I0a); also elsewhere on the board
/A1: U25.15 (I2b); also elsewhere on the board
/A2: U25.8 (I3a); also elsewhere on the board
/A3: U25.6 (I2a); also elsewhere on the board
/A4: U25.11 (I0b); also elsewhere on the board
/A5: U25.4 (I1a); also elsewhere on the board
/A6: U25.13 (I1b); also elsewhere on the board
/A7: U26.2 (I0a); also elsewhere on the board
/A8: U26.15 (I2b); also elsewhere on the board
/A9: U26.8 (I3a); also elsewhere on the board
/A10: U26.6 (I2a); also elsewhere on the board
/A11: U26.11 (I0b); also elsewhere on the board
/A12: U26.4 (I1a); also elsewhere on the board
/A13: U26.13 (I1b); also elsewhere on the board
/CLK6M: U38.13, U44.13; also elsewhere on the board
/CPUCLK: U44.12; also elsewhere on the board
/D2: U36.16 (B2); also elsewhere on the board
/D3: U36.15 (B3); also elsewhere on the board
/D4: U36.14 (B4); also elsewhere on the board
/D5: U36.13 (B5); also elsewhere on the board
/D6: U36.12 (B6); also elsewhere on the board
/D7: U36.11 (B7); also elsewhere on the board
/E: U37.5, U42.2, U42.13; also elsewhere on the board
/GDAT: U35.13 (Qh); also elsewhere on the board
/GDOTCLK: U35.7 (Clk); also elsewhere on the board
/Graphic RAM, MUX and Shiftregister/GD2: U33.2 (Din), U33.14 (Dout), U35.4 (C), U36.4 (A2)
/Graphic RAM, MUX and Shiftregister/GD3: U35.5 (D), U36.5 (A3), U39.2 (Din), U39.14 (Dout)
/Graphic RAM, MUX and Shiftregister/GD4: U35.10 (E), U36.6 (A4), U41.2 (Din), U41.14 (Dout)
/Graphic RAM, MUX and Shiftregister/GD5: U35.11 (F), U36.7 (A5), U40.2 (Din), U40.14 (Dout)
/Graphic RAM, MUX and Shiftregister/GD6: U32.2 (Din), U32.14 (Dout), U35.12 (G), U36.8 (A6)
/Graphic RAM, MUX and Shiftregister/GD7: U34.2 (Din), U34.14 (Dout), U35.14 (H), U36.9 (A7)
/Graphic RAM, MUX and Shiftregister/RASCLKIN: U23.5 (Q), U38.11, U43.5, U44.10; also elsewhere on the board
/Graphic RAM, MUX and Shiftregister/VA0: U25.18 (O0a), U26.18 (O0a), U27.18 (O0a), U28.18 (O0a), U32.5 (A0), U33.5 (A0), U34.5 (A0), U39.5 (A0), U40.5 (A0), U41.5 (A0)
/Graphic RAM, MUX and Shiftregister/VA1: U25.5 (O2b), U26.5 (O2b), U27.5 (O2b), U28.5 (O2b), U32.7 (A1), U33.7 (A1), U34.7 (A1), U39.7 (A1), U40.7 (A1), U41.7 (A1)
/Graphic RAM, MUX and Shiftregister/VA2: U25.12 (O3a), U26.12 (O3a), U27.12 (O3a), U28.12 (O3a), U32.6 (A2), U33.6 (A2), U34.6 (A2), U39.6 (A2), U40.6 (A2), U41.6 (A2)
/Graphic RAM, MUX and Shiftregister/VA3: U25.14 (O2a), U26.14 (O2a), U27.14 (O2a), U28.14 (O2a), U32.12 (A3), U33.12 (A3), U34.12 (A3), U39.12 (A3), U40.12 (A3), U41.12 (A3)
/Graphic RAM, MUX and Shiftregister/VA4: U25.9 (O0b), U26.9 (O0b), U27.9 (O0b), U28.9 (O0b), U32.11 (A4), U33.11 (A4), U34.11 (A4), U39.11 (A4), U40.11 (A4), U41.11 (A4)
/Graphic RAM, MUX and Shiftregister/VA5: U25.16 (O1a), U26.16 (O1a), U27.16 (O1a), U28.16 (O1a), U32.10 (A5), U33.10 (A5), U34.10 (A5), U39.10 (A5), U40.10 (A5), U41.10 (A5)
/Graphic RAM, MUX and Shiftregister/VA6: U25.7 (O1b), U26.7 (O1b), U27.7 (O1b), U28.7 (O1b), U32.13 (A6), U33.13 (A6), U34.13 (A6), U39.13 (A6), U40.13 (A6), U41.13 (A6)
/Graphic RAM, MUX and Shiftregister/~6845H_En: U28.1 (OEa), U28.19 (OEb), U42.3
/Graphic RAM, MUX and Shiftregister/~6845L_En: U27.1 (OEa), U27.19 (OEb), U42.11
/Graphic RAM, MUX and Shiftregister/~CAS: U32.15 (~CAS), U33.15 (~CAS), U34.15 (~CAS), U39.15 (~CAS), U40.15 (~CAS), U41.15 (~CAS), U44.6
/Graphic RAM, MUX and Shiftregister/~CPUH_En: U26.1 (OEa), U26.19 (OEb), U42.8
/Graphic RAM, MUX and Shiftregister/~CPUL_En: U25.1 (OEa), U25.19 (OEb), U42.6
/Graphic RAM, MUX and Shiftregister/~GRAM_En: U31.3, U31.4, U37.4, U42.5, U42.10
/Graphic RAM, MUX and Shiftregister/~RASCLKIN: U23.2 (D), U23.6 (~Q), U37.13
/Graphic RAM, MUX and Shiftregister/~WE: U32.3 (~WE), U33.3 (~WE), U34.3 (~WE), U36.1 (A->B), U39.3 (~WE), U40.3 (~WE), U41.3 (~WE), U43.11
/R0: U27.2 (I0a); also elsewhere on the board
/R1: U27.15 (I2b); also elsewhere on the board
/R2: U27.8 (I3a); also elsewhere on the board
/RASCRST: U23.1 (~R); also elsewhere on the board
/R/~W: U31.5; also elsewhere on the board
/V0: U28.2 (I0a); also elsewhere on the board
/V1: U28.15 (I2b); also elsewhere on the board
/V2: U28.8 (I3a); also elsewhere on the board
/V3: U28.6 (I2a); also elsewhere on the board
/V4: U28.11 (I0b); also elsewhere on the board
/V5: U28.4 (I1a); also elsewhere on the board
/V6: U28.13 (I1b); also elsewhere on the board
/V7: U27.6 (I2a); also elsewhere on the board
/V8: U27.11 (I0b); also elsewhere on the board
/V9: U27.4 (I1a); also elsewhere on the board
/V10: U27.13 (I1b); also elsewhere on the board
/~8000: U31.2, U36.19 (CE); also elsewhere on the board
/~CLK6M: U43.1; also elsewhere on the board
/~CPUCLK: U23.3 (C); also elsewhere on the board
/~E: U31.1; also elsewhere on the board
/~LOAD: U35.15 (PE); also elsewhere on the board
/~RAS: U32.4 (~RAS), U33.4 (~RAS), U34.4 (~RAS), U38.8, U39.4 (~RAS), U40.4 (~RAS), U41.4 (~RAS), U43.13; also elsewhere on the board
GND: C30.2, U25.10 (GND), U26.10 (GND), U27.10 (GND), U28.10 (GND), U32.16 (GND), U33.16 (GND), U34.16 (GND), U35.1 (Ds), U35.2 (A), U35.3 (B), U35.6 (CE), U35.8 (GND), U36.10 (GND), U39.16 (GND), U40.16 (GND), U41.16 (GND); also elsewhere on the board
unnamed: C30.1, U38.9, U38.10
unnamed: U31.6, U43.12
unnamed: U37.6, U44.4
unnamed: U37.11, U38.1, U43.2
unnamed: U37.12, U38.12
unnamed: U38.2, U44.5
unnamed: U42.1, U42.4, U44.8
unnamed: U42.9, U42.12, U43.6
unnamed: U43.3, U43.4
unnamed: U44.9, U44.11

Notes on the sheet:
Graphic RAM 0x8000
3.08MHz DC: 50%

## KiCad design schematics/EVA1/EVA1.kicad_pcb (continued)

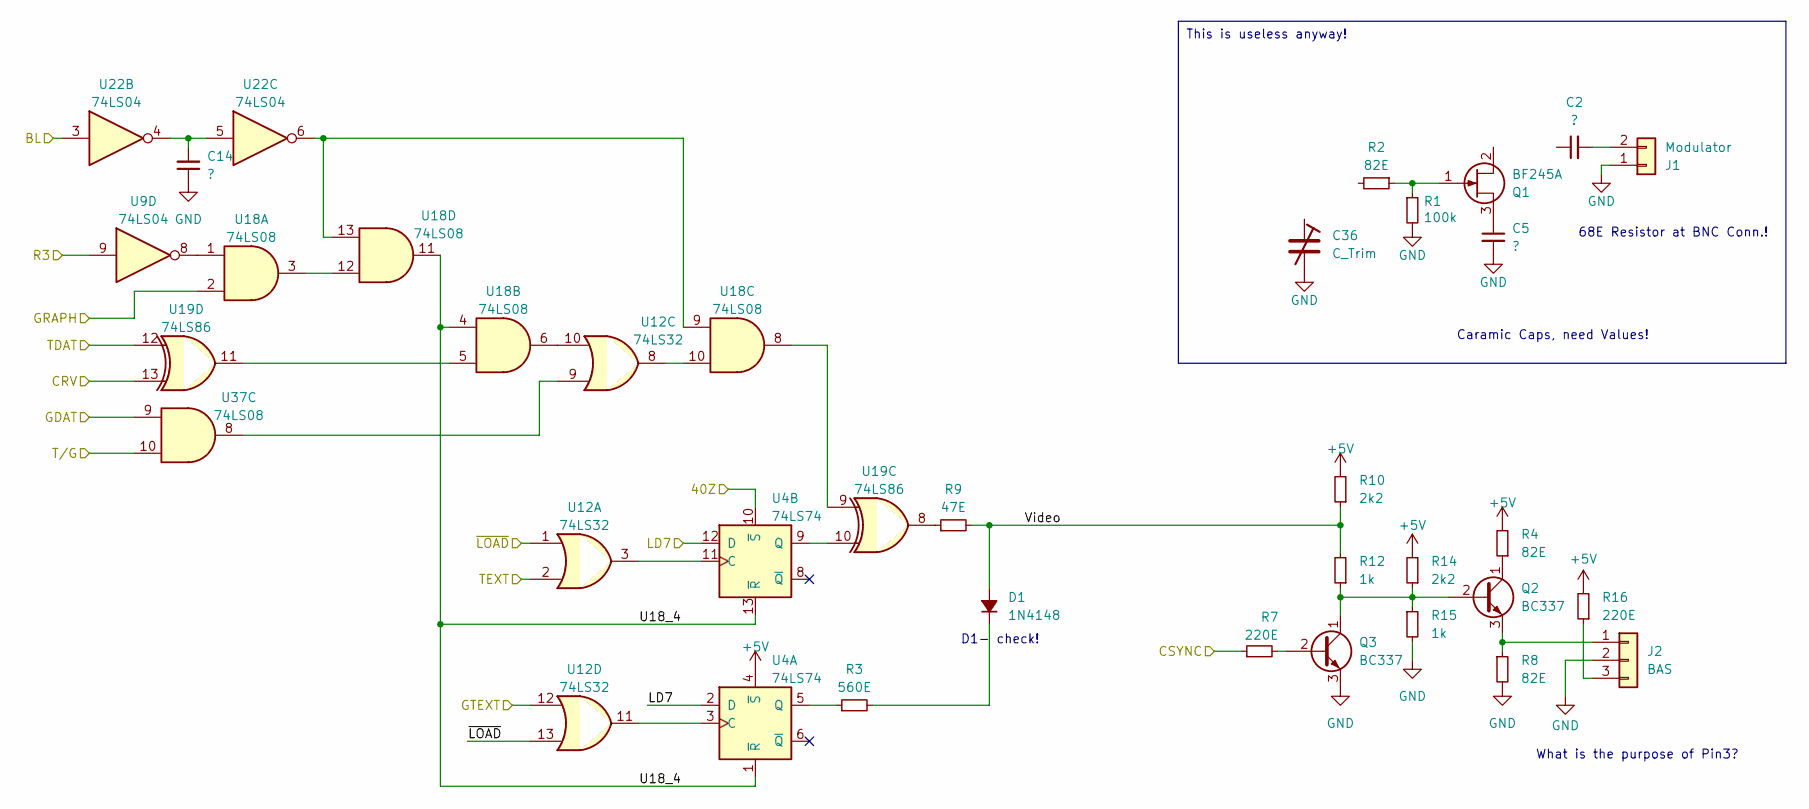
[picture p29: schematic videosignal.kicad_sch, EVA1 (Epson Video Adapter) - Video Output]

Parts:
C2, C5, C14: ?; C_Disc_D4.7mm_W2.5mm_P5.00mm
C36: C_Trim; C_Radial_D10.0mm_H20.0mm_P5.00mm
D1: 1N4148; D_A-405_P7.62mm_Horizontal
J1: Modulator; PinHeader_1x02_P2.54mm_Vertical
J2: BAS; PinHeader_1x03_P2.54mm_Vertical
Q1: BF245A; TO-92_Wide
Q2, Q3: BC337; TO-92_Wide
R1: 100k; R_Axial_DIN0411_L9.9mm_D3.6mm_P12.70mm_Horizontal
R2, R4, R8: 82E; R_Axial_DIN0411_L9.9mm_D3.6mm_P12.70mm_Horizontal
R3: 560E; R_Axial_DIN0411_L9.9mm_D3.6mm_P12.70mm_Horizontal
R7, R16: 220E; R_Axial_DIN0411_L9.9mm_D3.6mm_P12.70mm_Horizontal
R9: 47E; R_Axial_DIN0411_L9.9mm_D3.6mm_P12.70mm_Horizontal
R10, R14: 2k2; R_Axial_DIN0411_L9.9mm_D3.6mm_P12.70mm_Horizontal
R12, R15: 1k; R_Axial_DIN0411_L9.9mm_D3.6mm_P12.70mm_Horizontal
U4: 74LS74; DIP-14_W7.62mm
U9, U22: 74LS04; DIP-14_W7.62mm
U12: 74LS32; DIP-14_W7.62mm
U18, U37: 74LS08; DIP-14_W7.62mm
U19: 74LS86; DIP-14_W7.62mm

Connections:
+5V: R4.2, R10.2, R14.2, R16.2, U4.4 (~S); also elsewhere on the board
/BL: U22.3; also elsewhere on the board
/CRV: U19.13; also elsewhere on the board
/GDAT: U37.9; also elsewhere on the board
/GRAPH: U18.2; also elsewhere on the board
/GTEXT: U12.12; also elsewhere on the board
/LD7: U4.2 (D), U4.12 (D); also elsewhere on the board
/R3: U9.9; also elsewhere on the board
/TDAT: U19.12; also elsewhere on the board
/TEXT: U12.2; also elsewhere on the board
/T/G: U37.10; also elsewhere on the board
/Video Signal Genration/U18_4: U4.1 (~R), U4.13 (~R), U18.4, U18.11
/Video Signal Genration/Video: D1.2 (A), R9.2, R10.1, R12.2
/~40Z: U4.10 (~S); also elsewhere on the board
/~LOAD: U12.1, U12.13; also elsewhere on the board
GND: C5.2, C14.1, C36.2, J1.1, J2.2, Q3.3 (E), R1.2, R8.2, R15.2; also elsewhere on the board
unnamed: C14.2, U22.4, U22.5
unnamed: D1.1 (K), R3.2
unnamed: C2.2, J1.2
unnamed: J2.1, Q2.3 (E), R8.1
unnamed: J2.3, R16.1
unnamed: C5.1, Q1.3 (D)
unnamed: Q1.1 (G), R1.1, R2.1
unnamed: Q2.2 (B), Q3.1 (C), R12.1, R14.1, R15.1
unnamed: Q2.1 (C), R4.1
unnamed: Q3.2 (B), R7.2
unnamed 172: R7.1; also elsewhere on the board
unnamed: R9.1, U19.8
unnamed: U4.3 (C), U12.11
unnamed: R3.1, U4.5 (Q)
unnamed: U4.11 (C), U12.3
unnamed: U4.9 (Q), U19.10
unnamed: U12.8, U18.10
unnamed: U12.9, U37.8
unnamed: U12.10, U18.6
unnamed: U9.8, U18.1
unnamed: U18.5, U19.11
unnamed: U18.8, U19.9
unnamed: U18.3, U18.12
unnamed: U18.9, U18.13, U22.6

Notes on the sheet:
This is useless anyway!
D1- check!
Caramic Caps, need Values!
68E Resistor at BNC Conn.!
What is the purpose of Pin3?

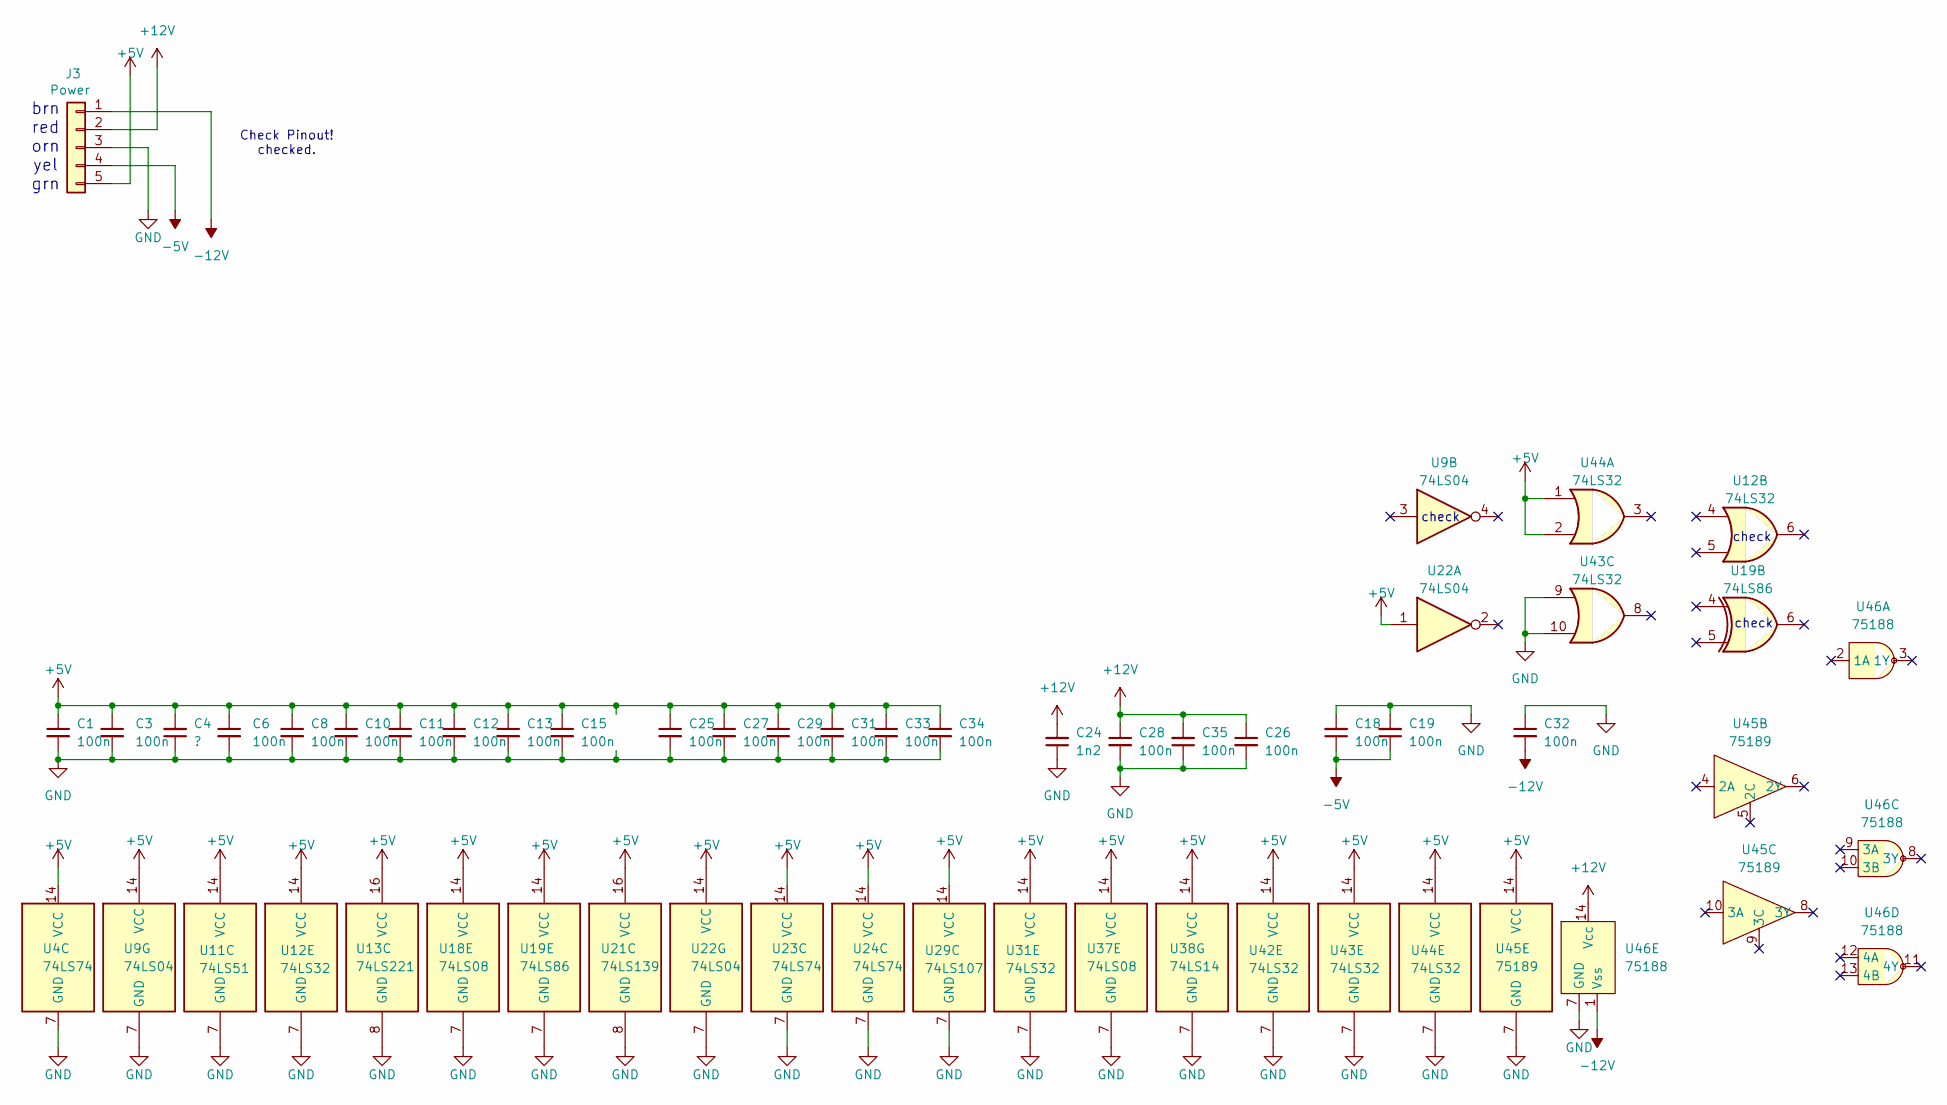
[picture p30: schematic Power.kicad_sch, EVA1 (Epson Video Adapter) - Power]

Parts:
C1, C3, C6, C8, C10, C11, C12, C13, C15, C18, C19, C25, C26, C27, C28, C29, C31, C32, C33, C34, C35: 100n; C_Disc_D4.7mm_W2.5mm_P5.00mm
C4: ?; C_Disc_D4.7mm_W2.5mm_P5.00mm
C24: 1n2; C_Disc_D4.7mm_W2.5mm_P5.00mm
J3: Power; PinHeader_1x05_P2.54mm_Vertical
U4, U23, U24: 74LS74; DIP-14_W7.62mm
U9, U22: 74LS04; DIP-14_W7.62mm
U11: 74LS51; DIP-14_W7.62mm
U12, U31, U42, U43, U44: 74LS32; DIP-14_W7.62mm
U13: 74LS221; DIP-16_W7.62mm
U18, U37: 74LS08; DIP-14_W7.62mm
U19: 74LS86; DIP-14_W7.62mm
U21: 74LS139; DIP-16_W7.62mm
U29: 74LS107; DIP-14_W7.62mm
U38: 74LS14; DIP-14_W7.62mm
U45: 75189; DIP-14_W7.62mm
U46: 75188; DIP-14_W7.62mm

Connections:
+5V: C1.1, C3.1, C4.2, C6.1, C8.1, C10.1, C11.1, C12.1, C13.1, C15.1, C25.1, C27.1, C29.1, C31.1, C33.1, C34.1, J3.5, U4.14 (VCC), U9.14 (VCC), U11.14 (VCC), U12.14 (VCC), U13.16 (VCC), U18.14 (VCC), U19.14 (VCC), U21.16 (VCC), U22.1, U22.14 (VCC), U23.14 (VCC), U24.14 (VCC), U29.14 (VCC), U31.14 (VCC), U37.14 (VCC), U38.14 (VCC), U42.14 (VCC), U43.14 (VCC), U44.1, U44.2, U44.14 (VCC), U45.14 (VCC); also elsewhere on the board
+12V: C24.2, C26.1, C28.1, C35.2, J3.2, U46.14 (Vcc); also elsewhere on the board
-5V: C18.1, C19.1, J3.4; also elsewhere on the board
-12V: C32.2, J3.1, U46.1 (Vss)
GND: C1.2, C3.2, C4.1, C6.2, C8.2, C10.2, C11.2, C12.2, C13.2, C15.2, C18.2, C19.2, C24.1, C25.2, C26.2, C27.2, C28.2, C29.2, C31.2, C32.1, C33.2, C34.2, C35.1, J3.3, U4.7 (GND), U9.7 (GND), U11.7 (GND), U12.7 (GND), U13.8 (GND), U18.7 (GND), U19.7 (GND), U21.8 (GND), U22.7 (GND), U23.7 (GND), U24.7 (GND), U29.7 (GND), U31.7 (GND), U37.7 (GND), U38.7 (GND), U42.7 (GND), U43.7 (GND), U43.9, U43.10, U44.7 (GND), U45.7 (GND), U46.7 (GND); also elsewhere on the board

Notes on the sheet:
Check Pinout! checked.
check
brn red orn yel grn

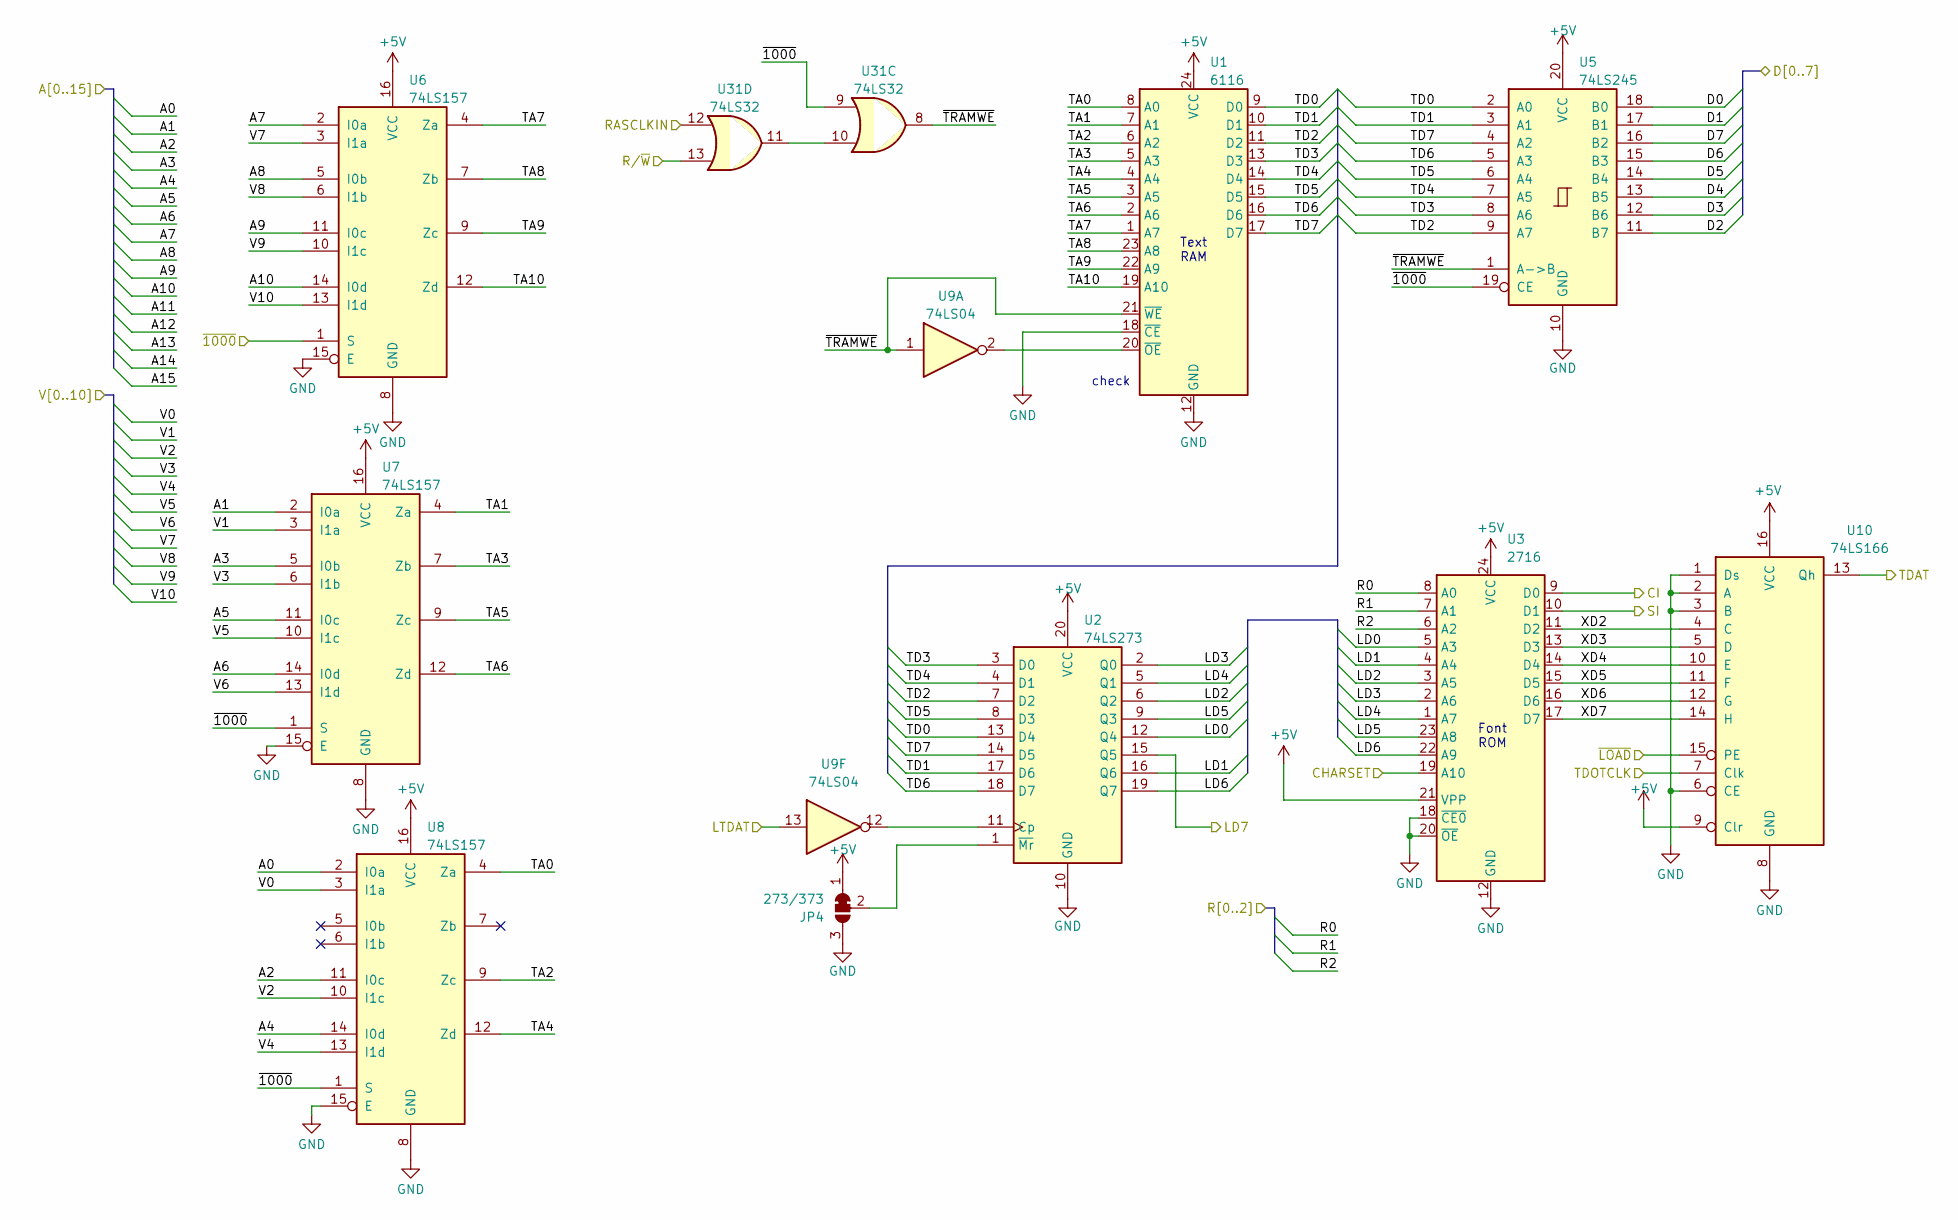
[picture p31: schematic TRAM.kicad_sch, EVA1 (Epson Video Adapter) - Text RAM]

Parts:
JP4: 273/373; SolderJumper-3_P1.3mm_Bridged12_RoundedPad1.0x1.5mm
U1: 6116; DIP-24_W15.24mm
U2: 74LS273; DIP-20_W7.62mm
U3: 2716; DIP-24_W15.24mm
U5: 74LS245; DIP-20_W7.62mm
U6, U7, U8: 74LS157; DIP-16_W7.62mm
U9: 74LS04; DIP-14_W7.62mm
U10: 74LS166; DIP-16_W7.62mm
U31: 74LS32; DIP-14_W7.62mm

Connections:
+5V: JP4.1 (A), U1.24 (VCC), U2.20 (VCC), U3.21 (VPP), U3.24 (VCC), U5.20 (VCC), U6.16 (VCC), U7.16 (VCC), U8.16 (VCC), U10.9 (Clr), U10.16 (VCC); also elsewhere on the board
/A0: U8.2 (I0a); also elsewhere on the board
/A1: U7.2 (I0a); also elsewhere on the board
/A2: U8.11 (I0c); also elsewhere on the board
/A3: U7.5 (I0b); also elsewhere on the board
/A4: U8.14 (I0d); also elsewhere on the board
/A5: U7.11 (I0c); also elsewhere on the board
/A6: U7.14 (I0d); also elsewhere on the board
/A7: U6.2 (I0a); also elsewhere on the board
/A8: U6.5 (I0b); also elsewhere on the board
/A9: U6.11 (I0c); also elsewhere on the board
/A10: U6.14 (I0d); also elsewhere on the board
/CHARSET: U3.19 (A10); also elsewhere on the board
/CI: U3.9 (D0)
/D0: U5.18 (B0); also elsewhere on the board
/D1: U5.17 (B1); also elsewhere on the board
/D2: U5.11 (B7); also elsewhere on the board
/D3: U5.12 (B6); also elsewhere on the board
/D4: U5.13 (B5); also elsewhere on the board
/D5: U5.14 (B4); also elsewhere on the board
/D6: U5.15 (B3); also elsewhere on the board
/D7: U5.16 (B2); also elsewhere on the board
/Graphic RAM, MUX and Shiftregister/RASCLKIN: U31.12; also elsewhere on the board
/LD7: U2.15 (Q5); also elsewhere on the board
/LTDAT: U9.13; also elsewhere on the board
/R0: U3.8 (A0); also elsewhere on the board
/R1: U3.7 (A1); also elsewhere on the board
/R2: U3.6 (A2); also elsewhere on the board
/R/~W: U31.13; also elsewhere on the board
/SI: U3.10 (D1)
/TDAT: U10.13 (Qh); also elsewhere on the board
/TDOTCLK: U10.7 (Clk); also elsewhere on the board
/Text RAM, MUX and Shiftregister1/LD0: U2.12 (Q4), U3.5 (A3)
/Text RAM, MUX and Shiftregister1/LD1: U2.16 (Q6), U3.4 (A4)
/Text RAM, MUX and Shiftregister1/LD2: U2.6 (Q2), U3.3 (A5)
/Text RAM, MUX and Shiftregister1/LD3: U2.2 (Q0), U3.2 (A6)
/Text RAM, MUX and Shiftregister1/LD4: U2.5 (Q1), U3.1 (A7)
/Text RAM, MUX and Shiftregister1/LD5: U2.9 (Q3), U3.23 (A8)
/Text RAM, MUX and Shiftregister1/LD6: U2.19 (Q7), U3.22 (A9)
/Text RAM, MUX and Shiftregister1/TA0: U1.8 (A0), U8.4 (Za)
/Text RAM, MUX and Shiftregister1/TA1: U1.7 (A1), U7.4 (Za)
/Text RAM, MUX and Shiftregister1/TA2: U1.6 (A2), U8.9 (Zc)
/Text RAM, MUX and Shiftregister1/TA3: U1.5 (A3), U7.7 (Zb)
/Text RAM, MUX and Shiftregister1/TA4: U1.4 (A4), U8.12 (Zd)
/Text RAM, MUX and Shiftregister1/TA5: U1.3 (A5), U7.9 (Zc)
/Text RAM, MUX and Shiftregister1/TA6: U1.2 (A6), U7.12 (Zd)
/Text RAM, MUX and Shiftregister1/TA7: U1.1 (A7), U6.4 (Za)
/Text RAM, MUX and Shiftregister1/TA8: U1.23 (A8), U6.7 (Zb)
/Text RAM, MUX and Shiftregister1/TA9: U1.22 (A9), U6.9 (Zc)
/Text RAM, MUX and Shiftregister1/TA10: U1.19 (A10), U6.12 (Zd)
/Text RAM, MUX and Shiftregister1/TD0: U1.9 (D0), U2.13 (D4), U5.2 (A0)
/Text RAM, MUX and Shiftregister1/TD1: U1.10 (D1), U2.17 (D6), U5.3 (A1)
/Text RAM, MUX and Shiftregister1/TD2: U1.11 (D2), U2.7 (D2), U5.9 (A7)
/Text RAM, MUX and Shiftregister1/TD3: U1.13 (D3), U2.3 (D0), U5.8 (A6)
/Text RAM, MUX and Shiftregister1/TD4: U1.14 (D4), U2.4 (D1), U5.7 (A5)
/Text RAM, MUX and Shiftregister1/TD5: U1.15 (D5), U2.8 (D3), U5.6 (A4)
/Text RAM, MUX and Shiftregister1/TD6: U1.16 (D6), U2.18 (D7), U5.5 (A3)
/Text RAM, MUX and Shiftregister1/TD7: U1.17 (D7), U2.14 (D5), U5.4 (A2)
/Text RAM, MUX and Shiftregister1/TRAMWE: U1.20 (~OE), U9.2
/Text RAM, MUX and Shiftregister1/XD2: U3.11 (D2), U10.4 (C)
/Text RAM, MUX and Shiftregister1/XD3: U3.13 (D3), U10.5 (D)
/Text RAM, MUX and Shiftregister1/XD4: U3.14 (D4), U10.10 (E)
/Text RAM, MUX and Shiftregister1/XD5: U3.15 (D5), U10.11 (F)
/Text RAM, MUX and Shiftregister1/XD6: U3.16 (D6), U10.12 (G)
/Text RAM, MUX and Shiftregister1/XD7: U3.17 (D7), U10.14 (H)
/Text RAM, MUX and Shiftregister1/~TRAMWE: U1.21 (~WE), U5.1 (A->B), U9.1, U31.8
/V0: U8.3 (I1a); also elsewhere on the board
/V1: U7.3 (I1a); also elsewhere on the board
/V2: U8.10 (I1c); also elsewhere on the board
/V3: U7.6 (I1b); also elsewhere on the board
/V4: U8.13 (I1d); also elsewhere on the board
/V5: U7.10 (I1c); also elsewhere on the board
/V6: U7.13 (I1d); also elsewhere on the board
/V7: U6.3 (I1a); also elsewhere on the board
/V8: U6.6 (I1b); also elsewhere on the board
/V9: U6.10 (I1c); also elsewhere on the board
/V10: U6.13 (I1d); also elsewhere on the board
/~1000: U5.19 (CE), U6.1 (S), U7.1 (S), U8.1 (S), U31.9; also elsewhere on the board
/~LOAD: U10.15 (PE); also elsewhere on the board
GND: JP4.3 (B), U1.12 (GND), U1.18 (~CE), U2.10 (GND), U3.12 (GND), U3.18 (~CE0), U3.20 (~OE), U5.10 (GND), U6.8 (GND), U6.15 (E), U7.8 (GND), U7.15 (E), U8.8 (GND), U8.15 (E), U10.1 (Ds), U10.2 (A), U10.3 (B), U10.6 (CE), U10.8 (GND); also elsewhere on the board
unnamed: JP4.2 (C), U2.1 (~Mr)
unnamed: U2.11 (Cp), U9.12
unnamed: U31.10, U31.11

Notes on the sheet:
Font ROM
check
Text RAM


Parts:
C16, C17, C20, C21: ?; C_Disc_D4.7mm_W2.5mm_P5.00mm
R13, R17, R20: 470E; R_Axial_DIN0411_L9.9mm_D3.6mm_P12.70mm_Horizontal
R18: ?; R_Axial_DIN0204_L3.6mm_D1.6mm_P5.08mm_Horizontal
R19: 10k; R_Axial_DIN0204_L3.6mm_D1.6mm_P5.08mm_Horizontal
U22: 74LS04; DIP-14_W7.62mm
U29: 74LS107; DIP-14_W7.62mm
U30: LM733CN; DIP-14_W7.62mm
Y1: 18M432; Crystal_HC49-U_Vertical

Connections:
+5V: U29.4 (K), U29.10 (~R), U29.13 (~R); also elsewhere on the board
+12V: R20.2, U30.10 (V+); also elsewhere on the board
/CLK6M: U29.5 (Q); also elsewhere on the board
/CLK18M: U22.8, U29.9 (C), U29.12 (C); also elsewhere on the board
/CPUCLK: U29.3 (Q), U29.8 (J); also elsewhere on the board
/~CLK6M: U29.1 (J), U29.6 (~Q); also elsewhere on the board
/~CPUCLK: U29.2 (~Q), U29.11 (K); also elsewhere on the board
GND: C17.2, C20.2, C21.2, R13.1, R17.2, U30.5 (V-); also elsewhere on the board
unnamed: C16.1, R13.2, U22.9
unnamed: C16.2, U30.8
unnamed: C17.1, R17.1, R19.2, R20.1, U30.1
unnamed: C20.1, U30.7, Y1.1
unnamed: C21.1, R18.2, R19.1, U30.14, Y1.2
unnamed: R18.1, U30.11 (1A)

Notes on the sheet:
U29-2: 6.1MHz DC: 66%
6.1MHz
U29-5: 6.1MHz DC: 33%


Board: 2 copper layers, 218.0 x 125.0 mm, 126 parts (1 on the bottom side), 207 nets.

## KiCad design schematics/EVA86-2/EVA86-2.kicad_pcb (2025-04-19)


Board: 2 copper layers, 86 parts (0 on the bottom side), 172 nets.

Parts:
C3: 47u/25; CP_Radial_D8.0mm_P5.00mm
C4, C5, C8, C13, C14, C15, C16, C18, C19, C20, C27: 100n; C_Disc_D4.7mm_W2.5mm_P5.00mm
C6: 22p; C_Disc_D4.7mm_W2.5mm_P5.00mm
C7: 47p; C_Disc_D4.7mm_W2.5mm_P5.00mm
C9: 47u; CP_Radial_D8.0mm_P5.00mm
C10: 220p; C_Disc_D4.7mm_W2.5mm_P5.00mm
C23, C24, C25, C26, C28, C29, C30: 22n; C_Disc_D4.7mm_W2.5mm_P5.00mm
Q1, Q2, Q3, Q4: BC337; TO-92_Inline
R1, R14: 2k2; R_Axial_DIN0411_L9.9mm_D3.6mm_P12.70mm_Horizontal
R2, R4, R6, R7, R8, R9, R17, R21: 1k; R_Axial_DIN0411_L9.9mm_D3.6mm_P12.70mm_Horizontal
R3, R12, R23: 10k; R_Axial_DIN0411_L9.9mm_D3.6mm_P12.70mm_Horizontal
R5: 4k7; R_Axial_DIN0411_L9.9mm_D3.6mm_P12.70mm_Horizontal
R10: 100E; R_Axial_DIN0411_L9.9mm_D3.6mm_P12.70mm_Horizontal
R11, R18, R22: 220E; R_Axial_DIN0411_L9.9mm_D3.6mm_P12.70mm_Horizontal
R13, R24: 100k; R_Axial_DIN0411_L9.9mm_D3.6mm_P12.70mm_Horizontal
R15, R25: 1k2; R_Axial_DIN0411_L9.9mm_D3.6mm_P12.70mm_Horizontal
R16: 390E; R_Axial_DIN0411_L9.9mm_D3.6mm_P12.70mm_Horizontal
R19: 82E; R_Axial_DIN0411_L9.9mm_D3.6mm_P12.70mm_Horizontal
R20: 10E; R_Axial_DIN0411_L9.9mm_D3.6mm_P12.70mm_Horizontal
U1: MC6803; DIP-40_W15.24mm_LongPads
U2: 74LS373; DIP-20_W7.62mm_LongPads
U3: 74LS139; DIP-16_W7.62mm_LongPads
U4: 27C64; DIP-28_W15.24mm_LongPads
U5, U7, U8, U9, U10: 74LS257; DIP-16_W7.62mm_LongPads
U6: MC6845; DIP-40_W15.24mm
U11, U31: 74LS86; DIP-14_W7.62mm_LongPads
U12, U25, U30: 74LS00; DIP-14_W7.62mm_LongPads
U13, U20: 74LS245; DIP-20_W7.62mm_LongPads
U14, U21: 74LS165; DIP-16_W7.62mm_LongPads
U15, U16, U19: UM6264DM; DIP-28_W15.24mm_LongPads
U17, U24: 74LS74; DIP-14_W7.62mm_LongPads
U18, U33: 74LS32; DIP-14_W7.62mm_LongPads
U22: 27C32; DIP-24_W15.24mm
U23: 74HC04; DIP-14_W7.62mm_LongPads
U26, U27: 74LS293; DIP-14_W7.62mm_LongPads
U28, U29: 74LS107; DIP-14_W7.62mm_LongPads
U32: 74LS08; DIP-14_W7.62mm_LongPads
Y1: 19M66; Crystal_HC49-U_Vertical

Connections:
+5V: C4.2, C13.1, C14.1, C15.1, C16.1, C18.1, C19.1, C20.1, C23.1, C24.1, C25.1, C26.1, C27.1, C28.1, C29.1, C30.1, Q4.1 (C), R5.1, R12.1, R17.1, R21.1, R23.1, U1.4 (~NMI), U1.7 (VCC), U1.21 (VCC_STBY), U2.20 (VCC), U3.16 (VCC), U4.1 (VPP), U4.27 (~PGM), U4.28 (VCC), U5.16 (VCC), U6.20 (VCC), U7.16 (VCC), U8.16 (VCC), U9.16 (VCC), U10.16 (VCC), U11.9, U11.13, U11.14 (VCC), U12.12, U12.14 (VCC), U13.20 (VCC), U14.16 (VCC), U15.26 (CS2), U15.28 (VDD), U16.26 (CS2), U16.28 (VDD), U17.1 (~R), U17.4 (~S), U17.10 (~S), U17.13 (~R), U17.14 (VCC), U18.14 (VCC), U19.26 (CS2), U19.28 (VDD), U20.20 (VCC), U21.16 (VCC), U22.24 (VCC), U23.14 (VCC), U24.1 (~R), U24.11 (C), U24.12 (D), U24.14 (VCC), U25.12, U25.14 (VCC), U26.14 (VCC), U27.13 (Mr2), U27.14 (VCC), U28.1 (J), U28.4 (K), U28.13 (~R), U28.14 (VCC), U29.4 (K), U29.13 (~R), U29.14 (VCC), U30.14 (VCC), U31.5, U31.12, U31.14 (VCC), U32.14 (VCC), U33.14 (VCC)
+12V: C3.2, R2.1, R7.1, R10.2
/A0: U2.6 (O2), U4.10 (A0), U5.2 (I0a), U6.24 (RS)
/A1: U2.16 (O6), U4.9 (A1), U5.5 (I0b)
/A2: U2.19 (O7), U4.8 (A2), U5.11 (I0d)
/A3: U2.2 (O0), U4.7 (A3), U5.14 (I0c)
/A4: U2.5 (O1), U4.6 (A4), U7.2 (I0a)
/A5: U2.9 (O3), U4.5 (A5), U7.5 (I0b)
/A6: U2.12 (O4), U4.4 (A6), U7.11 (I0d), U9.5 (I0b)
/A7: U2.15 (O5), U4.3 (A7), U7.14 (I0c), U9.2 (I0a)
/A8: U1.29 (P40/A8), U4.25 (A8), U8.5 (I0b), U9.11 (I0d)
/A9: U1.28 (P41/A9), U4.24 (A9), U8.2 (I0a), U9.14 (I0c)
/A10: U1.27 (P42/A10), U4.21 (A10), U8.14 (I0c), U10.2 (I0a)
/A11: U1.26 (P43/A11), U4.23 (A11), U8.11 (I0d), U10.5 (I0b)
/A12: U1.25 (P44/A12), U3.2 (A0), U4.2 (A12), U10.11 (I0d)
/A13: U1.24 (P45/A13), U3.3 (A1), U10.14 (I0c)
/A14: U1.23 (P46/A14), U3.14 (A0)
/A15: U1.22 (P47/A15), U3.13 (A1)
/CPUCLK: U1.3 (EXTAL), U12.8
/Clock/GRAPH: R14.1, U12.13, U28.10 (~R)
/Clock/~GRAPH: U12.11, U29.10 (~R)
/D0: U1.37 (P30/AD0), U2.7 (D2), U4.11 (D0), U6.33 (D0), U13.16 (B2), U20.17 (B1)
/D1: U1.36 (P31/AD1), U2.17 (D6), U4.12 (D1), U6.32 (D1), U13.14 (B4), U20.15 (B3)
/D2: U1.35 (P32/AD2), U2.18 (D7), U4.13 (D2), U6.31 (D2), U13.12 (B6), U20.12 (B6)
/D3: U1.34 (P33/AD3), U2.3 (D0), U4.15 (D3), U6.30 (D3), U13.11 (B7), U20.14 (B4)
/D4: U1.33 (P34/AD4), U2.4 (D1), U4.16 (D4), U6.29 (D4), U13.13 (B5), U20.13 (B5)
/D5: U1.32 (P35/AD5), U2.8 (D3), U4.17 (D5), U6.28 (D5), U13.15 (B3), U20.11 (B7)
/D6: U1.31 (P36/AD6), U2.13 (D4), U4.18 (D6), U6.27 (D6), U13.17 (B1), U20.16 (B2)
/D7: U1.30 (P37/AD7), U2.14 (D5), U4.19 (D7), U6.26 (D7), U13.18 (B0), U20.18 (B0)
/DOTCLK: U14.2 (CP), U21.2 (CP), U28.2 (~Q)
/DOUT: R3.1, R8.2
/DOUT#: Q3.1 (C), R7.2
/E: R15.1, U1.40 (E), U3.15 (E), U6.23 (E), U31.2
/GA0: U5.4 (Za), U15.10 (A0), U16.10 (A0), U19.10 (A0)
/GA1: U5.7 (Zb), U15.9 (A1), U16.9 (A1), U19.9 (A1)
/GA2: U5.9 (Zd), U15.8 (A2), U16.8 (A2), U19.8 (A2)
/GA3: U5.12 (Zc), U15.7 (A3), U16.7 (A3), U19.7 (A3)
/GA4: U7.4 (Za), U15.6 (A4), U16.6 (A4), U19.6 (A4)
/GA5: U7.7 (Zb), U15.5 (A5), U16.5 (A5), U19.5 (A5)
/GA6: U9.7 (Zb), U15.4 (A6), U16.4 (A6)
/GA7: U9.4 (Za), U15.3 (A7), U16.3 (A7)
/GA8: U9.9 (Zd), U15.25 (A8), U16.25 (A8)
/GA9: U9.12 (Zc), U15.24 (A9), U16.24 (A9)
/GA10: U10.4 (Za), U15.21 (A10), U16.21 (A10)
/GA11: U10.7 (Zb), U15.23 (A11), U16.23 (A11)
/GA12: U10.9 (Zd), U15.2 (A12), U16.2 (A12)
/GA13: U10.12 (Zc), U11.12, U15.20 (~CS1)
/GRAPH: U1.14 (P11/TOUT2), U12.1
/GTEXT: U1.15 (P12/TOUT3), U19.2 (A12)
/Graphics/BL: U6.18 (DE), U17.12 (D)
/Graphics/CI: U18.4, U22.9 (D0)
/Graphics/CRV: U6.19 (CURSOR), U17.2 (D)
/Graphics/GD0: U13.4 (A2), U14.11 (D0), U15.11 (DQ0), U16.11 (DQ0)
/Graphics/GD1: U13.6 (A4), U14.12 (D1), U15.12 (DQ1), U16.12 (DQ1)
/Graphics/GD2: U13.8 (A6), U14.13 (D2), U15.13 (DQ2), U16.13 (DQ2)
/Graphics/GD3: U13.9 (A7), U14.14 (D3), U15.15 (DQ3), U16.15 (DQ3)
/Graphics/GD4: U13.7 (A5), U14.3 (D4), U15.16 (DQ4), U16.16 (DQ4)
/Graphics/GD5: U13.5 (A3), U14.4 (D5), U15.17 (DQ5), U16.17 (DQ5)
/Graphics/GD6: U13.3 (A1), U14.5 (D6), U15.18 (DQ6), U16.18 (DQ6)
/Graphics/GD7: U13.2 (A0), U14.6 (D7), U15.19 (DQ7), U16.19 (DQ7)
/Graphics/GDAT: U12.2, U14.9 (Q7)
/Graphics/PX0: U21.13 (D2), U22.11 (D2)
/Graphics/PX1: U21.14 (D3), U22.13 (D3)
/Graphics/PX2: U21.3 (D4), U22.14 (D4)
/Graphics/PX3: U21.4 (D5), U22.15 (D5)
/Graphics/PX4: U21.5 (D6), U22.16 (D6)
/Graphics/PX5: U21.6 (D7), U22.17 (D7)
/Graphics/R3: U6.35 (RA3), U25.13
/Graphics/SI: U22.10 (D1), U24.2 (D)
/Graphics/TD0: U19.11 (DQ0), U20.3 (A1), U22.5 (A3)
/Graphics/TD1: U19.12 (DQ1), U20.5 (A3), U22.4 (A4)
/Graphics/TD2: U19.13 (DQ2), U20.8 (A6), U22.3 (A5)
/Graphics/TD3: U19.15 (DQ3), U20.6 (A4), U22.2 (A6)
/Graphics/TD4: U19.16 (DQ4), U20.7 (A5), U22.1 (A7)
/Graphics/TD5: U19.17 (DQ5), U20.9 (A7), U22.23 (A8)
/Graphics/TD6: U19.18 (DQ6), U20.4 (A2), U22.22 (A9)
/Graphics/TD7: U19.19 (DQ7), U20.2 (A0), U22.19 (A10)
/Graphics/TDAT: U11.5, U21.9 (Q7)
/Graphics/~GWR: U13.1 (A->B), U15.27 (~WE), U16.27 (~WE), U18.11
/Graphics/~TWR: U18.3, U19.27 (~WE), U20.1 (A->B)
/OPT: U1.20 (P17), U22.21 (A11)
/RX: Q2.1 (C), R5.2, U1.11 (P23/RX)
/R/~W: U1.38 (SC2/R/~W), U6.22 (R/~W), U33.12
/TA6: U7.9 (Zd), U19.4 (A6)
/TA7: U7.12 (Zc), U19.3 (A7)
/TA8: U8.7 (Zb), U19.25 (A8)
/TA9: U8.4 (Za), U19.24 (A9)
/TA10: U8.12 (Zc), U19.21 (A10)
/TA11: U8.9 (Zd), U19.23 (A11)
/TEXT: U1.16 (P13), U12.4
/TX: R6.2, U1.12 (P24/TX)
/Video/R0: U6.38 (RA0), U9.6 (I1b)
/Video/R1: U6.37 (RA1), U9.3 (I1a)
/Video/R2: U6.36 (RA2), U9.10 (I1d)
/Video/V0: U5.3 (I1a), U6.4 (MA0)
/Video/V1: U5.6 (I1b), U6.5 (MA1)
/Video/V2: U5.10 (I1d), U6.6 (MA2)
/Video/V3: U5.13 (I1c), U6.7 (MA3)
/Video/V4: U6.8 (MA4), U7.3 (I1a)
/Video/V5: U6.9 (MA5), U7.6 (I1b)
/Video/V6: U6.10 (MA6), U7.10 (I1d), U9.13 (I1c)
/Video/V7: U6.11 (MA7), U7.13 (I1c), U10.3 (I1a)
/Video/V8: U6.12 (MA8), U8.6 (I1b), U10.6 (I1b)
/Video/V9: U6.13 (MA9), U8.3 (I1a), U10.10 (I1d)
/Video/V10: U6.14 (MA10), U8.13 (I1c), U10.13 (I1c)
/Video/V/~C: U5.1 (S), U7.1 (S), U8.1 (S), U9.1 (S), U10.1 (S), U32.3
/~40Z: R1.1, U1.13 (P10/TIN2), U23.13, U30.9
/~CEROM: U3.9 (O3), U4.22 (~OE)
/~CRT: U3.6 (O2), U6.25 (~CS)
/~E: U6.21 (CLK), U31.11, U33.1, U33.2
/~GRAM: U3.10 (O2), U13.19 (CE), U18.13, U32.1
/~IRQ: R23.2, U1.5 (~IRQ1)
/~LD: U14.1 (~PL), U17.3 (C), U17.11 (C), U18.5, U18.10, U21.1 (~PL), U24.3 (C), U31.6
/~RST: U1.6 (~RST), U6.2 (~RESET), U23.8
/~TRAM: U3.11 (O1), U18.2, U20.19 (CE), U32.2
/~WR: U18.1, U18.12, U33.11
GND: C3.1, C4.1, C5.1, C6.2, C7.2, C8.2, C9.2, C10.2, C13.2, C14.2, C15.2, C16.2, C18.2, C19.2, C20.2, C23.2, C24.2, C25.2, C26.2, C27.2, C28.2, C29.2, C30.2, Q1.3 (E), Q2.3 (E), Q3.3 (E), R1.2, R3.2, R9.2, R13.2, R14.2, R16.2, R19.2, U1.1 (GND), U1.2 (XTAL), U1.9 (P21/TOUT1), U2.1 (OE), U2.10 (GND), U3.8 (GND), U4.14 (GND), U4.20 (~CE), U5.8 (GND), U5.15 (OE), U6.1 (GND), U6.3 (LPSTB), U7.8 (GND), U7.15 (OE), U8.8 (GND), U8.10 (I1d), U8.15 (OE), U9.8 (GND), U9.15 (OE), U10.8 (GND), U10.15 (OE), U11.7 (GND), U12.7 (GND), U13.10 (GND), U14.8 (GND), U14.10 (DS), U14.15 (~CE), U15.14 (VSS), U15.22 (~OE), U16.14 (VSS), U16.22 (~OE), U17.7 (GND), U18.7 (GND), U19.14 (VSS), U19.20 (~CS1), U19.22 (~OE), U20.10 (GND), U21.8 (GND), U21.10 (DS), U21.11 (D0), U21.12 (D1), U21.15 (~CE), U22.12 (GND), U22.18 (~CE), U22.20 (~OE/VPP), U23.7 (GND), U24.7 (GND), U25.4, U25.5, U25.7 (GND), U26.7 (GND), U26.12 (Mr1), U26.13 (Mr2), U27.7 (GND), U28.7 (GND), U29.7 (GND), U30.7 (GND), U31.7 (GND), U32.7 (GND), U33.7 (GND)
unnamed: C6.1, R24.1, U23.1, Y1.1
unnamed: C7.1, R24.2, R25.1, Y1.2
unnamed: C9.1, R12.2, R13.1, U23.11
unnamed: C5.2, R10.1, R11.1
unnamed: Q1.1 (C), R2.2
unnamed: Q2.2 (B), R4.2
unnamed: C10.1, R15.2, U31.1, U31.13
unnamed: R16.1, R17.2, R18.1
unnamed: R21.2, R22.2
unnamed: U1.39 (SC1/AS), U25.9, U25.10
unnamed: Q1.2 (B), R6.1
unnamed: Q3.2 (B), R8.1, R9.1
unnamed: Q4.2 (B), R18.2
unnamed: Q4.3 (E), R19.1, R20.1
unnamed: R22.1, U32.6
unnamed: R25.2, U23.2, U23.3
unnamed: U3.1 (E), U3.12 (O0)
unnamed: U6.39 (HS), U31.10
unnamed: U6.40 (VS), U31.9
unnamed: U11.2, U30.11
unnamed: U11.3, U32.5
unnamed: U11.6, U32.9
unnamed: U12.3, U30.13
unnamed: U12.5, U32.8
unnamed: U12.6, U30.12
unnamed: U11.11, U16.20 (~CS1)
unnamed: U11.4, U17.5 (Q)
unnamed: U17.9 (Q), U32.4, U32.13
unnamed: U23.4, U23.5
unnamed: U23.12, U30.1
unnamed: U18.9, U24.5 (Q)
unnamed: U24.4 (~S), U32.11
unnamed: U11.1, U24.9 (Q)
unnamed: U18.6, U24.13 (~R)
unnamed: U18.8, U24.10 (~S)
unnamed: U25.1, U25.2, U31.8
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

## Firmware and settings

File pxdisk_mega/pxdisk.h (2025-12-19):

// pxdisk.h
/// Based on pxDisk copyright(c) 2019 William R Cooke

bool console = false; //true;

#if defined(__AVR_ATmega1280__) || defined(__AVR_ATmega2560__)
// On the Arduino Mega the SD-Card is on:
// 50 MISO
// 51 MOSI
// 52 SCK
// 53 CS
#define BOARD_MEGA
#define BOARDTEXT       "Mega2560"
#define PXPORT          Serial2    // pin 16 & 17
#define DEBUG           true       // Change to true for debugging
#define DEBUGPORT       Serial     // pin 0 & 1 and USB port
#define CS_PIN          53         // SD card CS pin
#define D_LED            9
#define E_LED           10
#define F_LED           11
#define G_LED           12
#define DEBUGLED        13
#endif

// The Pro Micro is equal to the Micro or Leonardo but smaller (and cheaper)
#if defined(__AVR_ATmega32U4__)
#define BOARD_MICRO
#define BOARDTEXT       "Pro_Micro"
#define PXPORT          Serial1    // pin 0 & 1
#define DEBUG           false //true       // Change to true for debugging
#define DEBUGPORT       Serial     // USB port
#define CS_PIN          A3         // SD card CS pin
#define D_LED            2
#define E_LED            3
#define F_LED            4
#define G_LED            5
#define DEBUGLED         17
#endif

#define MAX_TEXT   128

#define DEBUGBAUDRATE 115200
//#define PXBAUDRATE    38400
#define PXBAUDRATE    76800

//////////////////////////////////////////////////////////////////////////////
///  Special characters used by the state machine.
//////////////////////////////////////////////////////////////////////////////
enum Characters
{
  C_SOH     =  0x01,         /// < Start of Header
  C_STX     =  0x02,         /// < Start of Text
  C_ETX     =  0x03,         /// < End of Text
  C_EOT     =  0x04,         /// < End of Transmission
  C_ENQ     =  0x05,         /// < Enquiry
  C_ACK     =  0x06,         /// < Acknowledge
  C_NAK     =  0x15,         /// < Negative Acknowledge
  C_FMT_MS  =  0x00,         /// < Format message from Master to Slave
  C_FMT_SM  =  0x01,         /// < Format message from Slave to Master
  C_SEL     =  0x31,         /// < Select command
};

const byte MY_ID_1 = 0x31;    /// < Id of first drive unit
const byte MY_ID_2 = 0x32;    /// < Id of second drive unit

//////////////////////////////////////////////////////////////////////////////
///  Device IDs that are relevant
//////////////////////////////////////////////////////////////////////////////
enum DeviceID
{
  ID_HX20   = 0x20,
  ID_PX8    = 0x22,
  ID_PX4    = 0x23,
  ID_FD1    = 0x31,
  ID_FD2    = 0x32,
};

//////////////////////////////////////////////////////////////////////////////
///  States used by the state machine.
//////////////////////////////////////////////////////////////////////////////
enum States
{
  ST_BEGIN,       /// < Starting State                             :0     
  ST_IDLE,        /// < Returns to IDLE after all major blocks     :1
  ST_PS_POL,      /// < Received POLL from IDLE (not used)         :2
  ST_PS_SEL,      /// < Received SELECT from IDLE                  :3
  ST_PS_DID,      /// < Received Destination ID after SELECT       :4
  ST_PS_SID,      /// < Received Source ID after Destination ID     5
  ST_PS_ENQ,      /// < Received Enquiry after Source ID            6
   
  ST_HD_SOH,      /// < Received SOH from IDLE                      7
  ST_HD_FMT,      /// < Received Format character after SOH         8
  ST_HD_DID,      /// < Received Destination ID after Format        9
  ST_HD_SID,      /// < Received Source ID after Destination ID    10
  ST_HD_FNC,      /// < Received Function code after Source ID     11
  ST_HD_SIZ,      /// < Received Text Size after Function code     12
  ST_HD_CKS,      /// < Received header Checksum after Size        13

  ST_TX_STX,      /// < Received STX from IDLE                     14
  ST_TX_TXT,      /// < Received SIZ bytes of Text after STX       15
  ST_TX_ETX,      /// < Received ETX after Text                    16
  ST_TX_CKS,      /// < Received Text Checksum after ETX           17
  ST_TX_ACK,      /// <                                            18

  ST_SENT_HDR,    /// < Header was sent to Master                  19
  ST_SENT_TXT,    /// < Text was sent to Master                   :20
  
  ST_ERR,         /// < An error occurred in the state machine    :21 
  ST_UNDEFINED    /// < An undefined state -- should never happen :22
};

int oldState = ST_UNDEFINED; // Used to report state before ST_ERR

//////////////////////////////////////////////////////////////////////////////
///  Functions codes used in CP/M disk systems
//////////////////////////////////////////////////////////////////////////////
enum Functions
{
 FN_DISK_RESET          = 0x0d,    /// < RESET?
 FN_DISK_SELECT         = 0x0e,    /// < SELECT?
 FN_OPEN_FILE           = 0x0f,    /// < Opens a file to read
 FN_CLOSE_FILE          = 0x10,    /// < Closes file
 FN_FIND_FIRST          = 0x11,    /// < Find First
 FN_FIND_NEXT           = 0x12,    /// < Find First
 FN_CREATE_FILE         = 0x16,    /// < Creates file
 FN_RANDOM_READ         = 0x21,    /// < 
 FN_RANDOM_WRITE        = 0x22,    /// < 
 FN_COMPUTE_FS          = 0x23,    /// < Compute Filesize
 FN_DISK_READ_SECTOR    = 0x77,    /// < Read a single 128 byte sector
 FN_DISK_WRITE_SECTOR   = 0x78,    /// < Write a single 128 byte sector
 FN_DISK_WRITE_HST      = 0x79,    /// < CP/M WRITEHST flushes buffers
 FN_DISK_COPY           = 0x7a,    /// < Copy a complete disk -- not used
 FN_DISK_FORMAT         = 0x7c,    /// < Format a blank disk  -- not used
 FN_DISK_BOOT           = 0x80,    /// < Send BOOT.SYS
 FN_LOAD_OPEN           = 0x81,    /// < Relocate DBASIC.SYS
 FN_READ_BLOCK          = 0x83,    /// < Send DBASIC.SYS
 FN_IMAGE_CMDS          = 0xE0,    /// < Commands managing disk images
};

//////////////////////////////////////////////////////////////////////////////
///  BDOS return codes from BIOS disk functions 
//////////////////////////////////////////////////////////////////////////////
enum BDOS_ReturnCodes
{
  BDOS_RC_SUCCESS         = 0,       /// < Successful Completion
  BDOS_RC_READ_ERROR      = 0xfa,    /// < Disk Read Error
  BDOS_RC_WRITE_ERROR     = 0xfb,    /// < Disk Write Error
  BDOS_RC_SELECT_ERROR    = 0xfc,    /// < Disk Select Error
  BDOS_RC_DISK_WP_ERROR   = 0xfd,    /// < Disk Write Protect Error
  BDOS_RC_FILE_WP_ERROR   = 0xfe,    /// < Disk Write Protect Error
};
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

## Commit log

2025-04-19 new upload
    [EVA1.kicad_pcb, EVA1.kicad_sch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]
2025-05-11 new functions in assembly
2025-05-12 new schematic added, documentation added
    [EVA1_v2.kicad_pcb, EVA1_v2.kicad_sch, GRAM.kicad_sch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]
2025-06-01 assemble script updated, documentation is now as pdf avail.
2025-06-02 schematics updated
    [EVA1_v2.kicad_pcb, EVA1_v2.kicad_sch, GRAM.kicad_sch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]
2025-06-02 schematics backup cleaned
2025-11-07 New version for production
    [EVA1_Frontplatte.kicad_pcb, EVA1_Frontplatte.kicad_sch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]
2025-11-07 BOM added
    [EVA1_v2.kicad_pcb, EVA1_v2.ods]
2025-11-07 BOM updated
    [EVA1_v2.ods]
2025-12-04 BOM updated, GAL eq. updated
    [EVA1_v2.ods]
2025-12-04 Schematic and Board updated
    [EVA1_v2-B_Cu.gbr, EVA1_v2-B_Mask.gbr, EVA1_v2-B_Paste.gbr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]
2025-12-06 pics added, Readme udated
    [EVA1_v2.ods]
2025-12-15 new Gerber files
    [EVA1_v2-B_Cu.gbr, EVA1_v2-B_Mask.gbr, EVA1_v2-B_Paste.gbr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]
2025-12-19 firmware for arduino and rp2040 added
